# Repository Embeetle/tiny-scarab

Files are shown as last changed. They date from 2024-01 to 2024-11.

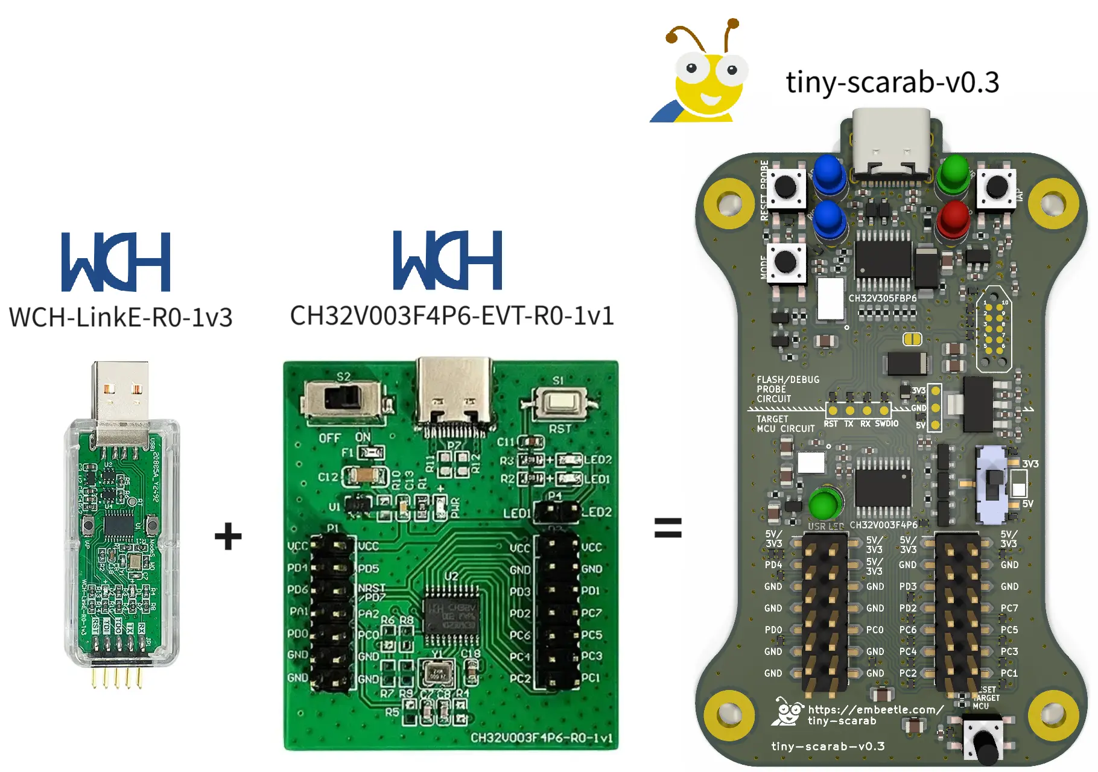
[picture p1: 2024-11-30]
documentation/website_figures/probe_and_board_merge.webp

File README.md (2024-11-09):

# Tiny Scarab

The Tiny Scarab is an open-source development board built around the popular 10 cent `CH32V003F4P6` RISC-V microcontroller from WCH. Using this dev board is uncomplicated: just plug it into your computer with a USB-C cable, and you're ready to code - the flasher/debugger is already embedded in the board for your convenience. Now you might wonder - why yet another dev board? Aren't there thousands already?



Well - this dev board is presented to you with a new coding IDE. Not satisfied with the current offering of IDEs for microcontrollers, we created a brand new one from scratch: <a href="https://embeetle.com/" target="_blank"> Embeetle IDE</a>. With the Tiny Scarab and Embeetle IDE, you'll discover how smooth programming a microcontroller can be.

>  This open-source dev board is developed in collaboration with the <a href="https://devheads.io/" target="_blank"> DevHeads</a> community. Please join the <a href="https://discord.gg/devheads">DevHeads Discord channel</a> if you want to know more about this Tiny Scarab board, Embeetle IDE or any other topic related to hardware and embedded software. We're waiting for you on the server!

&nbsp;<br>
# Overview

The Tiny Scarab is based on the 10-cent RISC-V `CH32V003F4P6` MCU from WCH:



The Tiny Scarab board merges the <a href="https://embeetle.com/#supported-hardware/wch/probes/wch-linke-r0-1v3" target="_blank">`WCH-LinkE-R0-1v3`</a> flash/debug probe and the <a href="https://embeetle.com/#supported-hardware/wch/boards/ch32v003f4p6-evt-r0-1v1" target="_blank">`CH32V003F4P6-EVT-R0-1v1`</a> board into a single development board:

comparison

There's no need to wire up anything. Just plug the Tiny Scarab's USB-C port in your computer, fire up Embeetle IDE and start coding!

&nbsp;<br>
# Index

- **Hardware**
  - [Download Tiny Scarab Schematic](tiny-scarab.pdf)
  - [Open Tiny Scarab in KiCAD](documentation/readme_open_project.md)
  - [A Deeper Dive in the KiCAD Files](documentation/readme_deeper_dive_kicad_files.md)
  - [Tiny Scarab Pinout and Features](documentation/readme_pinout_and_features.md)
  - [Tiny Scarab vs CH32V003F4P6-EVT-R0-1v1 - a Comparison](documentation/readme_compare.md)
  - [Production Files](documentation/production_files.md)

- **Software**
  - [Flash/Debug Probe Firmware](documentation/readme_flash_debug_probe_firmware.md)
  - [Target MCU Firmware](documentation/readme_target_mcu_firmware.md)

NOTES FOR MYSELF
================
Improvement points:
- Bulges in encasing don't fit board. (fixed)
- Tag Connect needs a recess in the enclosure. (fixed)
- Light bleeds between lightpipes. Lightpipes and LEDs too expensive. (fixed)
- Graphical membrane needs 1.2mm edge. (fixed)
- 3/5V indication on board is wrong. On graphical membrane it's correct. (fixed)

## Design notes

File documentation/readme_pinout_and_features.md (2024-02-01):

<a href="../README.md">open_project_01 HOME</a>

# Tiny Scarab Pinout and Features

## 1. Power System
The Tiny Scarab draws 5V power from its USB-C connector:



&nbsp;<br>
The 5V power rail is protected in several ways:



Let's go over all the safety measures.

&nbsp;<br>
### 1.1 ESD Protection
TVS diode `TVS3` (`SMAJ5.0A`) protects the board from incoming voltage transients and ESD discharges on the 5V line:



&nbsp;<br>
### 1.2 Overvoltage Protection
The TVS diode is ideal for short voltage transients - like an ESD discharge. But what about permanent overvoltage incidents? What if a faulty USB-C charger outputs 20V on the `VBUS` line? In that case, fuse `F1` (`MFU0603FF02000P500`) cooperates with zener diode `D1` (`1SMA4734A`) to protect the board:



Sometimes a faulty USB-C charger can output 20V on the `VBUS` line, even though it never negotiated this with the device on the receiving end. It shouldn't happen ... but when it does you don't want the board to go up in flames! Zener diode `D1` has a zener voltage of 5V6, so it will draw a lot of current in this particular case. Fuse `F1` blows, interrupting the current flow to prevent further damage.

&nbsp;<br>
### 1.3 Overcurrent Protection
Chip `U1` (`AP2141WG-7`) limits the current flow to the whole board at 500mA. This limit ensures that any PC can drive the board risk-free:



There's already a 2A fuse on the 5V line. Why don't we remove this `U1` chip and just reduce the 2A fuse to 500mA?

> open_project_01Fuse `F1` and current-limiting chip `U1` serve an entirely different purpose. Fuse `F1` (in collaboration with zener diode `D1`) protects the board from permanent overvoltage incidents. Replacing fuse `F1` with a 500mA version isn't a good idea because the on-resistance would be too high. Leaving out the fuse and only relying on current-limiting chip `U1` isn't smart either - a fuse is just perfect because of its simplicity and robustness. Summarized, the roles of fuse `F1` and chip `U1` are:
> - Fuse `F1`: simple and robust, ideal for the overvoltage incident described earlier.
> - Chip `U1`: more sophisticated, will limit current to 500mA while keeping a low on-resistance.

&nbsp;<br>
### 1.4 Power Indicator LEDs
The board has two LEDs to indicate the status of the 5V power input:



The `PWR` LED simply shows if 5V power is present on the board. The `ERR` LED lights up if the overcurrent protection chip `U1` reports a fault condition.

&nbsp;<br>
### 1.5 Voltage Conversion
Parts of the board - such as the flash/debug probe - operate on 3V3. So we need to create that voltage from the 5V rail:



The target MCU is a special case. It can operate on 5V *or* 3V3. Both voltages are present on the board, so it's easy to feed the chip with one or the other. To give you the choice, we added a slide switch:



Now, it's challenging to find a cheap slide switch that can carry 500mA and is readily available in the JLCPCB stock. For that reason, the slide switch simply toggles a few MOSFETs. In other words: the current doesn't flow through the slide switch, but through these MOSFETs instead. [Download the schematic](../tiny-scarab.pdf) to see more.

&nbsp;<br>
## 2. Pinout

Almost all pins of the target `CH32V003F4P6` MCU are accessible through the pin headers at the bottom of the board:



There are a few exceptions though. Signals `SWDIO_CH32V003` and `RST_CH32V003` (tied to pins `PD1` and `PD7`) are used to flash code to the target chip and run debug sessions. Also signals `RX` and `TX` (tied to pins `PD5` and `PD6`) are occupied. They are routed to the on-board flash/debug probe to provide UART communication:



Also pins `PA1` and `PA2` are not accessible on the pin headers. These are clock pins, routed to the crystal.

&nbsp;<br>
## 3. LEDs

[UNDER CONSTRUCTION]

&nbsp;<br>
## 4. Switches and Buttons

[UNDER CONSTRUCTION]

&nbsp;<br>
<a href="../README.md#index"> GO BACK</a>

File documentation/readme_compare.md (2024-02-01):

<a href="../README.md">open_project_01 HOME</a>

# Tiny Scarab vs CH32V003F4P6-EVT-R0-1v1 - a Comparison

With a few exceptions, the Tiny Scarab pinout is identical to the `CH32V003F4P6-EVT-R0-1v1` development board:



The exceptions are:

- Pins `PA1` and `PA2` are used to drive the crystal. The `CH32V003F4P6-EVT-R0-1v1` board still breaks them out to the pin headers, but you then have to remove the crystal and solder two 0R resistors. We don't expect our users will make any modifications to the board, so we decided to leave out that option. The corresponing pins on the pin headers are just tied to `GND`.

- Pins `PD1`, `PD5`, `PD6` and `PD7` are connected to the `CH32V305FBP6` chip for flash and debug purposes (the `CH32V305FBP6` is the heart of the on-board `WCH-LinkE-R0-1v3` flash/debug probe). It is safer not to connect them to the pin headers.

&nbsp;<br>
<a href="../README.md#index"> GO BACK</a>

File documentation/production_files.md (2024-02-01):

<a href="../README.md"> HOME</a>

# Production Files

This board is designed with JLCPCB in mind for the production. That's why all components are selected to be in stock or at least accessible at <a href="https://jlcpcb.com/" target="_blank">JLCPCB</a>. In the schematic, you'll notice that each component has a `JLCPCB Part #` field:



Based on this part number, JLCPCB knows which exact component to select from its stock. On this page, we cover how to output all the required production files from this KiCAD project for manufacturing the board at JLCPCB - both the board production and assembly.

>  Note: as you can see, not only the `JLCPCB Part #` field is provided for each component. We also added fields for other distributors, like `DigiKey`, `Farnell` and `Mouser`.

&nbsp;<br>
## 1. Install JLCPCB Plugin

First install the JLCPCB plugin in KiCAD:



&nbsp;<br>
Search for the `"JLC PCB Fabrication Toolkit"`:



&nbsp;<br>
Install the plugin.

&nbsp;<br>
## 2. Generate Production Files

Once you've installed the JLCPCB plugin, you should see a new button in the PCB Layout Window:



&nbsp;<br>
This button replaces the usual workflow to generate production files. In other words, do not generate files from `File` > `Fabrication Outputs`:



&nbsp;<br>
Just click the new JLCPCB button instead. You'll be prompted the following question:



Make sure to check the `"Exclude DNP components"` box. "DNP" stands for "Do Not Place". By checking this box, you ensure that the components marked as "DNP" are indeed not placed on the board.

&nbsp;<br>
The KiCAD plugin should now create a new folder named `production` in the Tiny Scarab project. This is all you need for production at the JLCPCB manufacturing plant.

&nbsp;<br>
<a href="../README.md#index"> GO BACK</a>

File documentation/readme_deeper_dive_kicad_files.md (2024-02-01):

<a href="../README.md"> HOME</a>

# A Deeper Dive in the KiCAD Files

All the files in this GitHub repository work together to create the entirety of the KiCAD project. Roughly speaking, these files can be grouped in four categories:

open_project_01

&nbsp;<br>
##  KiCAD Component Library

KiCAD libraries come in two kinds: global and project libraries.
 - Global libraries are available for each and every project you work on. Let's not mess with them.
  - For the customized components, we created a project library: `Tiny_Scarab.kicad_sym`. When you launch the Tiny Scarab project in KiCAD, the software should automatically recognize the presence of this project library and find all the components inside. To keep things simple, all the customized components are located in this one project library.

The project library is stored in the file `Tiny_Scarab.kicad_sym`. Well, that is, all the schematic symbols are stored in there with their footprint *references*. The footprints themselves are located in the `Tiny_Scarab.pretty` folder. The 3D models from these footprints are in the `3d_models` folder. So you could state that these three items together (the `Tiny_Scarab.kicad_sym` file, the `Tiny_Scarab.pretty` folder and the `3d_models` folder) compose our project library.

Then what are the `fp-lib-table` and `sym-lib-table` files for? They simply help KiCAD to know where to find the footprints and symbols from (one or more) project libraries. In our KiCAD project, it's pretty simple because there's only a single project library. But these two files come in handy if things would be more complicated.

&nbsp;<br>
##  KiCAD Schematic Pages

The Tiny Scarab KiCAD project consists of several schematic pages. The root page is `tiny-scarab.kicad_sch` - it has the same name as the project file `tiny-scarab.kicad_pro` (which represents the entire project). Then there is the `USB.kicad_sch`, `WCH-LinkE-R0-1v3.kicad_sch` and two more. You can view these pages from within the Schematic Editor in KiCAD:



&nbsp;<br>
> *Note: in the most recent version of the Tiny Scarab, you'll notice a few extra schematic pages.*

&nbsp;<br>
##  KiCAD PCB Layout

The PCB Layout is stored in a single file: `tiny-scarab.kicad_pcb`.

&nbsp;<br>
##  KiCAD Project

The entire KiCAD project is represented by `tiny-scarab.kicad_pro`. This file tells KiCAD how to open the project and where to find all the files.

&nbsp;<br>
<a href="../README.md"> GO BACK</a>

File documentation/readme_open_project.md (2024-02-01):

<a href="../README.md">open_project_01 HOME</a>

# Open Tiny Scarab Project in KiCAD

The Tiny Scarab development board is designed in KiCAD - a free and open-source tool to draw professional circuit boards. On this page I explain how to open the Tiny Scarab dev board project in KiCAD.

&nbsp;<br>
## STEP 1: Clone or Download Tiny Scarab

First you need to clone or download the Tiny Scarab GitHub repository. Navigate back to <a href="../README.md">the homepage</a>, then click the green `<> Code` button and copy the GitHub URL or just download the zip folder:

open_project_01

If you copied the GitHub URL, you can then clone it to your local computer like this:

```sh
$ git clone https://github.com/Embeetle/tiny-scarab.git
```

If you downloaded the zip-folder - just unzip it.

&nbsp;<br>
## STEP 2: Download KiCAD

Make sure you have `KiCAD v7` or higher. Download and install the software from here:
<a href="https://www.kicad.org/" target="_blank">https://www.kicad.org/</a>

open_project_02

&nbsp;<br>
## STEP 3: Launch KiCAD

Launch KiCAD. First window you see is the **KiCAD Home Window**. Click `File` > `Open Project...` and select the `tiny-scarab.kicad_pro` file from the GitHub repository you just downloaded or cloned in STEP 1:

open_project_03

open_project_04

&nbsp;<br>
That's it. Now you can work in the **Tiny Scarab** project in KiCAD:

open_project_05

&nbsp;<br>
<a href="../README.md"> GO BACK</a>

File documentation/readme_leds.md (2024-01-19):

<a href="../README.md"> HOME</a>

# LEDs

 The CSL Series from Rohm Semicon (see https://www.rohm.com/products/led/chip-leds-mono-color-type) is a series of 0603 SMD LEDs with a lens for extra luminosity.

## 1. CSL Series Product Code

```
┌─────────────┐     ┌────────┐   ┌────────┐   ┌───┐   ┌───┐
│ C    S    L │  -  │ 0    9 │   │ 0    2 │   │ B │   │ T │
└──┬──────────┘     └─┬──────┘   └─┬──────┘   └─┬─┘   └─┬─┘
  series           package       brightness   color    resin color
                   1.6x0.8mm     03>02>01     U:Red    T:Transparent
                   t=1.24mm                   D:Orange
                                              Y:Yellow
                                              M:Yellow-Green
                                              E:Green
                                              B:Blue
                                            
```

## 2. Table

| part | color | mcd  | luminous classification | I<sub>F</sub> @ V<sub>F</sub> | I<sub>F</sub> @ V<sub>F</sub> | Mouser | Farnell |
|---|---|---|---|---|---|---|---|
| `CSL0902UT` | RED | 355  | AZ>AY>AX>AW | `20mA` @ `2V1 [1V8-2V5]` | `10mA` @ `2V0` | `755-CSL0902UT1` | 3954422 |
| `CSL0902DT` | ORANGE | 560  | BB>BA>AZ>AY | `20mA` @ `2V1 [1V8-2V5]` | `10mA` @ `2V0` | `755-CSL0902DT1` | 4129804 |
| `CSL0902MT` | YELLOW-GREEN | 180  | AW>AV>AU>AT | `20mA` @ `2V1 [1V8-2V5]` | `10mA` @ `2V0` | `755-CSL0902MT1` | 4129806 |
| `CSL0902ET` | GREEN | 1100 | Y1>X2>X1>W2 | `20mA` @ `3V4 [2V6-3V8]` | `10mA` @ `3V2` | `755-CSL0902ET1` | 4129807 |
| `CSL0902BT` | BLUE | 360  | V2>V1>U2>U1 | `20mA` @ `3V3 [2V6-3V8]` | `10mA` @ `3V1` | `755-CSL0902BT1` | 3954417 |

&nbsp;<br>
<a href="../README.md"> GO BACK</a>

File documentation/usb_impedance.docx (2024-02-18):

# USB Impedance

In a differential pair, there exists four kinds of characteristic impedance:

- Single-ended impedance ( Z_(se) ): The impedance of the single trace in isolation, when it's excited by a signal between the trace and the ground plane. In single-ended signaling, this is the only kind of impedance.
- Odd-mode impedance ( Z_(odd) ): The impedance of the single trace in a differential pair, when the differential pair as a whole is excited by a differential-mode (out of phase) signal.
- Even-mode impedance ( Z_(even) ): The impedance of the single trace in a differential pair, when the differential pair as a whole is excited by a common-mode (in phase) signal.
- Differential impedance ( Z_(diff) ): The impedance of the entire differential pair as a whole (two traces), when the differential pair as a whole is excited by a differential-mode (out of phase) signal. By definition, it's always 2⋅Zodd.

https://electronics.stackexchange.com/questions/311310/understanding-usb-differential-and-single-ended-impedance-requirements

In the context of USB signal routing on a printed circuit board (PCB), differential pairs are used to transmit data signals. These pairs consist of two conductive traces that carry the same signal but with opposite polarities, which helps to reduce noise and electromagnetic interference (EMI), improving signal integrity. The way these differential pairs are routed—whether as tightly-coupled or loosely-coupled—can significantly affect their performance. Here's a detailed explanation of both concepts:

### Tightly-Coupled Differential Pairs

- **Definition:** In tightly-coupled differential pairs, the two traces are placed very close to each other relative to their distance from the reference plane (usually a ground or power plane within the PCB). This close proximity enhances the coupling between the traces.

- **Benefits:** The strong electromagnetic coupling between the traces in a tightly-coupled pair reduces the impact of external noise and EMI, making them more immune to interference. It also decreases the differential impedance and increases the phase velocity of the signal, which can be beneficial for maintaining signal integrity over longer distances.

- **Design Considerations:** To achieve tight coupling, designers must consider the trace width, the spacing between the traces, and the thickness of the PCB substrate. The goal is to maintain a consistent impedance while minimizing the space the pair occupies on the PCB. This often requires precise control over the manufacturing process to ensure that the spacing and widths remain within tight tolerances.

- **Applications:** Tightly-coupled differential pairs are typically used in high-speed data communication applications where signal integrity is critical, such as USB 3.0/3.1, HDMI, and Ethernet.

### Loosely-Coupled Differential Pairs

- **Definition:** Loosely-coupled differential pairs have a greater distance between the two traces compared to their distance from the reference plane. This results in weaker electromagnetic coupling between the traces.

- **Benefits:** Loosely-coupled pairs are easier to route on PCBs, especially in complex designs where space is a constraint or when traces need to navigate around obstacles. They are less susceptible to manufacturing variations since the wider spacing is more tolerant to deviations in trace width or spacing.

- **Design Considerations:** While easier to implement, loosely-coupled pairs may require additional design considerations to maintain signal integrity, such as impedance matching and controlling the length of the traces to prevent timing mismatches. The reduced coupling can make them more susceptible to external noise and EMI.

- **Applications:** Loosely-coupled differential pairs are often used in applications where the speed of the data transmission is lower, or the design complexity and PCB real estate do not allow for tightly-coupled routing. They can still be effective in USB 2.0 and other lower-speed interfaces.

### Conclusion

The choice between tightly-coupled and loosely-coupled differential pairs depends on the specific requirements of the USB interface (such as the data rate), the available PCB space, and the desired resilience against noise and EMI. Tightly-coupled pairs are generally preferred for high-speed data transmission due to their superior signal integrity, but they require more precise manufacturing and design. Loosely-coupled pairs offer more flexibility in routing and are more tolerant to manufacturing variations, making them suitable for lower-speed or more complex PCB designs.

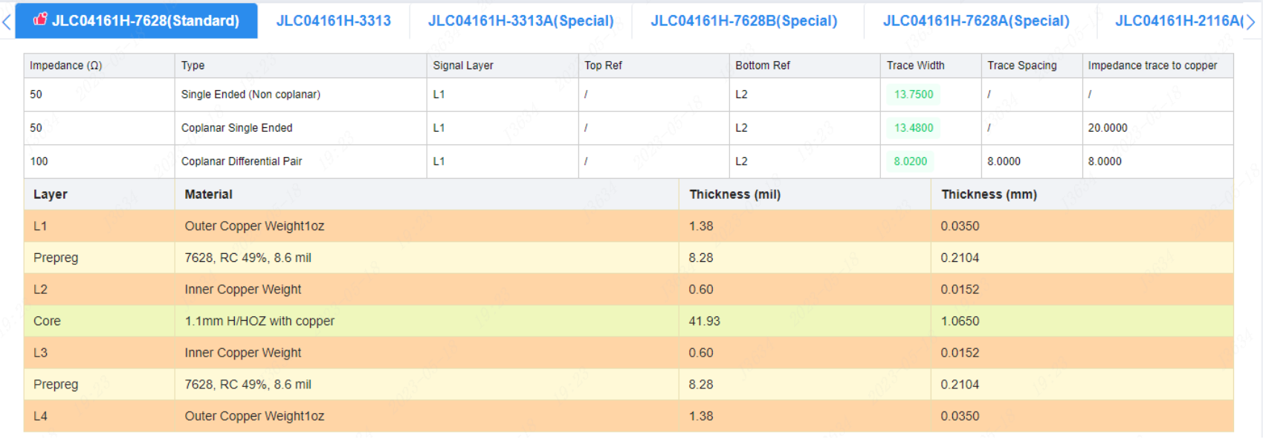
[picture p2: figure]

(Prepreg 7628 has a relative permittivity ϵr around 4.6, assuming standard FR-4 material unless specified otherwise)

When designing a PCB with JLCPCB and using their standard FR4 material (Tg 140C), it's important to note that this material is widely used in the industry and typically has a dielectric constant (ϵr) around 4.3 to 4.8 for frequencies relevant to USB signal transmission. For our calculations and considerations, we'll use an average value of 4.6, which is a common approximation for FR4 material unless JLCPCB provides a specific dielectric constant value for their FR4-Standard Tg 140C material.

I have a 4-layer PCB with the following stackup:

```

L1 Copper: 0.035mm thick

Prepreg: 0.2104mm thick

L2 Copper: 0.0152mm thick

Core Material: 1.065mm thick

L3 Copper: 0.0152mm thick

Prepreg: 0.2104mm thick

L4 Copper: 0.035mm thick

```

Assume the permittivity of the Prepreg and Core Material to be 4.6.

The manufacturing constraints are:

- Minimal trace width: 0.2mm

- Minimal spacing between traces: 0.2mm

I want to route a differential pair of USB signals. I will put them on layer L2 and sandwich them between a GND plane on layer L1 and a GND plane on layer L3.

If the USB signals have a width of 0.2mm and are spaced 0.2mm apart, what would be their differential impedance?

To calculate the differential impedance of a differential pair of USB signals with the given stackup and constraints, we can use an appropriate model or formula for differential pairs. One commonly used approximation for differential impedance (\(Z_{diff}\)) of a pair of traces in a PCB is given by:

\[ Z_{diff} = 2 \times Z_0 \times \sqrt{1 + \frac{d}{s + 2h}} \]

where:

- \(Z_0\) is the single-ended impedance of one trace,

- \(d\) is the distance between the centers of the two traces (i.e., the sum of the trace width and the spacing between the traces),

- \(s\) is the spacing between the traces, and

- \(h\) is the height of the dielectric material above the reference plane.

First, we need to calculate the single-ended impedance (\(Z_0\)) of one trace using the microstrip model, as the differential pair is routed on layer L2 with ground planes on both L1 and L3. The formula for the impedance of a microstrip is more complex and depends on the width of the trace (\(W\)), the thickness of the dielectric (\(H\)), the permittivity of the dielectric (\(\epsilon_r\)), and other factors. A simplified version of the formula can be:

\[ Z_0 = \frac{87}{\sqrt{\epsilon_r+1.41}} \cdot \ln\left( \frac{5.98H}{0.8W + T} \right) \]

where:

- \(W\) is the trace width,

- \(H\) is the height above the reference plane (thickness of the dielectric),

- \(T\) is the thickness of the trace, and

- \(\epsilon_r\) is the relative permittivity of the dielectric material.

Given:

- \(W = 0.2\,mm\) (trace width),

- \(H = 0.2104\,mm\) (thickness of the Prepreg above L2),

- \(T = 0.0152\,mm\) (thickness of L2 Copper),

- \(\epsilon_r = 4.6\) (permittivity of the Prepreg and Core Material),

- \(s = 0.2\,mm\) (spacing between the traces).

Let's calculate the single-ended impedance (\(Z_0\)) and then the differential impedance (\(Z_{diff}\)).

The calculated single-ended impedance (\(Z_0\)) of one trace is approximately \(30.39 \, \Omega\), and the differential impedance (\(Z_{diff}\)) of the USB signal pair, with each having a width of \(0.2 \, mm\) and spaced \(0.2 \, mm\) apart, is approximately \(77.93 \, \Omega\).

This differential impedance is within the typical range for USB differential pair signaling, which often aims for around \(90 \, \Omega\) in differential impedance, but variations can be acceptable depending on the specific USB standard and the tolerances allowed by the system design.

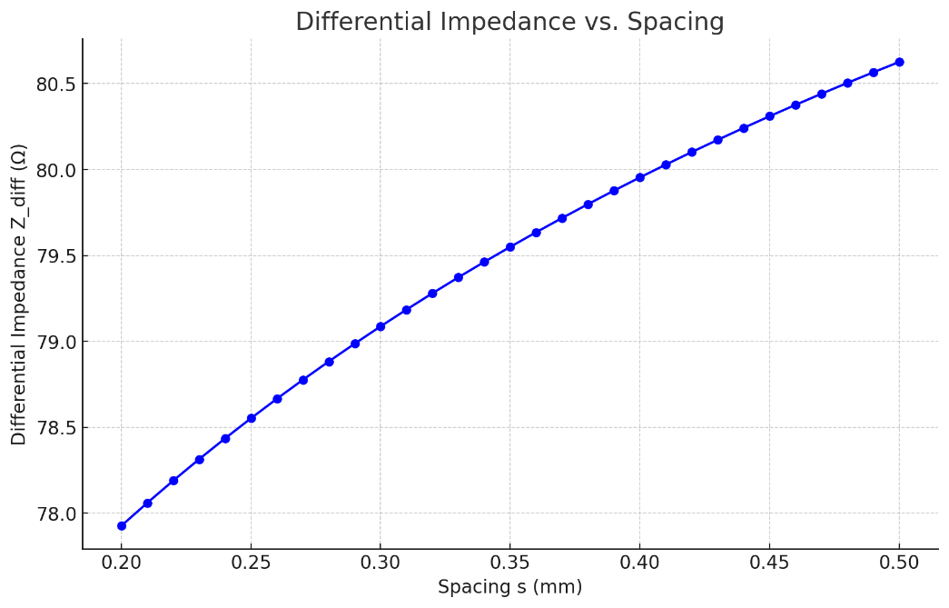
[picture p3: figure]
Output image
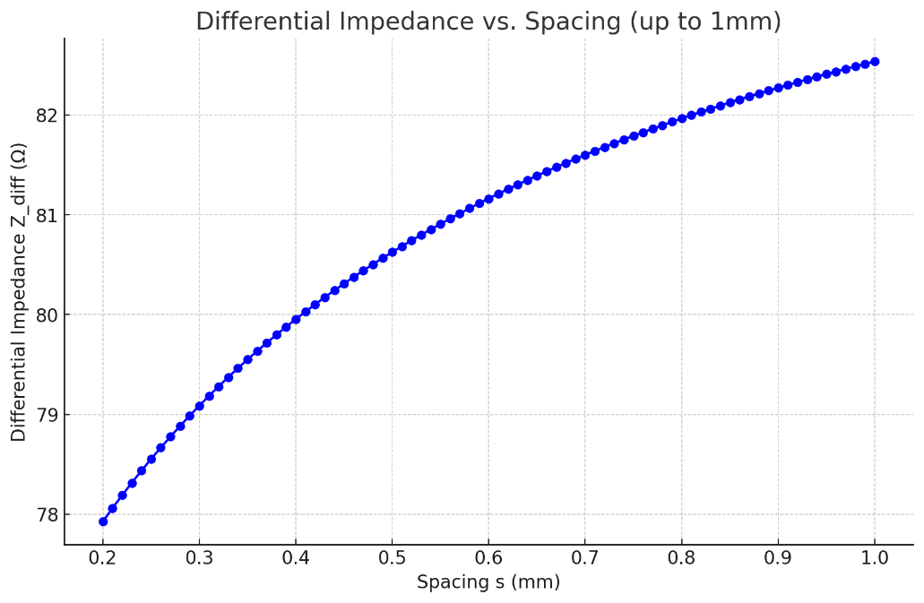
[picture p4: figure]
Output image

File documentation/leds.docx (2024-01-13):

# Tiny Scarab LEDs

The LEDs on the Tiny Scarab board have these characteristics:

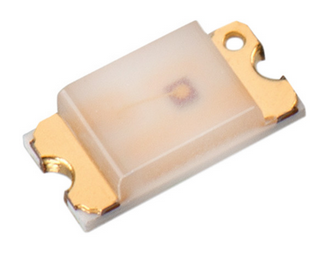
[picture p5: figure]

- Manufacturer: Würth Elektronik
- Package: 0603 SMD
- Lens: Diffused
- Viewing Angle: 140 deg

# Green

MPN: 150060GS55040
SPN: 732-12014-2-ND

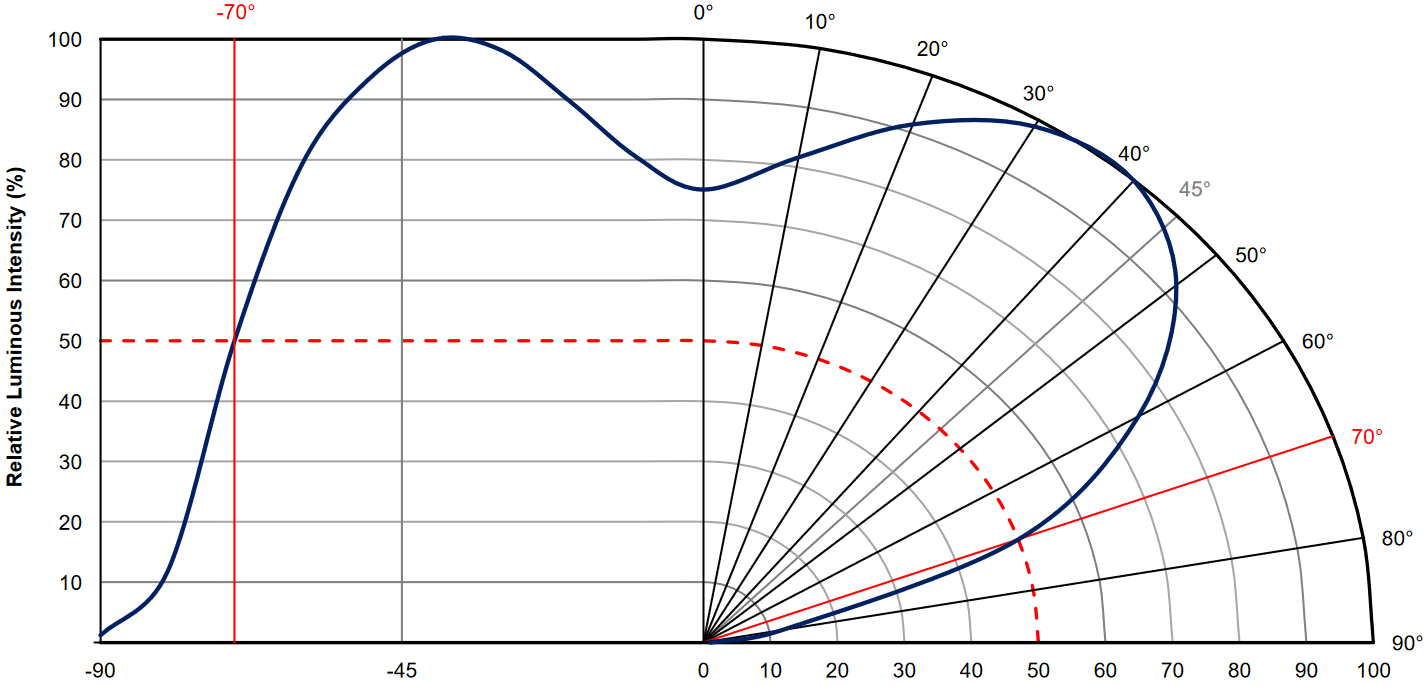
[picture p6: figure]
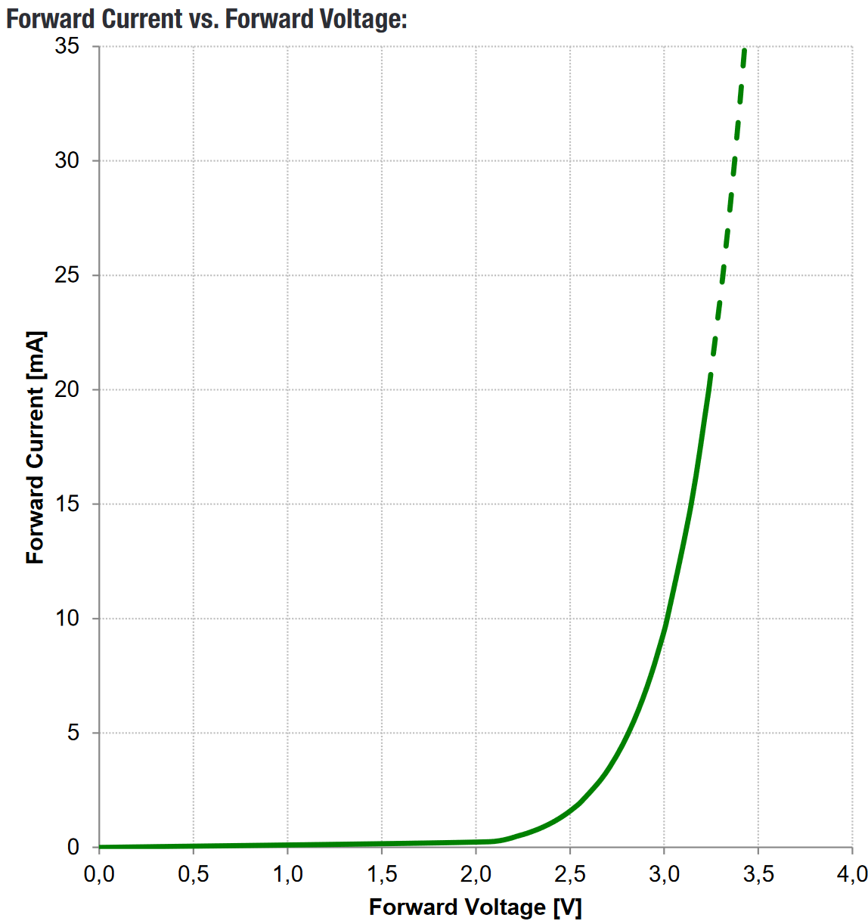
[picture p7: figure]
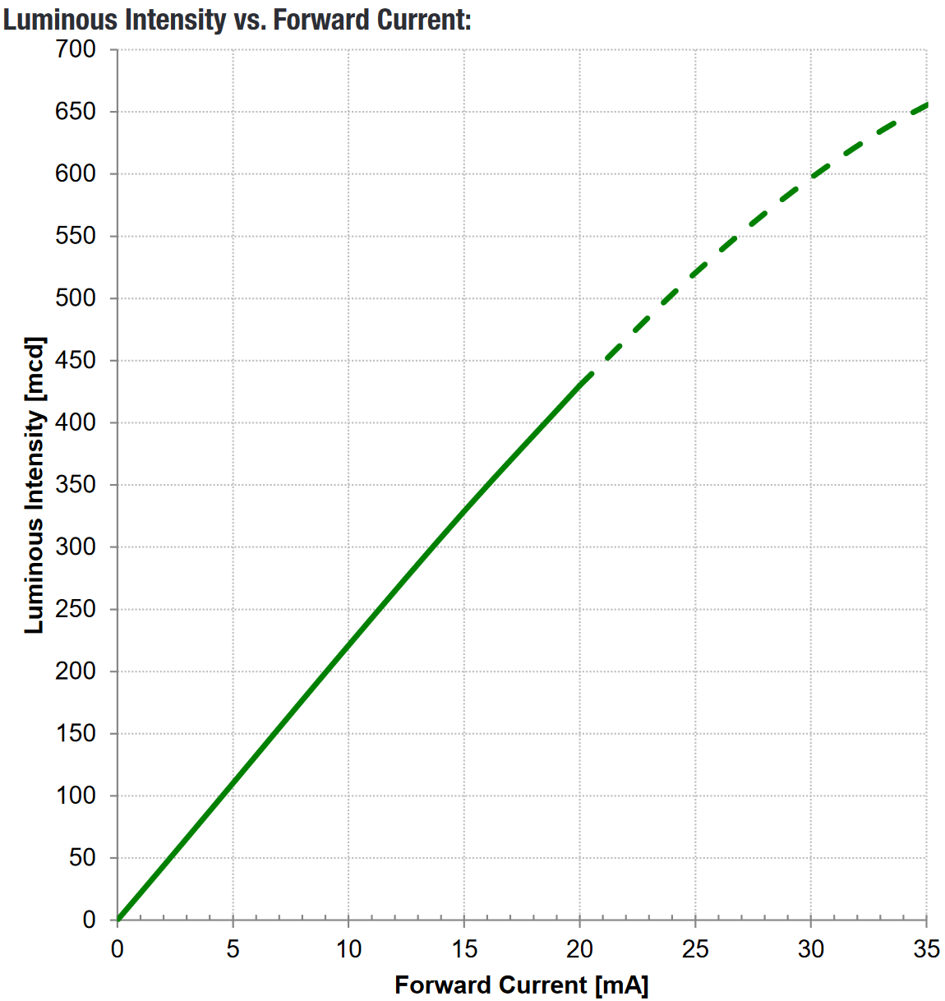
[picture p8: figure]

10mA

3V00

# Red

MPN: 150060RS55040
SPN: 732-12015-2-ND

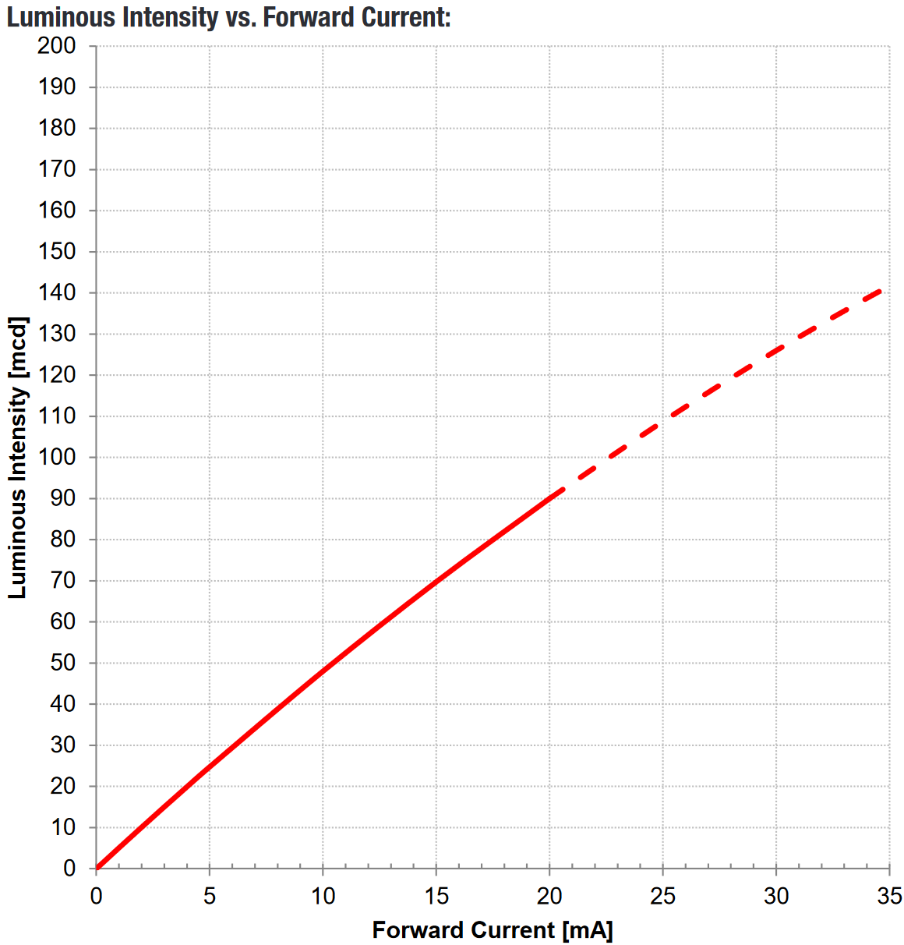
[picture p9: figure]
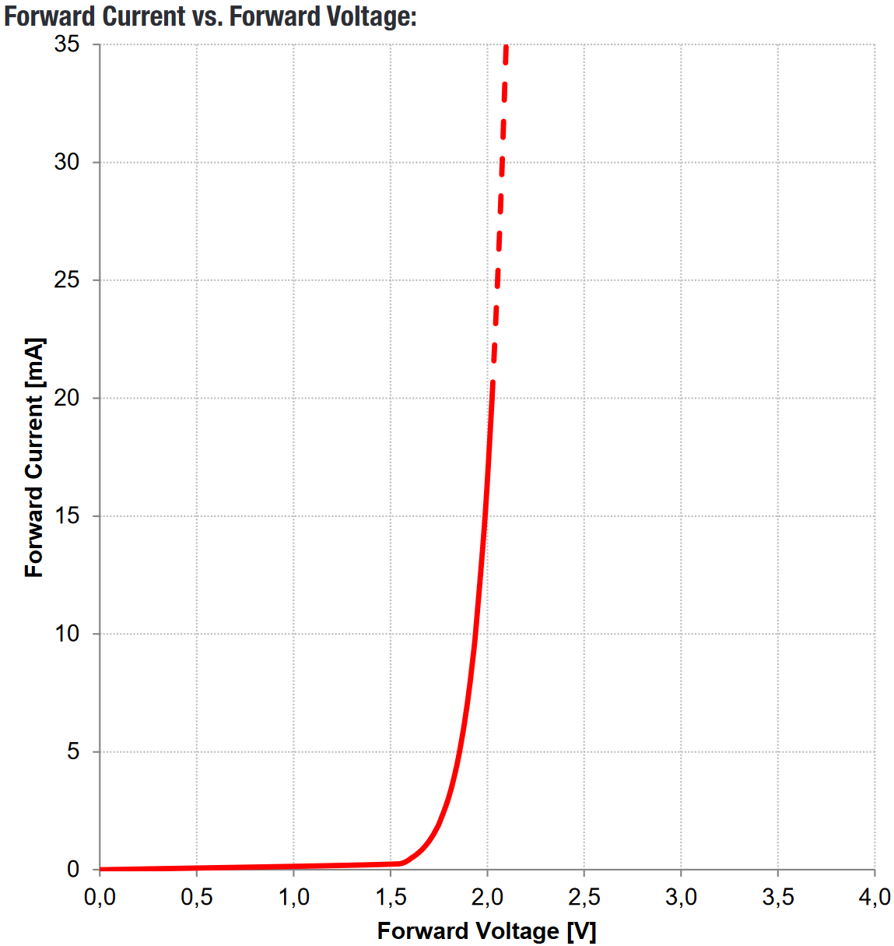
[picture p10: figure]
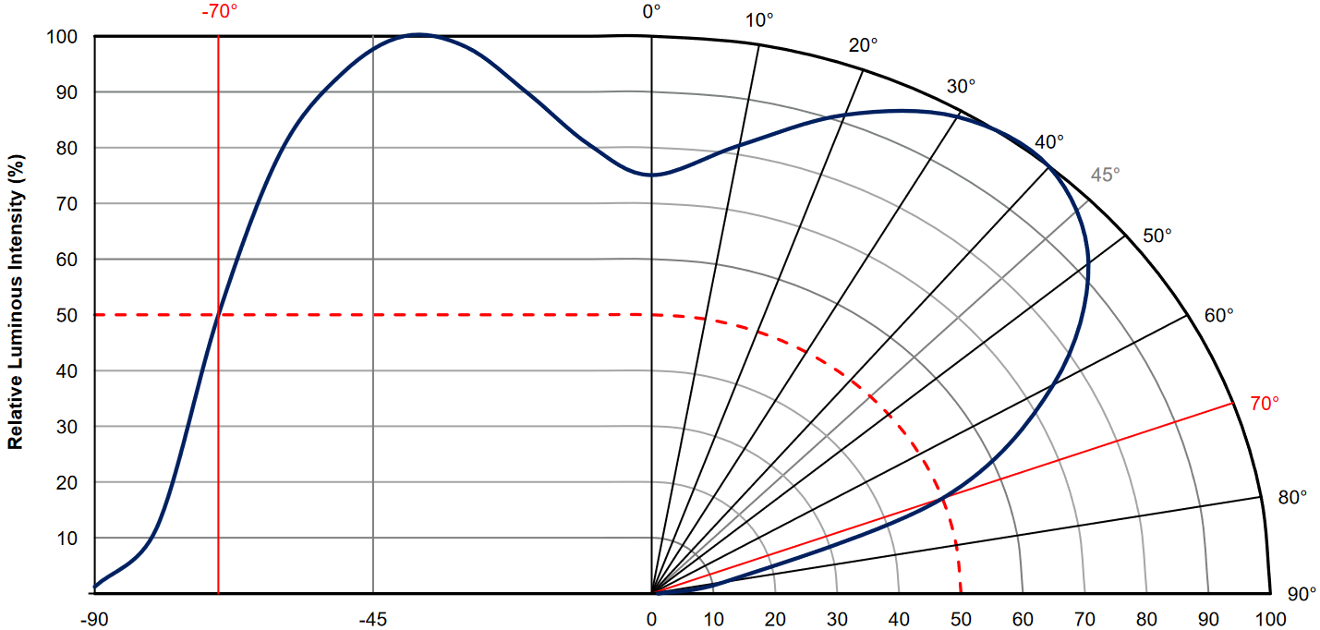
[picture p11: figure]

10mA

1V90

# Yellow

MPN: 150060YS55040
SPN: 732-12018-2-ND

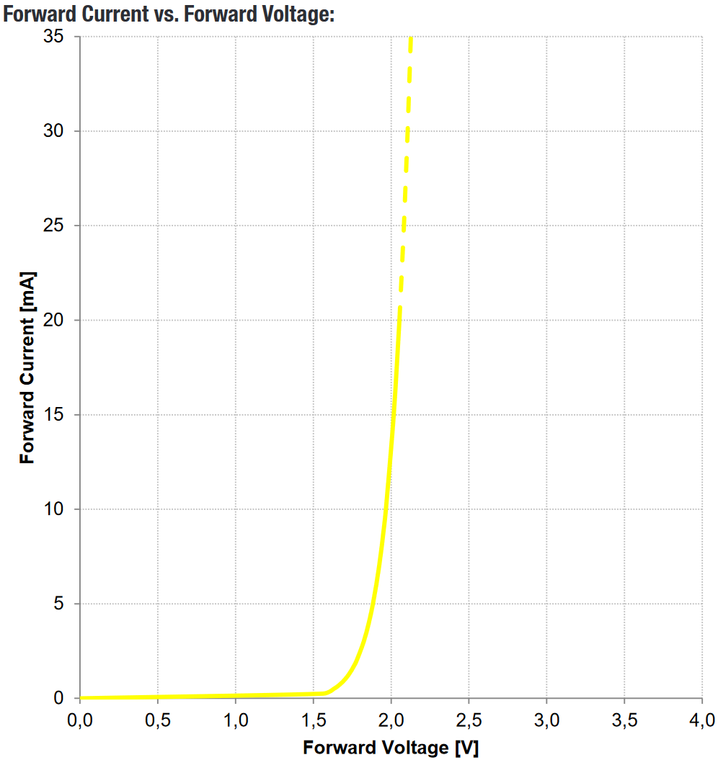
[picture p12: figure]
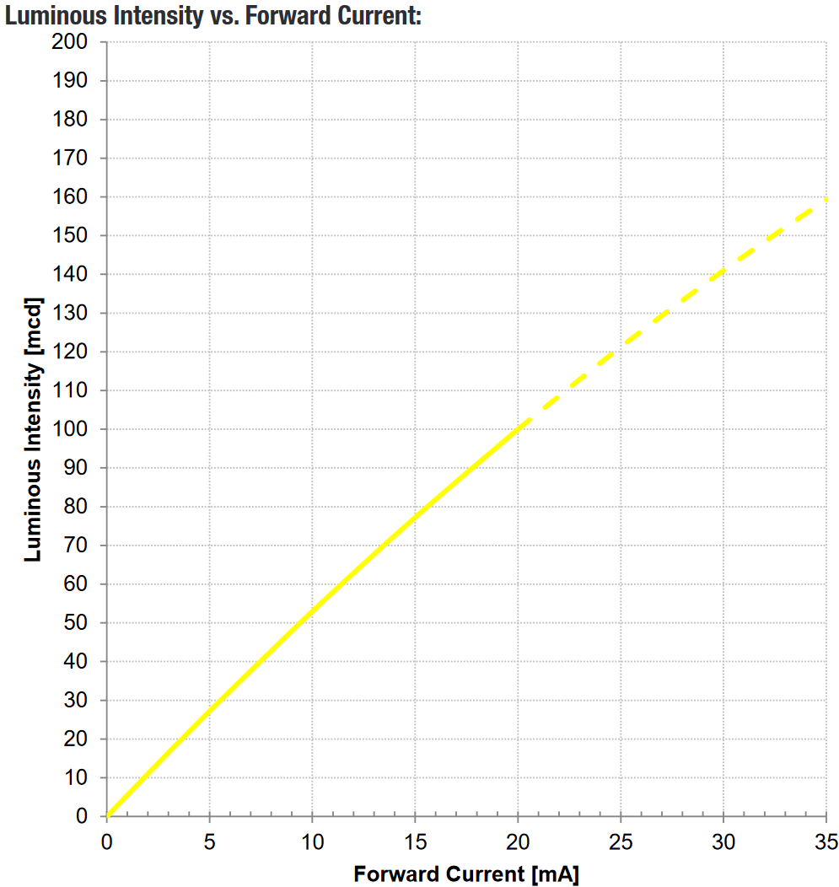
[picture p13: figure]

10mA

1V95

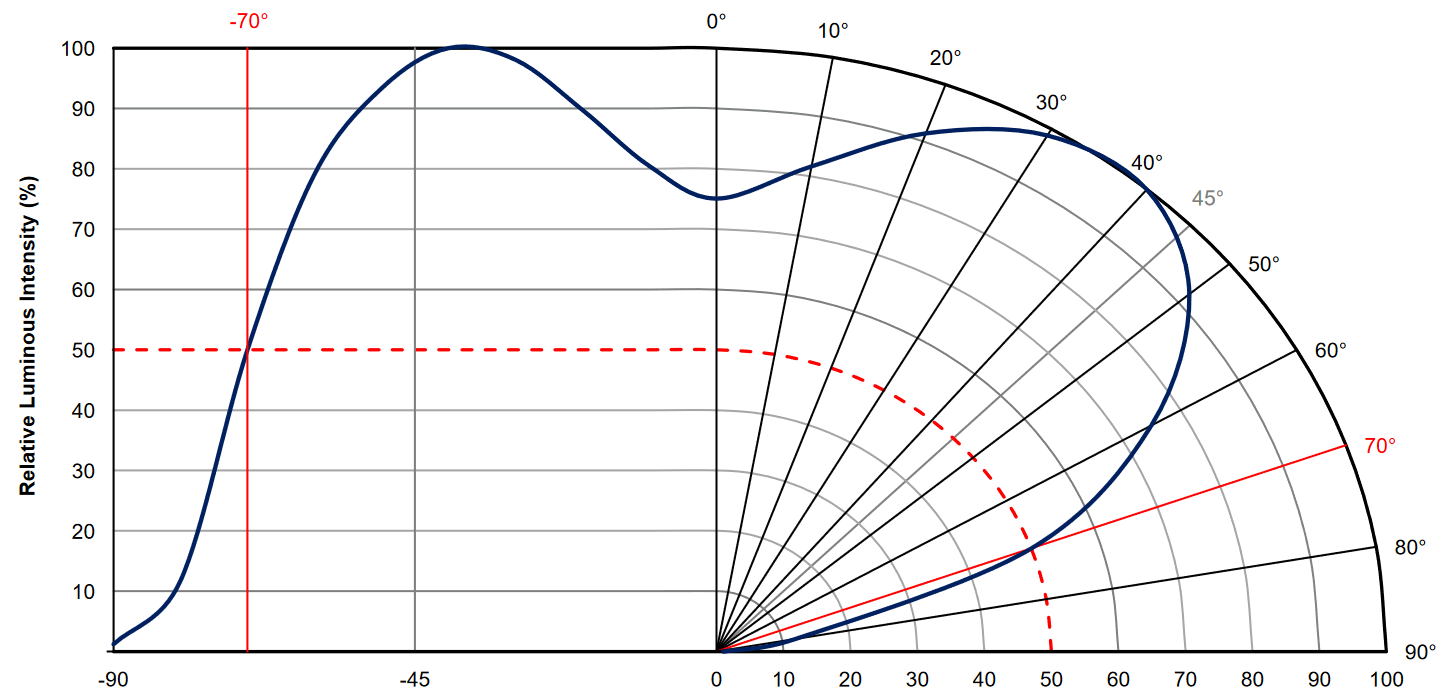
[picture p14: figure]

# Blue

MPN: 150060BS55040
SPN: 732-12013-2-ND

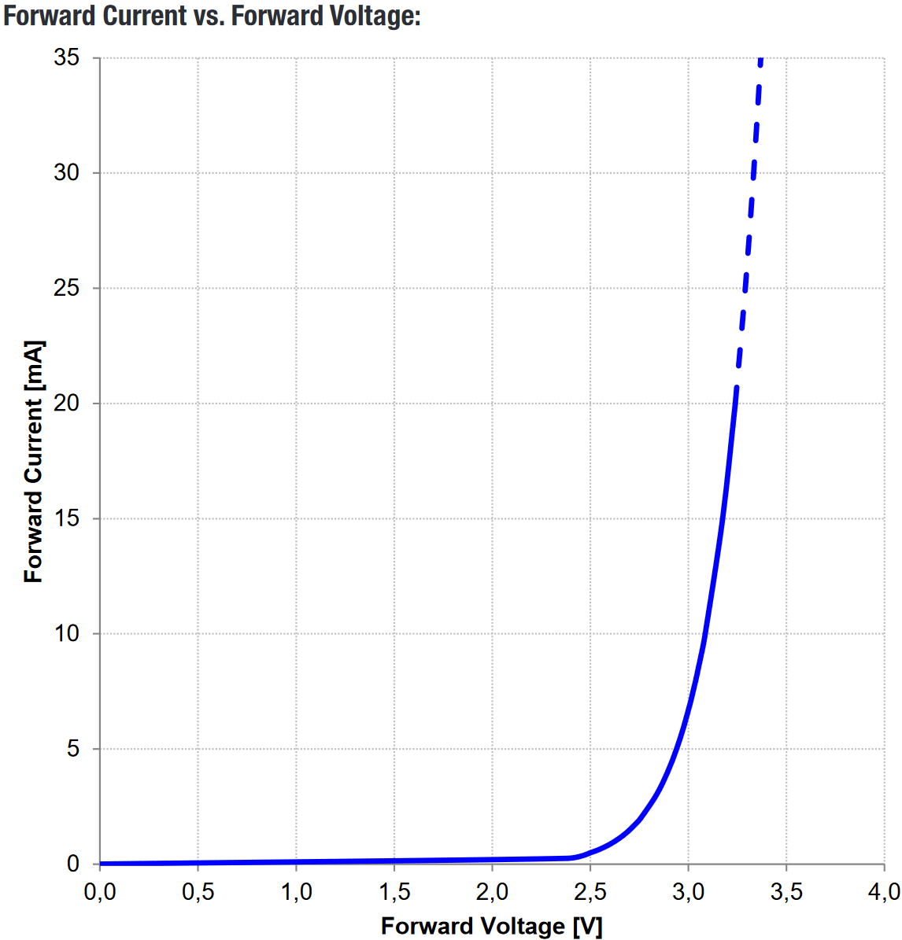
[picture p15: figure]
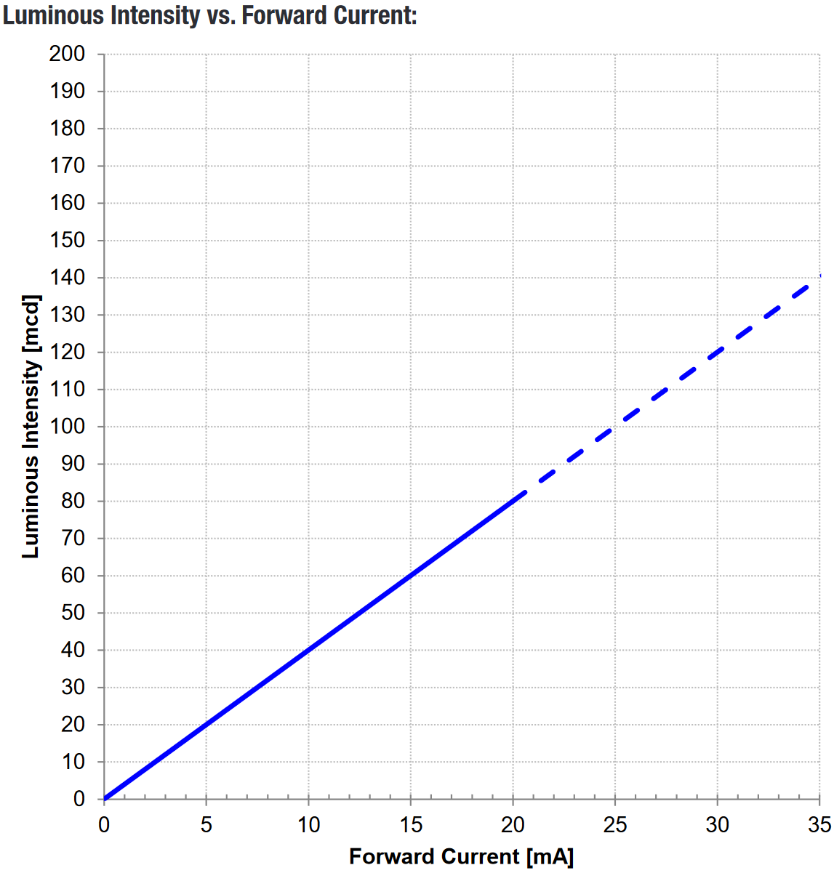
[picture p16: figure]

10mA

3V10

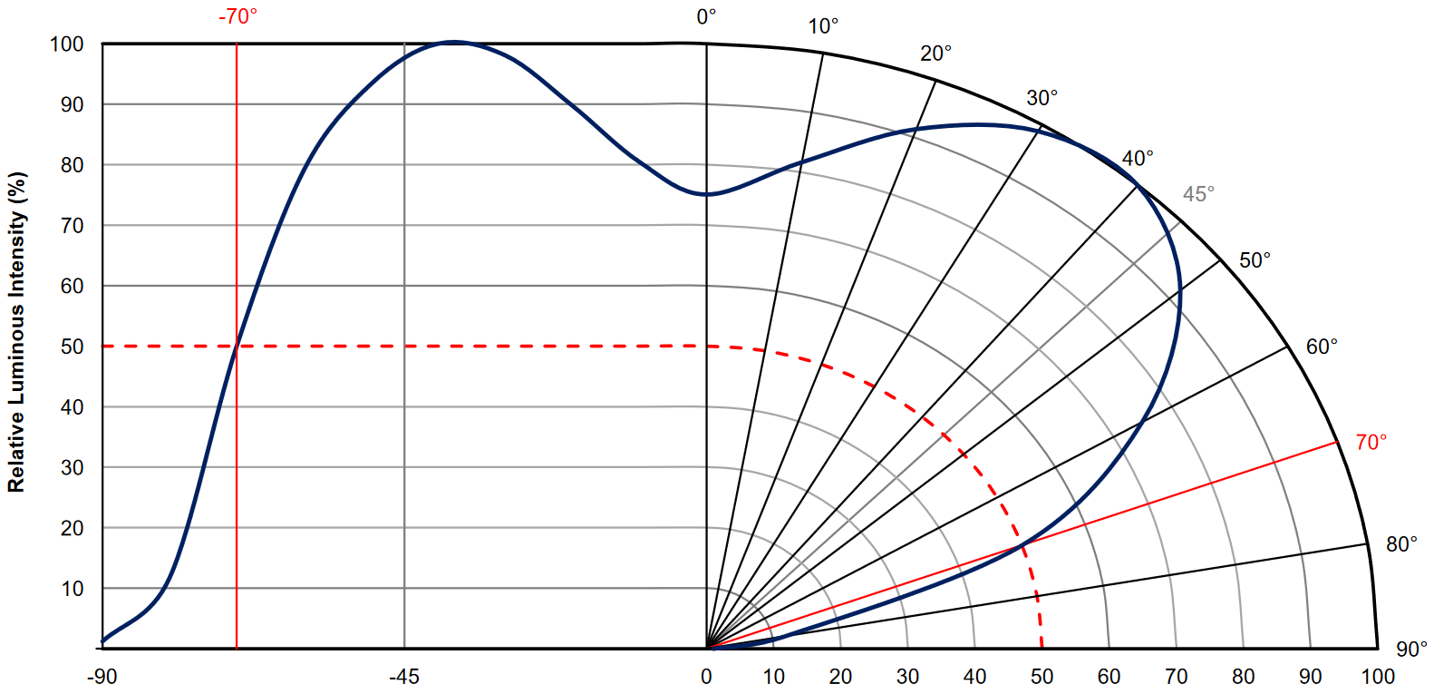
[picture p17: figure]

LED Color | Voltage @10 mA | Resistor @5V | GPN | Resistor @3V3 | GPN
Green | 3V00 | 200Ω | GPR0402200R | 30Ω | GPR040230R
Red | 1V90 | 310Ω (~300Ω) | GPR0402300R | 140Ω (~150Ω) | GPR0402150R
Yellow | 1V95 | 305Ω (~300Ω) | GPR0402300R | 135Ω (~130Ω) | GPR0402130R
Blue | 3V10 | 190Ω (~180Ω) | GPR0402180R | 20Ω | GPR040220R

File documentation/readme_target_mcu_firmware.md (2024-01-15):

<a href="../README.md"> HOME</a>

# Target MCU Firmware

This page explains how to flash firmware to the target MCU on your Tiny Scarab board.

[PAGE UNDER CONSTRUCTION]

&nbsp;<br>
<a href="../README.md#index"> GO BACK</a>

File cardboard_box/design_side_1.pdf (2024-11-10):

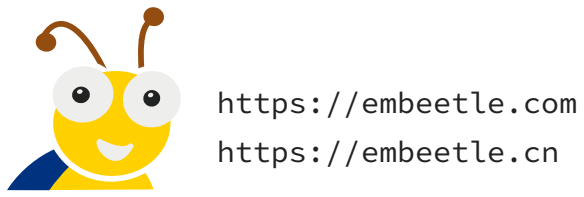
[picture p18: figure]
https://embeetle.com; https://embeetle.cn

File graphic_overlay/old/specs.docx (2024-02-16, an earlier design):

# Graphic Overlay Specifications

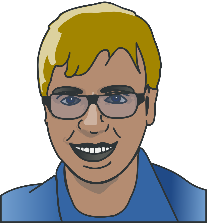
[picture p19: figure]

I’m Kristof Mulier, a Belgian electronics engineer and cofounder of Embeetle IDE. We’re developing a product, but still need a graphic overlay membrane in PET (Polyester), PC (Polycarbonate) or another elastomer material. For this graphic overlay membrane, we would like to cooperate with your company. This document clarifies what we need.

## Our Product

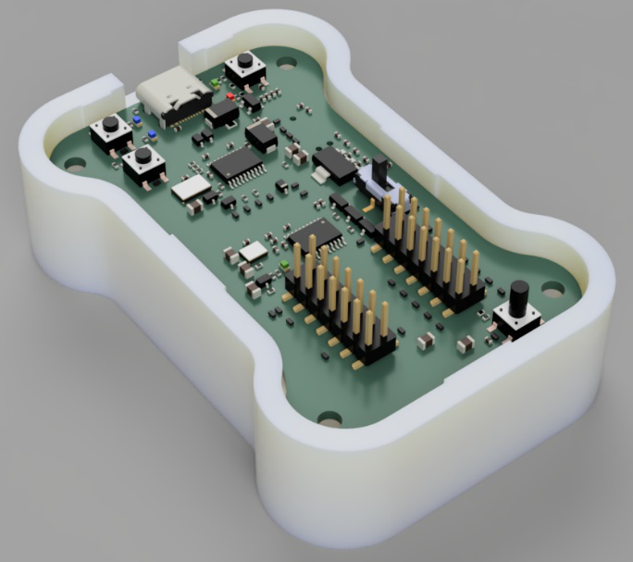
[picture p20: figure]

The product consists of a circuit board mounted with bolts in a plastic box:

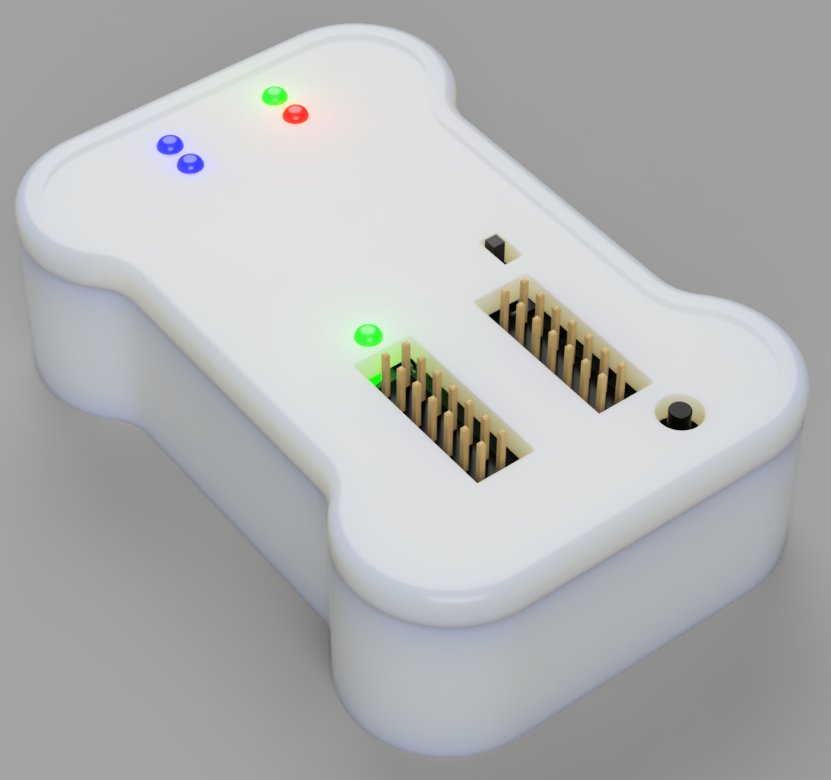
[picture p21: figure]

The cover has a few holes for the buttons, slide switches and LEDs. The circuit board is mounted just 4mm below the surface, so some of these components stick out through the holes in the cover:

## Overview

We need a graphic overlay membrane to glue on top of our product’s cover:

LED hole

⌀ 3mm*

pushbutton

⌀ 5.00mm

slider switch slot

2.50 x 4.50mm

pin header slot

7.20 x 20.0mm

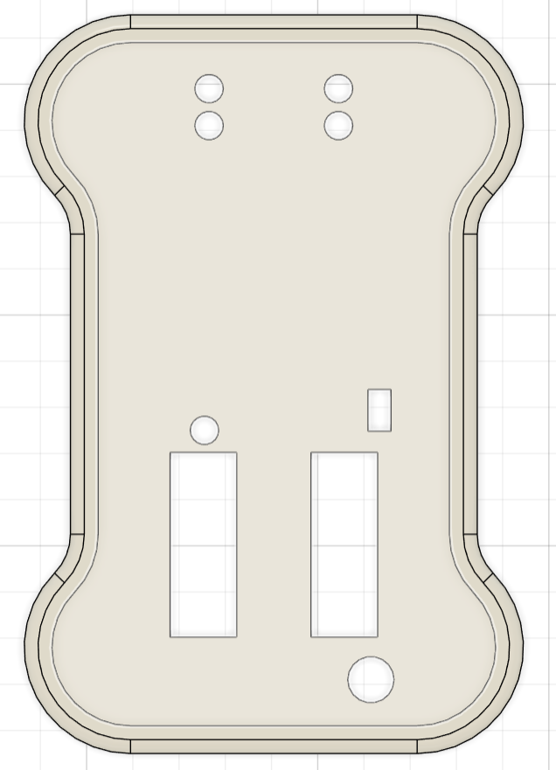
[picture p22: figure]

This is what we envision the graphic overlay membrane to look like. The hatched areas are holes and cutouts in the membrane to give space for the LEDs, slider switch and pin header connectors that poke through the cover. For the pushbutton, no hole should be drilled in the membrane! Instead, the membrane should cover the pushbutton (see page 8).

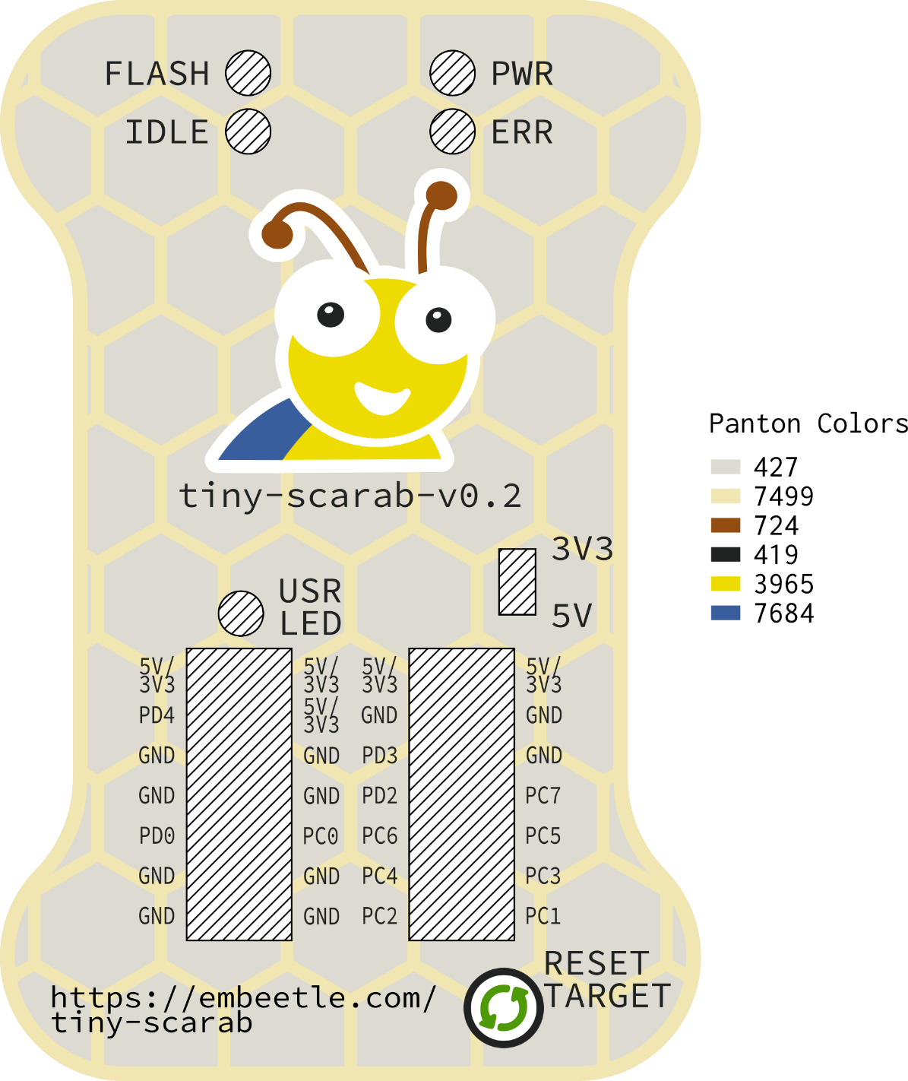
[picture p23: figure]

This drawing is also available as a .svg file and a .pdf file for your convenience. For more info on the files I provided, please check the last page of this document. If you need it in another format, please contact me.

The next pages show all the dimensions for the membrane – the outer dimensions as well as all the dimensions for the cutouts and where the embossment for the pushbutton should be located.

## Outer Dimensions

The overall dimensions of the graphic overlay membrane is 48 x 74 mm. Below you can see the dimensions in more detail (all in mm):

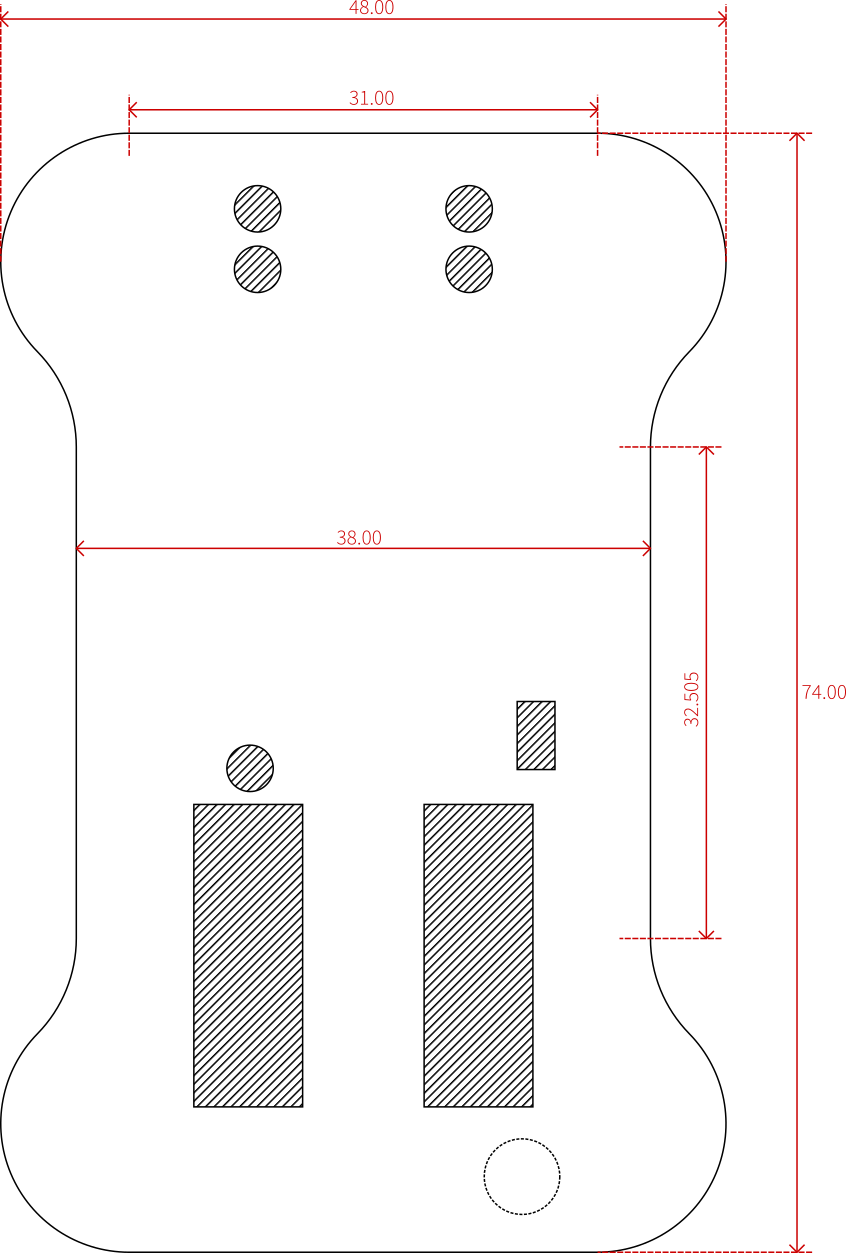
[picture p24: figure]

As for the corners, they consist of two intersecting arcs. The first arc has a diameter of 17.00 mm, the second one 18.00 mm:

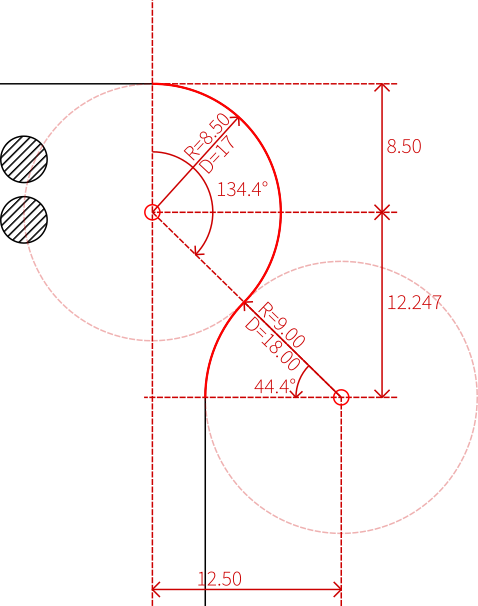
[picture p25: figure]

## LED holes

The graphic overlay membrane should have 5 holes to give space to the LEDs poking out. Each hole should be 3.0mm in diameter. The following figure shows their locations (all dimensions in mm):


LED hole

⌀ 3.0mm

## Slider Switch and Pin Header Slots

Three slots should be milled at the bottom of the graphic overlay membrane: one for a slider switch handle, and two for the pin headers. The following figure shows their locations and dimensions:


## Pushbutton Embossments

There is one pushbutton in the design. It pokes through a hole of 5.0mm diameter in the top of the box. However, there should be no hole for the pushbutton in the graphic membrane! Instead, the graphic membrane should cover the button with an embossment:


As shown in the figure below, the graphic membrane should cover the button handle. The button handle is only 0.3mm above the surface. The push stroke travels 0.3mm down, so the handle will be co-planar with the rest of the box surface when the button is pushed down.


The following figure shows where the pushbutton is located:


## Result

When the membrane is glued on the product, it will look like this:


## Files


Along with this document, I provide the following files:


The files design_01.pdf and design_01.svg show the cutouts with a “hatched” pattern:


The files design_02.pdf and design_02.svg just leave the cutouts as a “void” (no material):

Both files are identical in all other aspects. Please choose the file that is most convenient for your engineers.

## Contact

Considering our needs – is your company able to meet these requirements? Please contact me on my WeChat:

+86 136 9181 5371

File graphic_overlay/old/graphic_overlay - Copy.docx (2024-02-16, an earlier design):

# Graphic Overlay Specifications


I’m Kristof Mulier, a Belgian electronics engineer and cofounder of Embeetle IDE. We’re developing a product, but still need a graphic overlay membrane in PET (Polyester), PC (Polycarbonate) or another elastomer material. For this graphic overlay membrane, we would like to cooperate with your company. This document clarifies what we need.

## Our Product


The product consists of a circuit board mounted with bolts in a plastic box:

The cover has a few holes for the buttons, slide switches and LEDs. The circuit board is mounted just 4mm below the surface, so some of these components stick out through the holes in the cover:


## Overview

We need a graphic overlay membrane to glue on top of our product’s cover:

LED hole

⌀ 3mm*

countersink (for screw head)

⌀ 6.00mm

pushbutton

⌀ 3.00mm

slider switch slot

2.50 x 4.50mm

pin header slot

7.20 x 20.0mm


This is what we envision the graphic overlay membrane to look like. The hatched areas are holes and cutouts in the membrane to give space for the LEDs, screws, slider switch and pin header connectors that poke through the cover. For the two pushbuttons, no holes should be drilled in the membrane! Instead, the membrane should cover them (see page 9).


This drawing is also available as a .svg file for your convenience. If you need it in another format, please contact me.

The next pages show all the dimensions for the membrane – the outer dimensions as well as all the dimensions for the cutouts and where the embossments for the two pushbuttons should be located.

## Outer Dimensions

The overall dimensions of the graphic overlay membrane is 54 x 80 mm. Below you can see the dimensions in more detail (all in mm):


As for the corners, they consist of two intersecting arcs. The first arc has a diameter of 23.00 mm, the second one 12.00 mm:

Be careful! The centerpoint of the first arc (the one of 23mm diameter) is NOT the same as the centerpoint of the nearby screw hole:


!

## Screw Holes

The horizontal space between the screw holes is 38.00mm, the vertical space is 60mm – measured between the hole centerpoints. For the screw holes themselves, we need a 6mm diameter cutout in the membrane:


hole for screw and screw head: ⌀ 6.00mm

## LED holes

The graphic overlay membrane should have 5 holes to give space to the LEDs poking out. Each hole should be 3.07mm in diameter. The following figure shows their locations (all dimensions in mm):


LED hole

⌀ 3.07mm

## Slider Switch and Pin Header Slots

Three slots should be milled at the bottom of the graphic overlay membrane: one for a slider switch handle, and two for the pin headers. The following figure shows their locations and dimensions:


## Pushbutton Embossments

There is one pushbutton in the design. It pokes through a hole of 3.00mm diameter in the top of the box. However, there should be no hole for the pushbutton in the graphic membrane! Instead, the graphic membrane should cover the button with an embossment:


BOX

COVER

PCB


As shown in the figure below, the graphic membrane should cover the button handle. The button handle is only 0.4mm above the surface. The push stroke travels 0.3mm down.

The following figure shows where the pushbutton is located:


## Text Sizes

Some of the text on the graphic membrane is really small – only 1mm tall. Please let me know if your machines are able to print such small text on the graphic membrane.


Text is about

1mm tall

## Logo Colors

I’d like to put our logo in the middle of the product. If possible in color. How much extra cost would a colored logo incur? Please let me know the cost difference, so I can decide to provide you with a colorless logo design instead if the difference is too high.


## Contact

Considering our needs – is your company able to meet these requirements? Please contact me on my WeChat:

+86 136 9181 5371

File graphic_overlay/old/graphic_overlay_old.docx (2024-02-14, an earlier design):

# Graphic Overlay for Tiny Scarab


I’m Kristof Mulier, a Belgian electronics engineer and cofounder of Embeetle IDE. We’re developing a product, but still need a graphic overlay membrane in PET (Polyester), PC (Polycarbonate) or another elastomer material. For this graphic overlay membrane, we would like to cooperate with your company. This document clarifies what we need.

## Our Product


The product consists of a circuit board mounted with bolts in a plastic box:


The cover has a few holes for the buttons, slide switches and LEDs. The circuit board is mounted just 4mm below the surface, so all these components stick out through these holes.

## Graphic Overlay Membrane


We need a graphic overlay membrane to glue on top of our product’s cover:


Our product contains the following user-interface elements:

- Pushbuttons
- Slide switches
- LEDs

The graphic overlay membrane should take these elements into account.


## Pushbuttons

I envision the graphic overlay membrane to cover the pushbuttons:


## Slide Switches


The Slide Switches have following dimensions:


Unless there’s a more elegant solution, the graphic overlay should probably just stop at the edges of the cutout from the slider button:

## LEDs


The LEDs shine into ⌀ 3.0 mm lightpipes. These stick out 1.0 mm above the surface:

Can the graphic overlay cover these LEDs? Perhaps with a transparent part in the graphic overlay to let the light pass through?


## Contact

Considering our needs – is your company able to meet these requirements? Please contact me on my WeChat:

+86 136 9181 5371

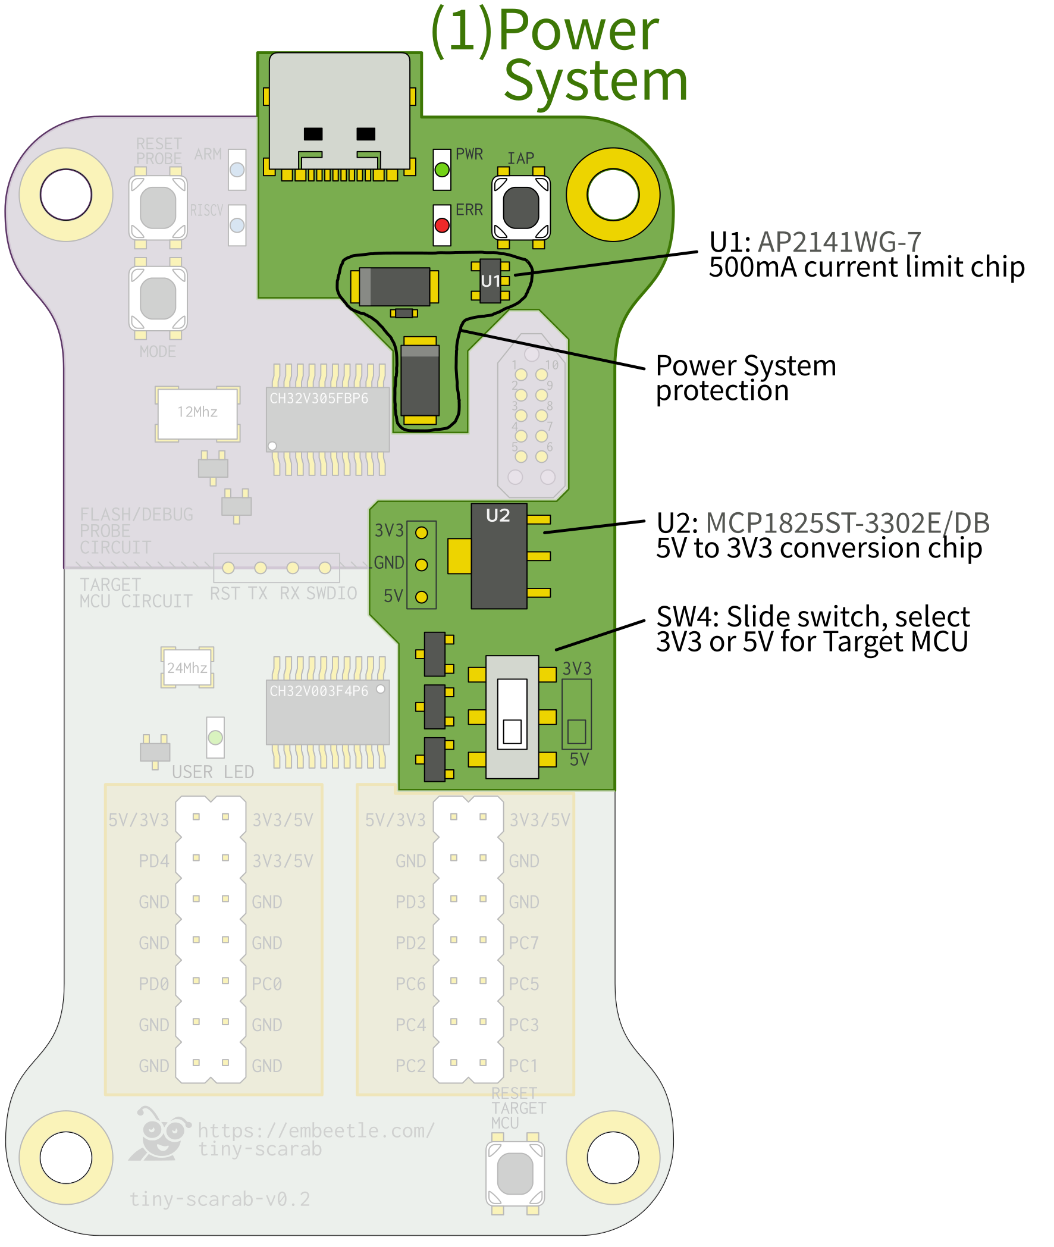
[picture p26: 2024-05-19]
documentation/website_figures/board_overview_02.webp

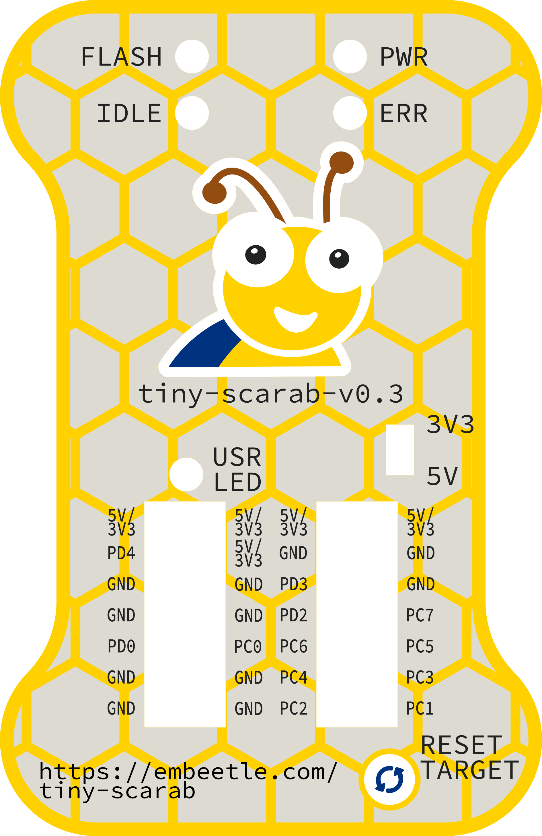
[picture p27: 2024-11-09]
graphic_overlay/design.png

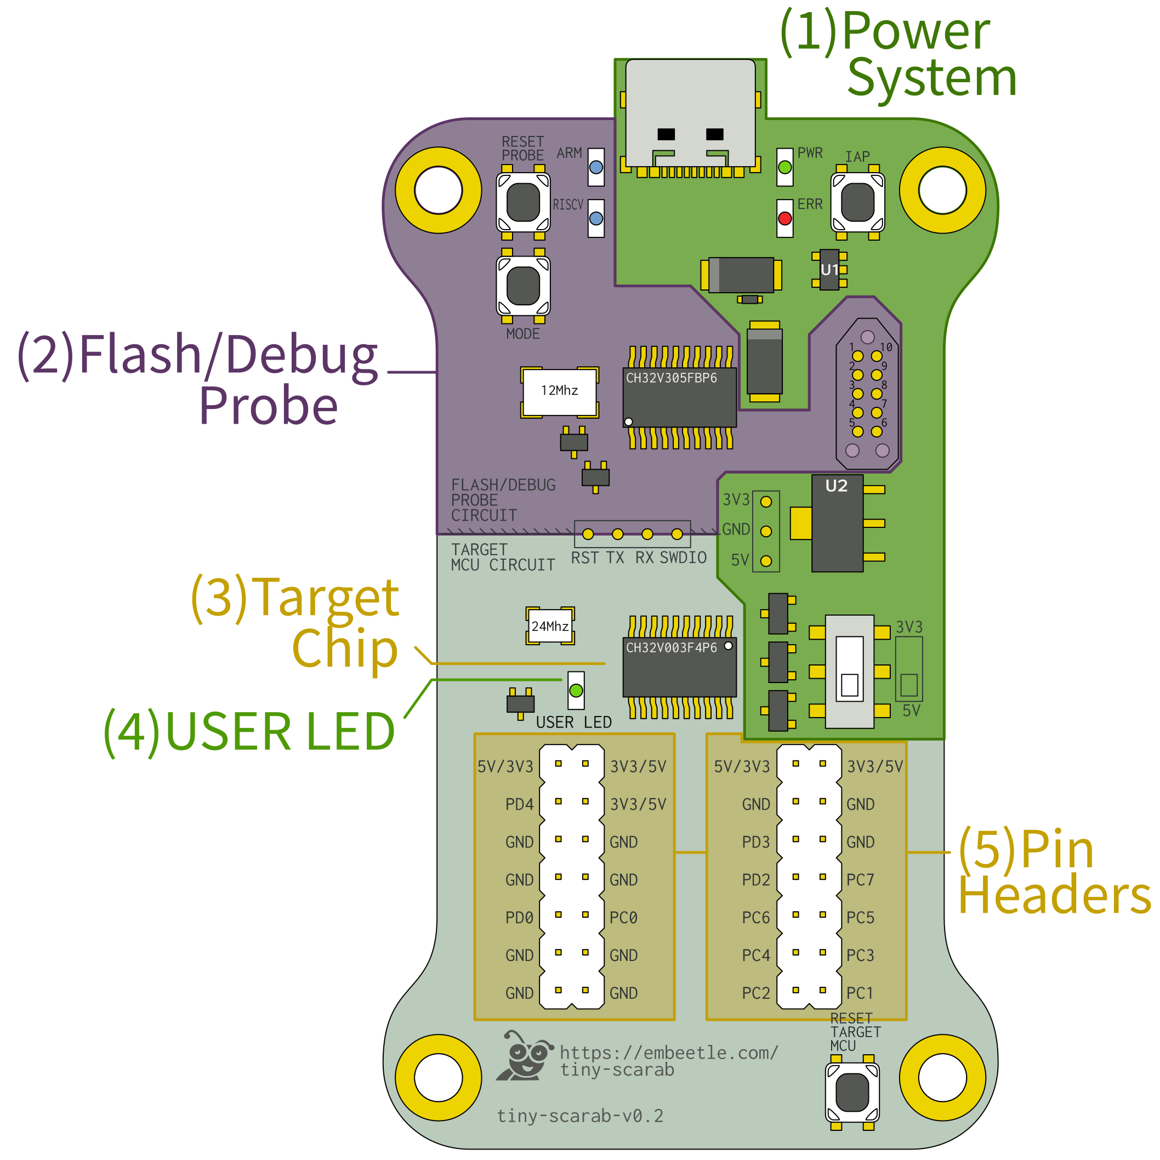
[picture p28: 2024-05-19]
documentation/website_figures/board_overview_01.webp

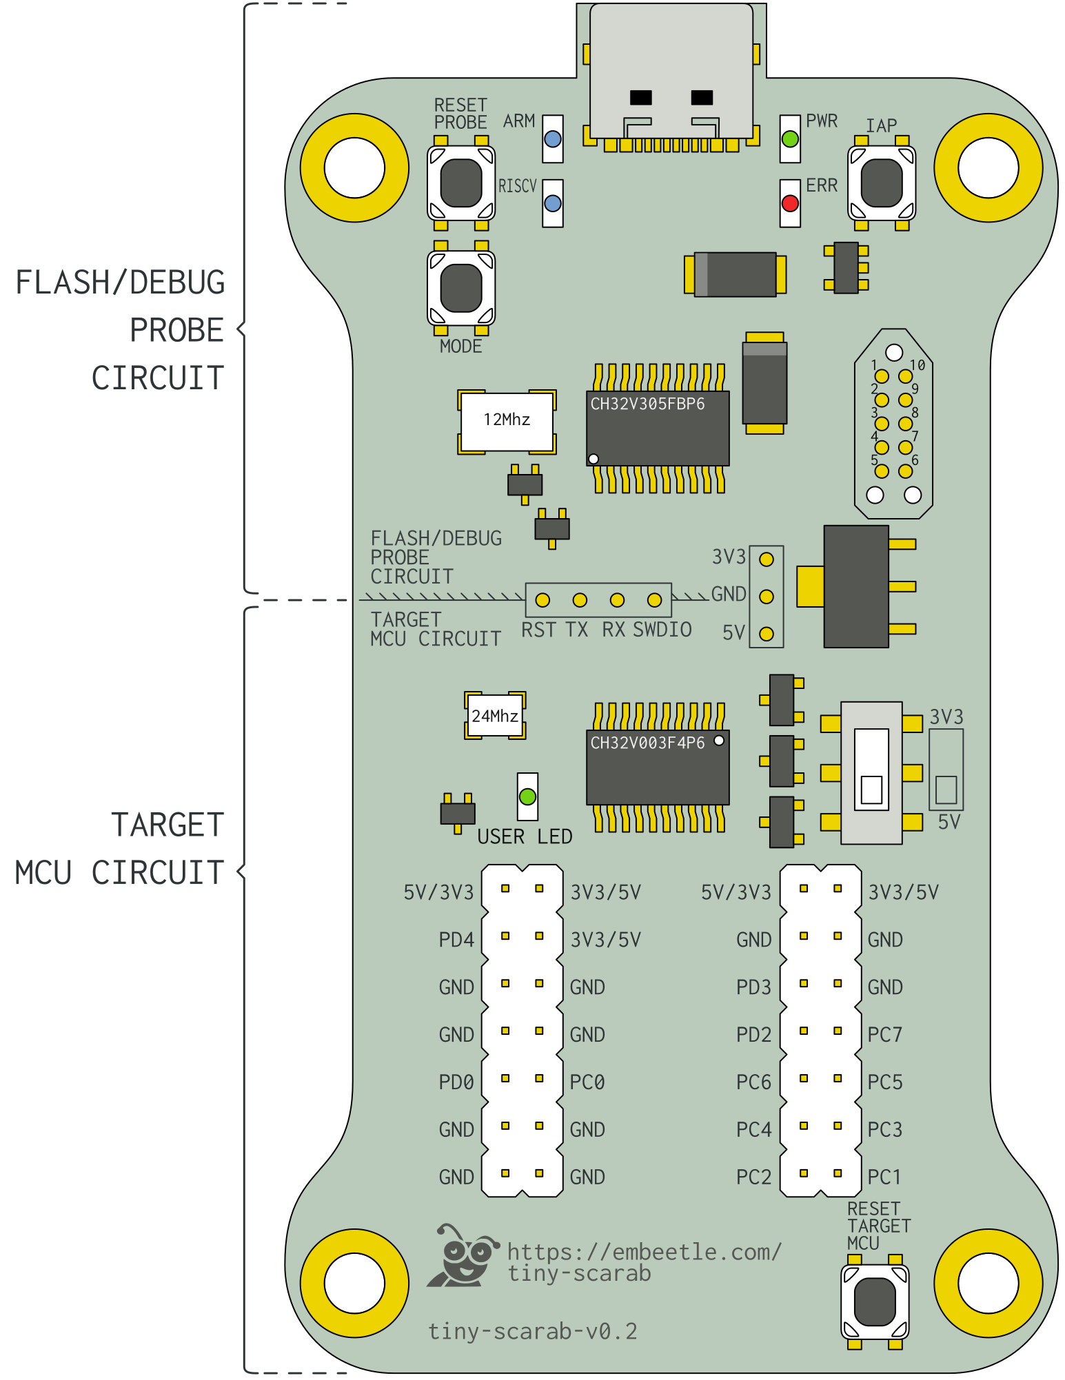
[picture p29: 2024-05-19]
documentation/website_figures/pinout_01.webp

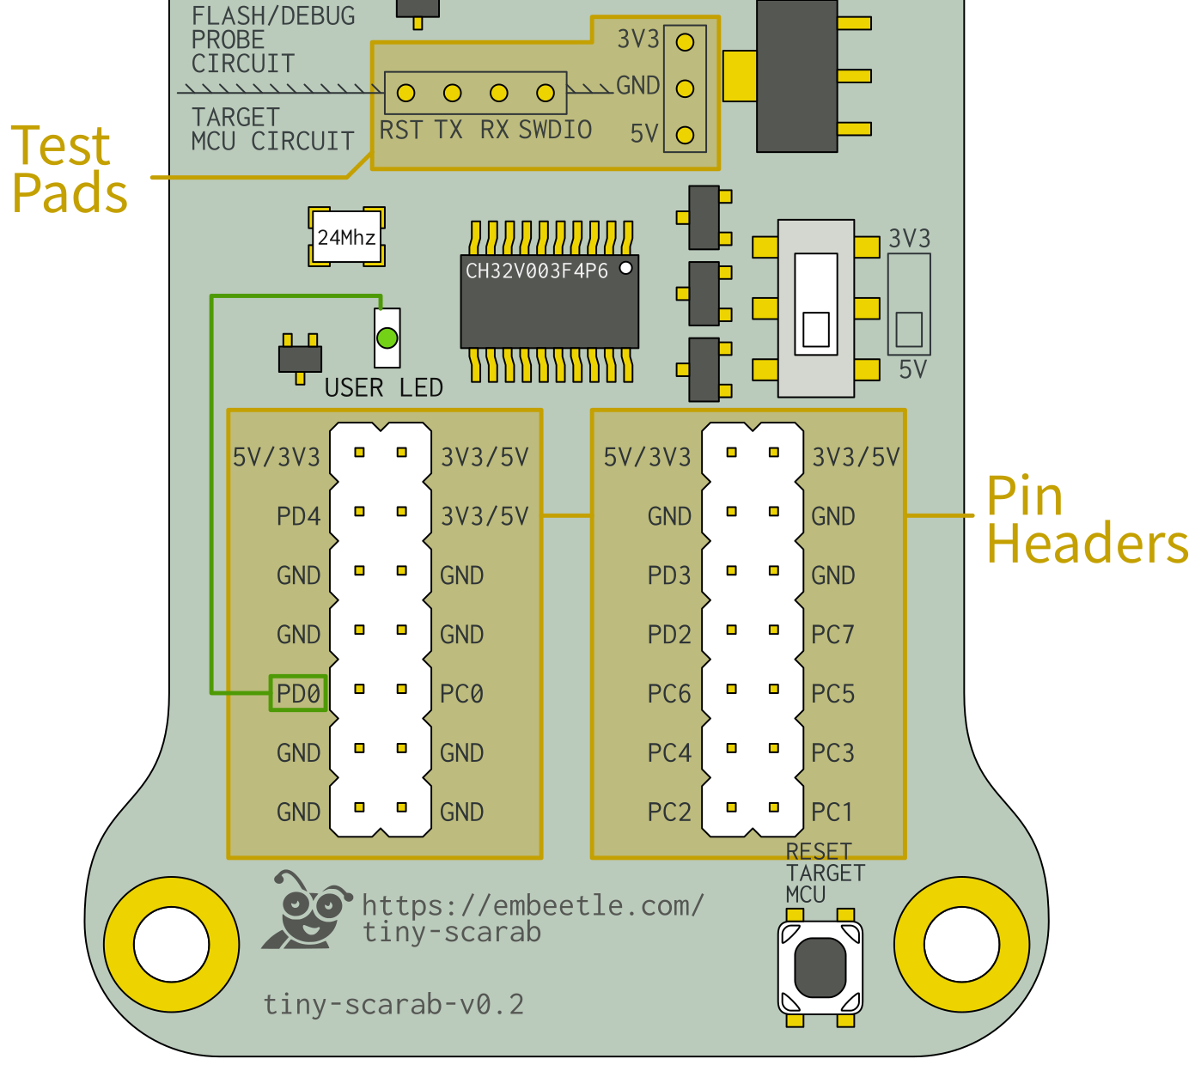
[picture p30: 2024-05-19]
documentation/website_figures/pinout_02.webp

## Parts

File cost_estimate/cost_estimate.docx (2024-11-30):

# Cost Estimate

[update: 12/11/2024]

This document aims to estimate all the costs involved in producing the Tiny Scarab board, its enclosure and graphical overlay membrane.

# 1. PCB Circuit

## 1.1 Component Cost

I purchase all components directly at the circuit manufacturer JLCPCB. I typically buy the components before ordering the PCB itself. They are stored in my personal inventory in the JLCPCB factory (each client has an account and a personal inventory tied to that account, where you can pre-order components).

These are the components I order for one board:

Designator | Value | LCSC Part # | Quantity @1 board | Quantity @100 boards | Price @100 boards
C1, C2, C4 | 100n | C307331 | 3 | 300 | $1.4100
C10, C15, C16, C17, C23, C24, C25, C26, C27, C30, C31, C37, C38, C39, C40, C41, C5, C6, C7, C8, C9 | 100n | C1525 | 21 | 2100 | $1.8900
C11, C13, C14, C18 | 1u | C52923 | 4 | 400 | $1.1600
C12, C19 | 10u | C15525 | 2 | 200 | $0.6800
C20, C21, C22, C3, C32, C33, C34, C35, C36 | 10u | C15850 | 9 | 900 | $6.8400
C28, C29, C42, C43 | 22p | C1555 | 4 | 400 | $0.3600
D1 | 5V6 | C2943833 | 1 | 100 | $2.6200
D2 | 40V 350mA | C397613 | 1 | 100 | $1.6700
F1 | 2A | C1972777 | 1 | 100 | $8.6400
J1 | USB_C | C2927038 | 1 | 100 | $3.8500
J3, J4 | PIN_HEADER | C84004 | 2 | 200 | $8.7000
LED1, LED5 | GREEN | C9900122772 | 2 | 200 | $1.0800
LED2 | RED | C9900122773 | 1 | 100 | $0.5400
LED3, LED4 | BLUE | C9900122774 | 2 | 200 | $1.0800
Q1, Q2, Q6 | DMG1012UW-7 | C156390 | 3 | 300 | $7.6800
Q3, Q4, Q5 | DMP1045U-7 | C177033 | 3 | 300 | $17.2500
R1 | 330 | C25104 | 1 | 100 | $0.0600
R12, R18, R28 | 1k | C11702 | 3 | 300 | $0.1500
R13, R24, R25, R30 | 100k | C25741 | 4 | 400 | $0.2000
R14, R16 | 33 | C25105 | 2 | 200 | $0.1000
R19, R20, R27 | 10k | C25744 | 3 | 300 | $0.1500
R21, R22, R23 | 0 | C17168 | 3 | 300 | $0.1500
R26 | 470 | C25117 | 1 | 100 | $0.0500
R29, R3 | 210 | C25090 | 2 | 200 | $0.0600
R4, R5 | 5k1 | C25905 | 2 | 200 | $0.0800
R6 | 100 | C25076 | 1 | 100 | $0.0500
R7, R9 | 220 | C25091 | 2 | 200 | $0.1000
SW4 | 12V 50mA | C2884764 | 1 | 100 | $8.8100
SW5 | 12V 50mA | C146695 | 1 | 100 | $4.6600
TVS1, TVS2 | 5V | C20884 | 2 | 200 | $12.7800
TVS10, TVS11, TVS12, TVS13, TVS14, TVS15, TVS16, TVS17, TVS18, TVS19, TVS20, TVS21, TVS22, TVS23, TVS24, TVS25, TVS26, TVS27, TVS28, TVS29, TVS30, TVS31, TVS32, TVS33, TVS34, TVS35, TVS7, TVS8, TVS9 | 5V | C3001954 | 29 | 2900 | $20.0200
TVS3 | 5V | C83329 | 1 | 100 | $7.5000
U1 | AP2141WG-7 | C500761 | 1 | 100 | $14.9900
U2 | 3V3 | C145411 | 1 | 100 | $71.2200
U3 | CH32V305FBP6 | C5123443 | 1 | 100 | $139.2400
U4 | CH32V003F4P6 | C5187096 | 1 | 100 | $20.0400
XTAL1 | 12MHz | C2901629 | 1 | 100 | $17.9900
XTAL2 | 24MHz | C5261157 | 1 | 100 | $8.7200
LED Spacer | 3mm | C92325 | 5 | 500 | $2.1500

NOTE: I purchased the LEDs at Shenzhen Xinsheng Microelectronics Technology, on Alibaba, at a price of 54$ per 10 000 parts. Then I had them sent directly to the JLCPCB factory to be added to my personal component inventory. The price per LED is therefore $0.0054.

The total component cost for 100 boards is $394.72. So the component cost per board is:

$3.9472 component cost per board.

($4.2630 incl Chinese VAT 8%)

## 1.2 PCB Production and Assembly Cost

I’ve listed the PCB production and assembly (parts placement and soldering) costs in the table below. Please note that these costs are under the assumption that >100 PCBs are ordered:

| $/100 boards | Notes
PCB Production | 68.31
PCB Assembly | 162.89
Photo Confirmation | 7.97 | Only needed for first batch after a change.
Board Cleaning | 15.94
Secondary processing | 19.43 | The LEDs must be spaced 3mm from the board.
Shipping | 3.23 | Shipping to Embeetle office in Shenzhen

The total cost PCB production and assembly cost, including the shipping inside China, is $277.77 for 100 boards. It’s fair to deduct the $7.97 photo confirmation cost, as that is only required for a first batch. So we end up at $269.80:

$2.6980 board production cost

($2.9138 incl Chinese VAT 8%)

# 2. Enclosure

The following table lists the costs for the 3D printed enclosures:

| $ / 100 units | Notes
Box + Lid | 321.57
Shipping | 3.96

$3.2553 enclosure production cost

($3.5157 incl Chinese VAT 8%)

# 3. Graphical Membrane

The cost per membrane is very dependent on the order quantity – much more so than the PCB production. For that reason, I decided to put here the cost per membrane provided that 500 would be purchased instead of only 100:

$0.7060 graphical membrane cost

($0.7625 incl Chinese VAT 8%)

# 4. Miscellaneous Costs

Four screws need to be inserted to fasten the enclosure. Last but not least – I place a small iron block in each enclosure to give the product extra weight.

| $/unit | Notes
Screws | $0.002211 x 4 | $22.11 for 10.000 screws, including VAT
Iron block | $0.11055 | $22.11 for 200 blocks, including VAT

So the total cost per board for these items would be:

$0.11055 miscellaneous costs

($0.119394 incl Chinese VAT 8%)

SCREWS

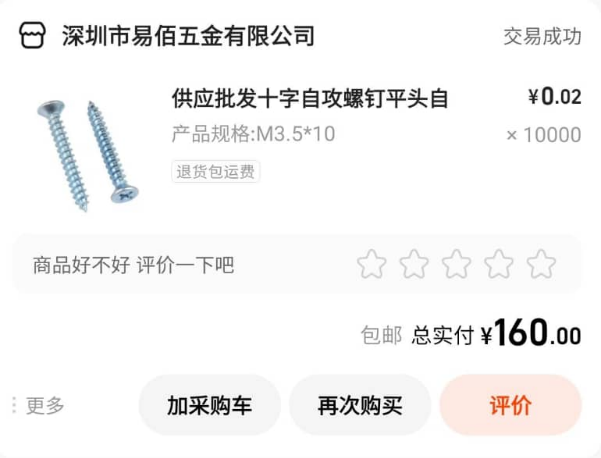
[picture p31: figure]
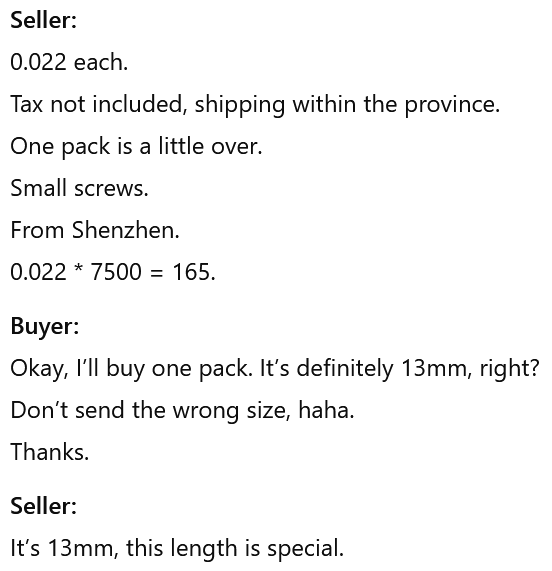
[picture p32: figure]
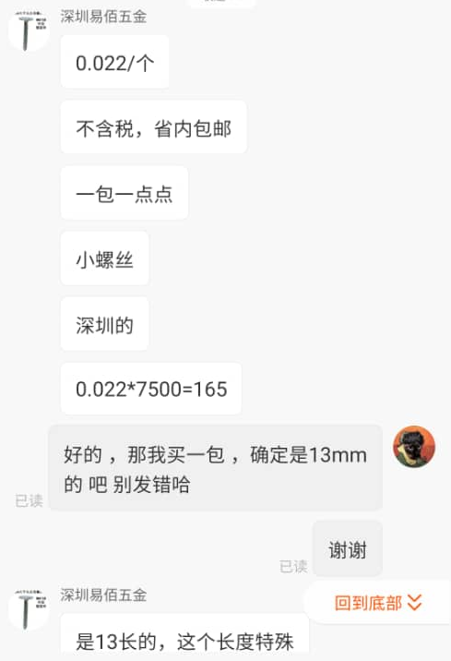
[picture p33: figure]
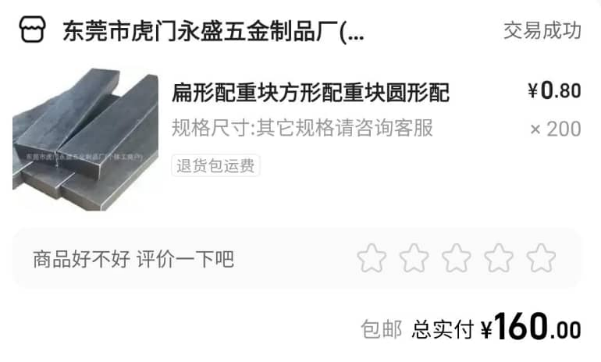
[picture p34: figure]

IRON BLOCKS

Seller:

-0.15mm negative tolerance and +0.1mm positive tolerance.

About 54g.

We can provide you with samples.

How many do you need?

Buyer:

Can you quote for 100 and 200 pieces? We need this many for samples and will place an order directly.

Are you also based in Dongguan?

Seller:

The surface is electroplated white zinc.

Buyer:

No surface treatment is required.

0.8 each.

Seller:

The surface is untreated and has oil on it.

Buyer:

If it has oil, it might not work well. Then could you process it? How much would it cost?

Seller:

(Attaches a picture of the product)

Buyer:

We need to put this inside electronic components, so it must be completely clean, neat, and tidy.

Actually, the plating is not that important to us. We just need the product to be clean and dry. Can you do that?

Seller:

(Attaches another picture of the product)

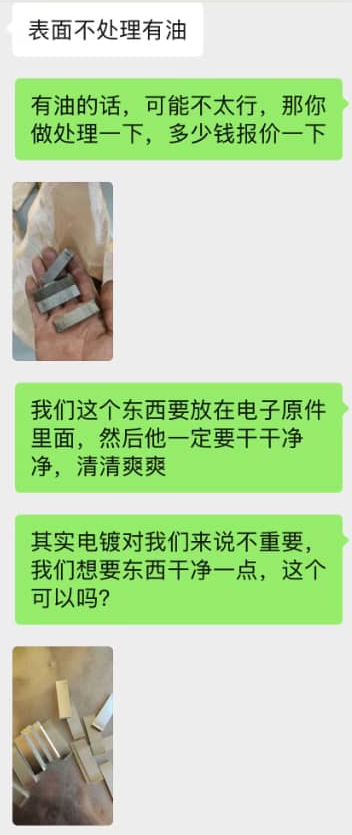
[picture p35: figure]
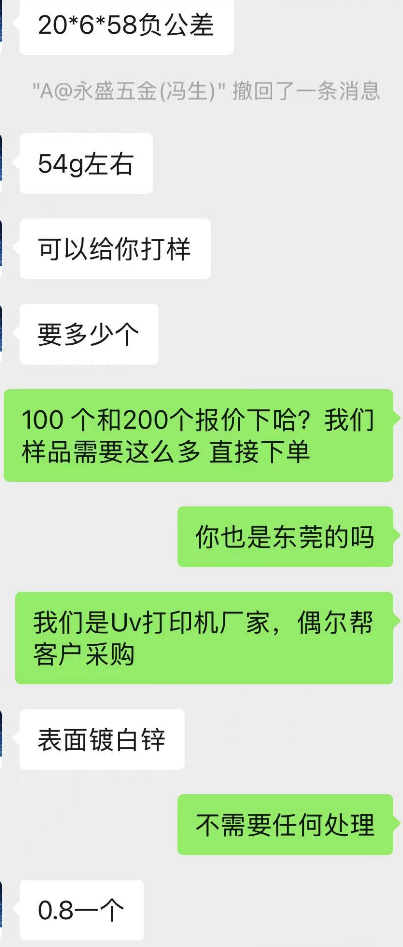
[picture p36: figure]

# 5. Box

I purchased 100 customized boxes for 240 yuan ($ 33.16). This includes shipping and Chinese VAT.

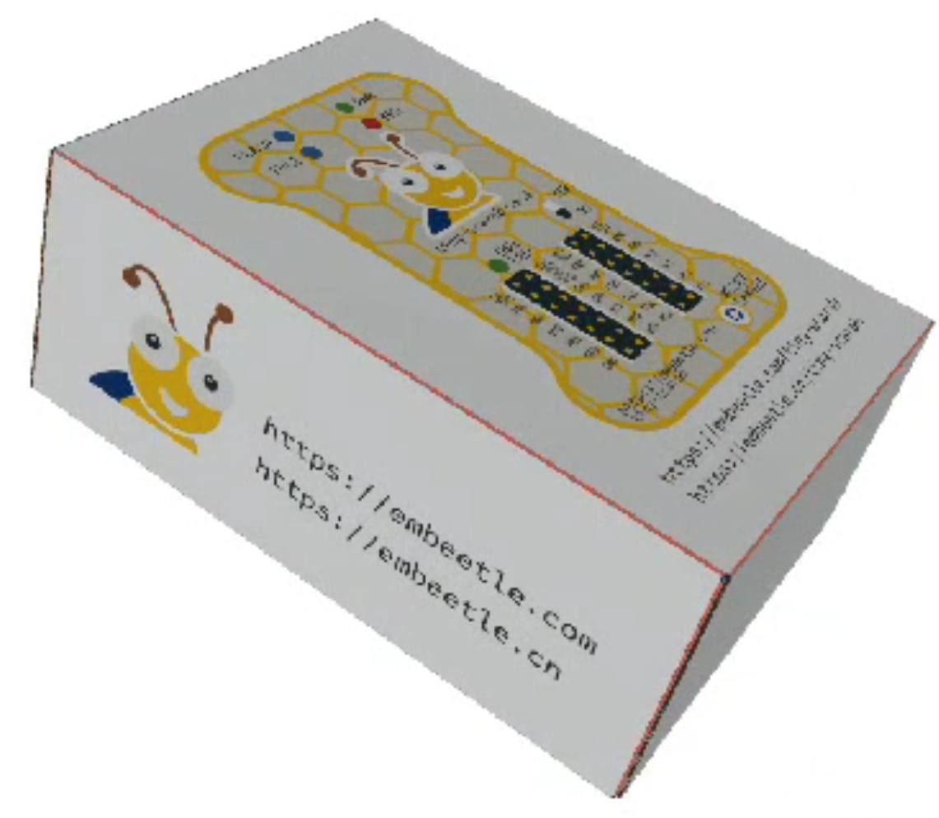
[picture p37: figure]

$0.3070 box cost

($0.3316 incl Chinese VAT 8%)

# TOTAL

Let’s compute the total cost per unit (incl shipping and taxes):

| $ / unit | $ / unit (incl Chinese VAT)
PCB components | $ 3.9472 | $ 4.2630
Board Production | $ 2.6980 | $ 2.9138
Enclosure | $ 3.2553 | $ 3.5157
Graphical Membrane | $ 0.7060 | $ 0.7625
Miscellaneous | $ 0.1106 | $ 0.1194
Boxes | $ 0.3070 | $ 0.3316
TOTAL | $11.0241 | $11.9060

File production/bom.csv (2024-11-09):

Designator | Footprint | Quantity | Value | LCSC Part #
C1, C2, C4 | 0402 | 3 | 100n | C307331
C10, C15, C16, C17, C23, C24, C25, C26, C27, C30, C31, C37, C38, C39, C40, C41, C5, C6, C7, C8, C9 | 0402 | 21 | 100n | C1525
C11, C13, C14, C18 | 0402 | 4 | 1u | C52923
C12, C19 | 0402 | 2 | 10u | C15525
C20, C21, C22, C3, C32, C33, C34, C35, C36 | 0805 | 9 | 10u | C15850
C28, C29, C42, C43 | 0402 | 4 | 22p | C1555
D1 | D_SMA_1SMA4734A | 1 | 5V6 | C2943833
D2 | D_SOD-323 | 1 | 40V 350mA | C397613
F1 | Fuse_MFU0603FF02000P500 | 1 | 2A | C1972777
J1 | USB_C_Receptable_USB-TYPE-C-018 | 1 | USB_C_Receptable_USB2.0 | C2927038
J3, J4 | CONN_PIN_HEADER_2x07_P2.54mm_Vertical_SMD | 2 | CONN_PIN_HEADER_02x07 | C84004
LED1, LED5 | LED_D3.0mm_green | 2 | GREEN | C9900122772
LED2 | LED_D3.0mm_red | 1 | RED | C9900122773
LED3, LED4 | LED_D3.0mm_blue | 2 | BLUE | C9900122774
Q1, Q2, Q6 | SOT-323_SC-70 | 3 | DMG1012UW-7 | C156390
Q3, Q4, Q5 | SOT-23_DMP1045U-7 | 3 | DMP1045U-7 | C177033
R1 | 0402 | 1 | 330 | C25104
R12, R18, R28 | 0402 | 3 | 1k | C11702
R13, R24, R25, R30 | 0402 | 4 | 100k | C25741
R14, R16 | 0402 | 2 | 33 | C25105
R19, R20, R27 | 0402 | 3 | 10k | C25744
R21, R22, R23 | 0402 | 3 | 0 | C17168
R26 | 0402 | 1 | 470 | C25117
R29, R3 | 0402 | 2 | 210 | C25090
R4, R5 | 0402 | 2 | 5k1 | C25905
R6 | 0402 | 1 | 100 | C25076
R7, R9 | 0402 | 2 | 220 | C25091
SW4 | SW_Slide_SPDT_XKB-Connectivity_SS-3235D-03-L3 | 1 | 12V 50mA | C2884764
SW5 | SW_Tactile_SPST_NO_Straight_Korean-Hroparts_K2-1109SP-I4SA-04 | 1 | 12V 50mA | C146695
TVS1, TVS2 | D_SOD-323_CDSOD323-T05LC | 2 | 5V | C20884
TVS10, TVS11, TVS12, TVS13, TVS14, TVS15, TVS16, TVS17, TVS18, TVS19, TVS20, TVS21, TVS22, TVS23, TVS24, TVS25, TVS26, TVS27, TVS28, TVS29, TVS30, TVS31, TVS32, TVS33, TVS34, TVS35, TVS7, TVS8, TVS9 | D_SOD-882_SP1007-01ETG | 29 | 5V | C3001954
TVS3 | D_SMA_SMAJ5.0A | 1 | 5V | C83329
U1 | SOT-23-5 | 1 | AP2141WG-7 | C500761
U2 | SOT-223-3_TabPin2 | 1 | 3V3 | C145411
U3 | TSSOP-20_4.4x6.5mm_P0.65mm | 1 | CH32V305FBP6 | C5123443
U4 | TSSOP-20_4.4x6.5mm_P0.65mm | 1 | CH32V003F4P6 | C5187096
XTAL1 | CRYSTAL-SMD5032-4P | 1 | 12MHz | C2901629
XTAL2 | CRYSTAL-SMD3225-4P | 1 | 24MHz | C5261157

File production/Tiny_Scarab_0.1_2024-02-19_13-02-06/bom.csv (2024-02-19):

Designator | Footprint | Quantity | Value | LCSC Part #
C1, C2, C4 | 0402 | 3 | 100n | C307331
C10, C15, C16, C17, C23, C24, C25, C26, C27, C30, C31, C37, C38, C39, C40, C41, C5, C6, C7, C8, C9 | 0402 | 21 | 100n | C1525
C11, C13, C14, C18 | 0402 | 4 | 1u | C52923
C12, C19 | 0402 | 2 | 10u | C15525
C20, C21, C22, C3, C32, C33, C34, C35, C36 | 0805 | 9 | 10u | C15850
C28, C29, C42, C43 | 0402 | 4 | 22p | C1555
D1 | D_SMA_1SMA4734A | 1 | 5V6 | C2943833
D2 | D_SOD-323 | 1 | 40V 350mA | C397613
F1 | Fuse_MFU0603FF02000P500 | 1 | 2A | C1972777
J1 | USB_C_Receptable_USB-TYPE-C-018 | 1 | USB_C_Receptable_USB2.0 | C2927038
J3, J4 | CONN_PIN_HEADER_2x07_P2.54mm_Vertical_SMD | 2 | CONN_PIN_HEADER_02x07 | C84004
LED1, LED5 | LED_0603_CSL0902ET | 2 | GREEN | C7115899
LED2 | LED_0603_CSL0902UT | 1 | RED | C5579175
LED3, LED4 | LED_0603_CSL0902BT | 2 | BLUE | C6538602
Q1, Q2, Q6 | SOT-323_SC-70 | 3 | DMG1012UW-7 | C156390
Q3, Q4, Q5 | SOT-23_DMP1045U-7 | 3 | DMP1045U-7 | C177033
R1, R7 | 0402 | 2 | 100 | C25076
R10, R28, R3, R8 | 0402 | 4 | 220 | C25091
R13, R17, R29, R4 | 0402 | 4 | 1k | C11702
R14, R23, R24, R30 | 0402 | 4 | 100k | C25741
R15, R16 | 0402 | 2 | 22 | C25092
R18, R19, R26 | 0402 | 3 | 10k | C25744
R2 | 0402 | 1 | 200 | C25087
R20, R21, R22 | 0402 | 3 | 0 | C17168
R25 | 0402 | 1 | 470 | C25117
R27 | 0402 | 1 | 1k | GPR04021K
R5, R6 | 0402 | 2 | 5k1 | C25905
SW1, SW2, SW3 | SW_Tactile_SPST_NO_Straight_Korean-Hroparts_K2-1109SP-A4SA-04 | 3 | 12V 50mA | C92581
SW4 | SW_Slide_SPDT_XKB-Connectivity_SS-3235D-03-L3 | 1 | 12V 50mA | C2884764
SW5 | SW_Tactile_SPST_NO_Straight_Korean-Hroparts_K2-1109SP-I4SA-04 | 1 | 12V 50mA | C146695
TVS1, TVS2 | D_SOD-323_CDSOD323-T05LC | 2 | 5V | C840637
TVS10, TVS11, TVS12, TVS13, TVS14, TVS15, TVS16, TVS17, TVS18, TVS19, TVS20, TVS21, TVS22, TVS23, TVS24, TVS25, TVS26, TVS27, TVS28, TVS29, TVS30, TVS31, TVS32, TVS33, TVS34, TVS35, TVS4, TVS5, TVS6, TVS7, TVS8, TVS9 | D_SOD-882_SP1007-01ETG | 32 | 5V | C126836
TVS3 | D_SMA_SMAJ5.0A | 1 | 5V | C83329
U1 | SOT-23-5 | 1 | AP2141WG-7 | C500761
U2 | SOT-223-3_TabPin2 | 1 | 3V3 | C145411
U3 | TSSOP-20_4.4x6.5mm_P0.65mm | 1 | CH32V305FBP6 | C5123443
U4 | TSSOP-20_4.4x6.5mm_P0.65mm | 1 | CH32V003F4P6 | C5187096
XTAL1 | CRYSTAL-SMD5032-4P | 1 | 12MHz | C2901629
XTAL2 | CRYSTAL-SMD3225-4P | 1 | 24MHz | C279615

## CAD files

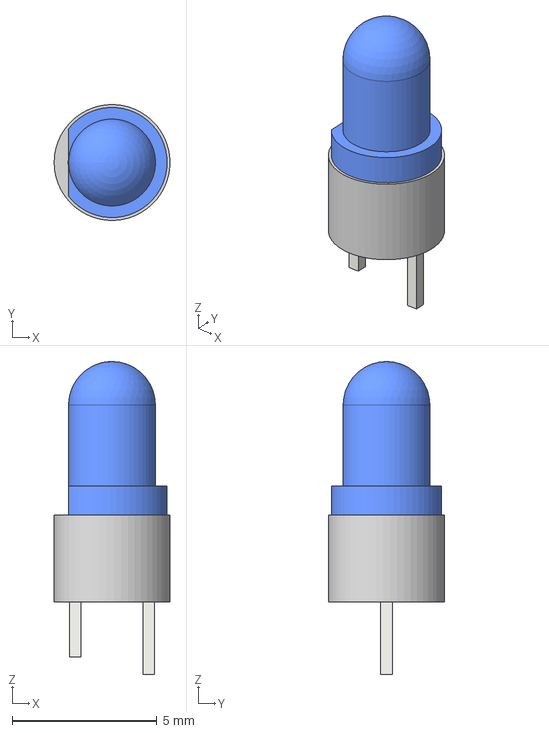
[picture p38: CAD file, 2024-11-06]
3d_models/LED_D3.0mm_spacer_blue.step
4.00 x 4.00 x 10.8 mm

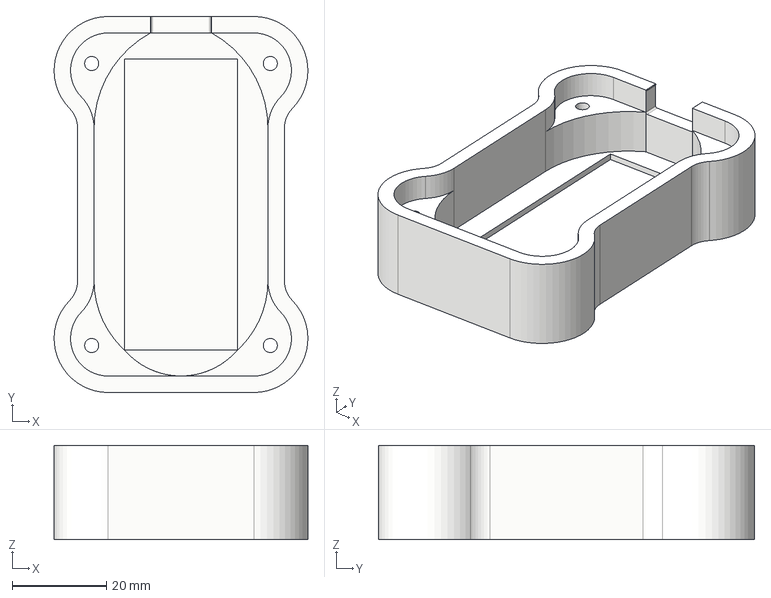
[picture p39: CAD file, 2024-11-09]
enclosure/tiny-scarab-v0.3-enclosure.step
54.0 x 80.0 x 20.0 mm

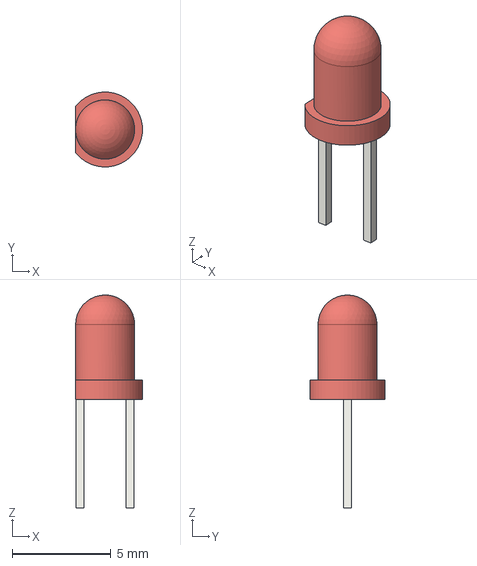
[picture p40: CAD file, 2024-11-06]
3d_models/LED_D3.0mm.step
3.40 x 3.80 x 10.8 mm

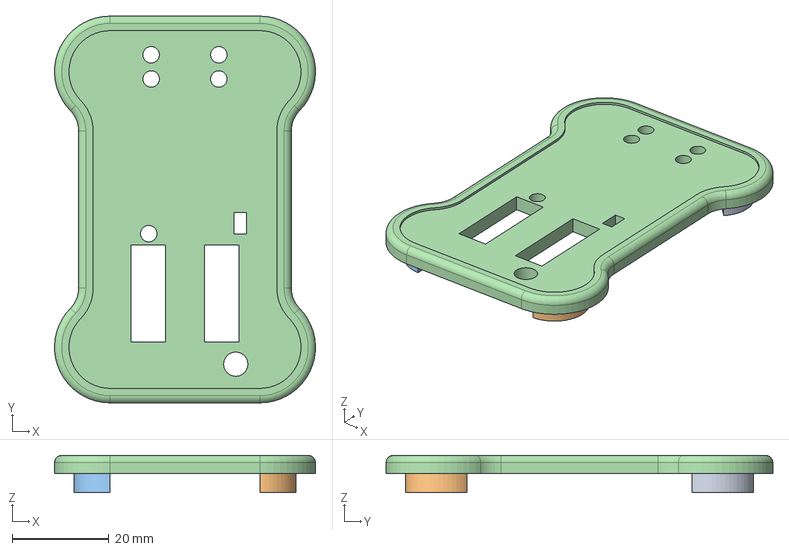
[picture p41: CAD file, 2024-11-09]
enclosure/tiny-scarab-v0.3-cover.step
54.0 x 80.0 x 7.70 mm

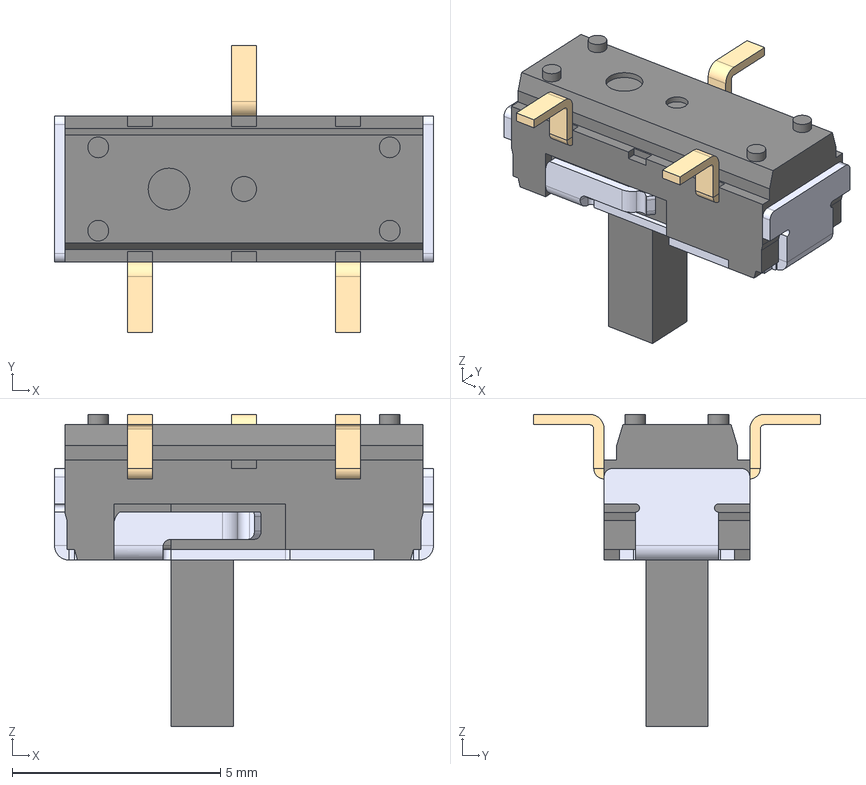
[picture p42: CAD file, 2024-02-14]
3d_models/XKB-Connectivity_SS-3235D-03-L3.step
9.10 x 6.90 x 7.50 mm

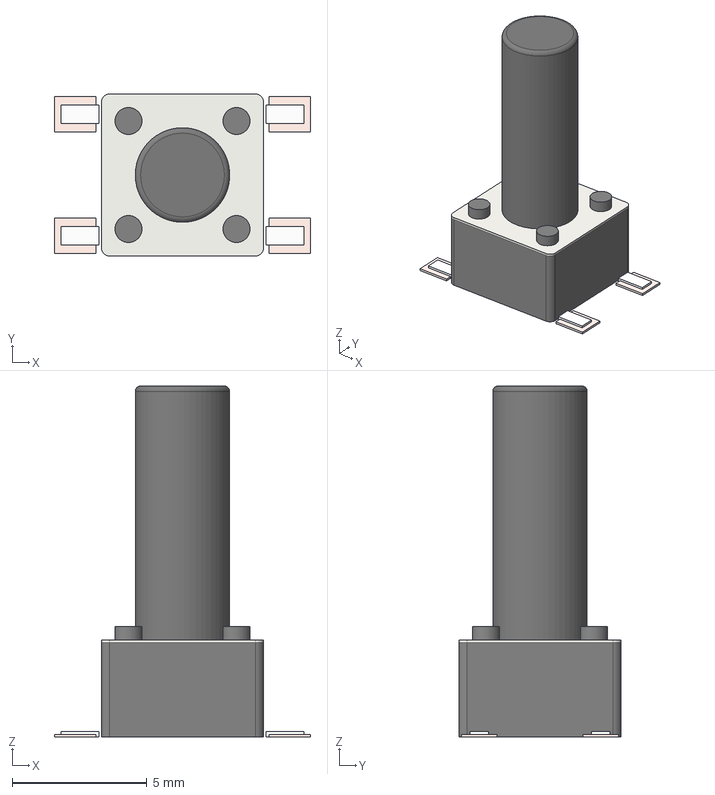
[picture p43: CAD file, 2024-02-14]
3d_models/SW_PUSH_6mm_H9.step
9.50 x 6.00 x 13.0 mm

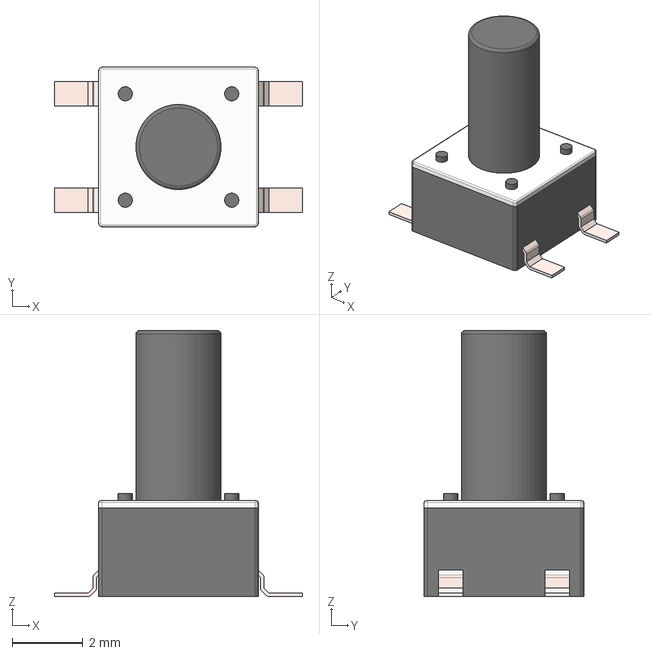
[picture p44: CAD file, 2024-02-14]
3d_models/K2-1109SP-I4SA-04.step
7.00 x 4.50 x 7.50 mm

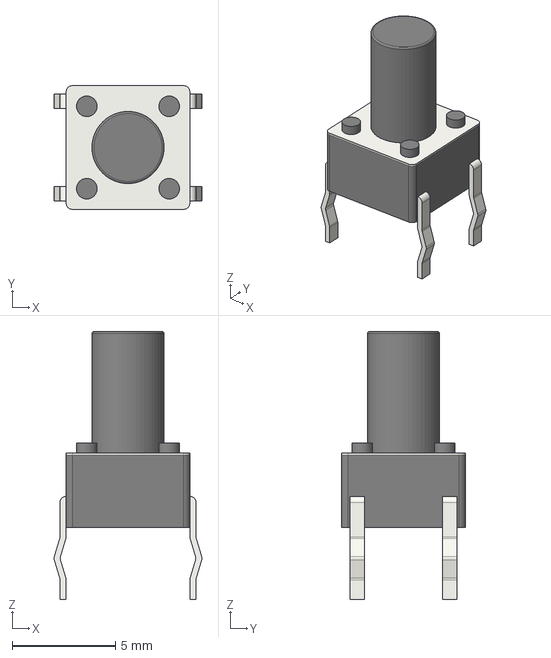
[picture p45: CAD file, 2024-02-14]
3d_models/SW_PUSH_6mm_H9.5mm.step
7.17 x 6.00 x 13.0 mm

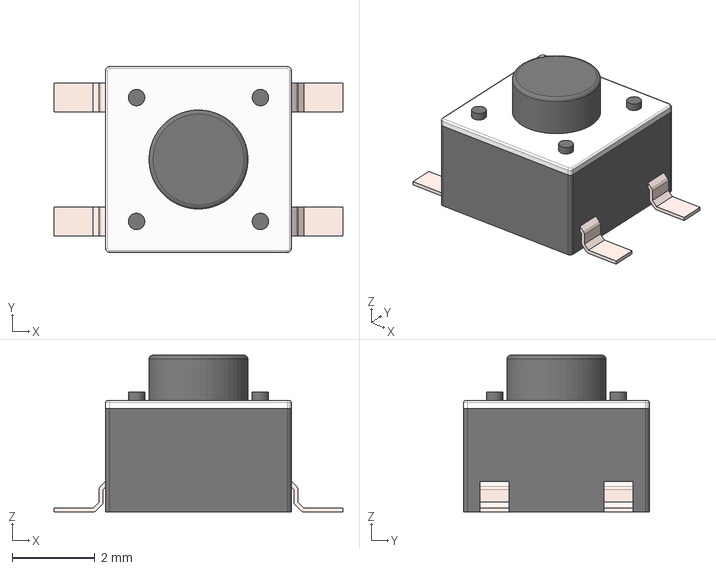
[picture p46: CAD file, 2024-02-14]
3d_models/K2-1109SP-A4SA-04.step
7.00 x 4.50 x 3.80 mm

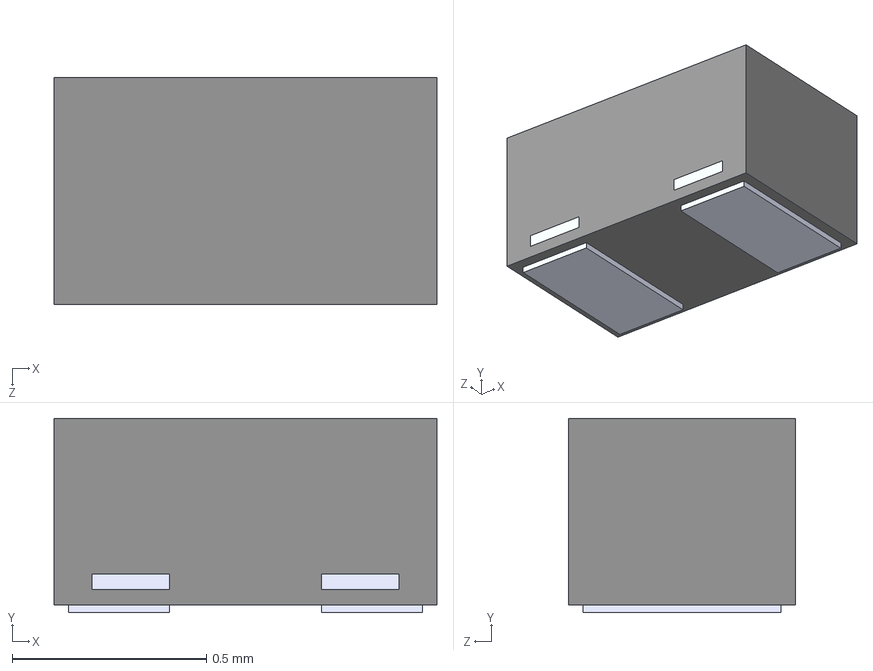
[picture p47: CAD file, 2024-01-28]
3d_models/SOD-882.step
0.985 x 0.5 x 0.585 mm

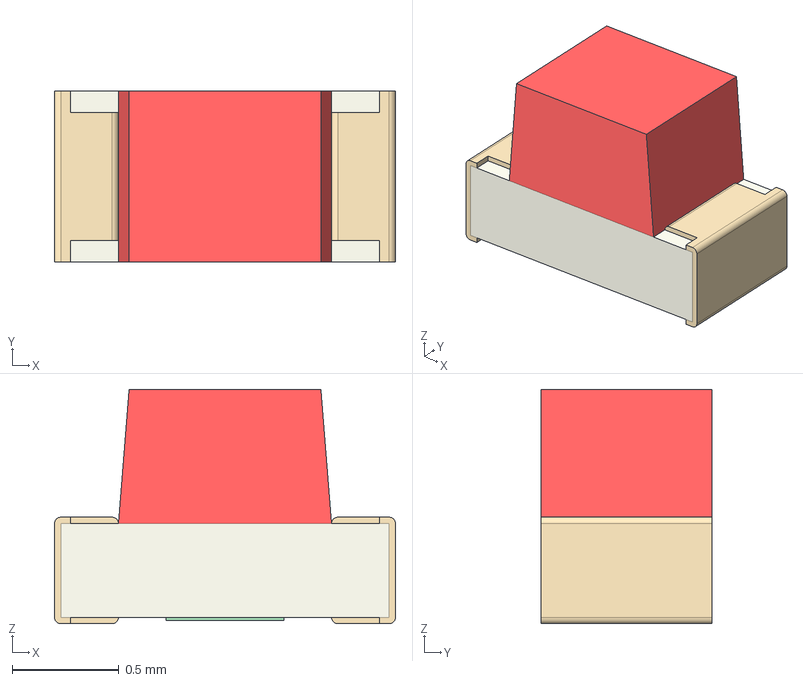
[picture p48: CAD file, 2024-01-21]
3d_models/LED_0603_RED.step
1.60 x 0.8 x 1.10 mm

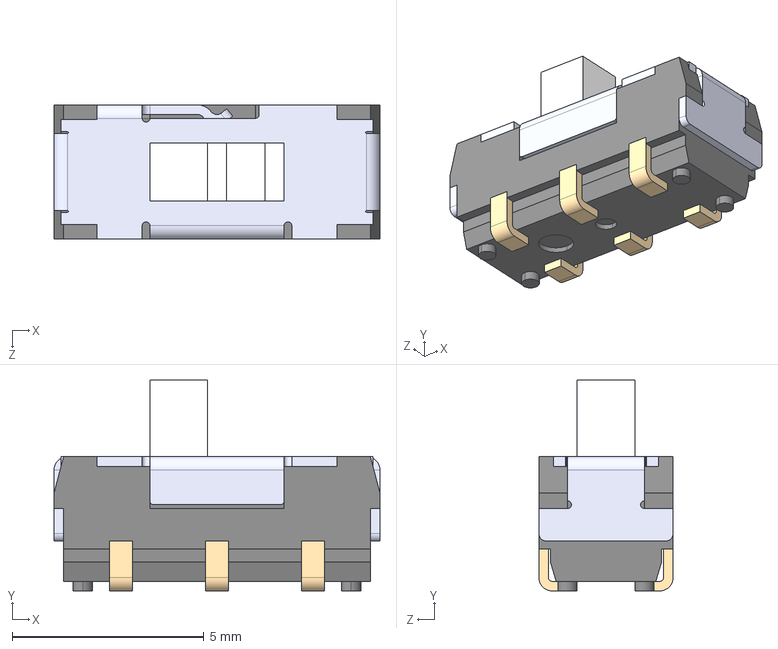
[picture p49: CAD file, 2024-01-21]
3d_models/alpsalpine_SSSS213202.step
8.50 x 5.50 x 3.50 mm

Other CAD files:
3d_models/LED_D3.0mm_spacer_green.step
3d_models/LED_D3.0mm_spacer_red.step
3d_models/LED_0603_BLUE.step
3d_models/LED_0603_YELLOW-GREEN.step
3d_models/LED_0603_ORANGE.step
3d_models/LED_0603_GREEN.step
3d_models/D_SOD-323-bidirectional.step
3d_models/D_SOD-323.step
3d_models/ECS-240-20-30B-TR.step
3d_models/JS102011SCQN.step
3d_models/K2-1109SP-A4SA-04.f3d
3d_models/K2-1109SP-I4SA-04.f3d
3d_models/LED_0603_YELLOW.step
3d_models/SW_PUSH_6mm_H9.f3d
3d_models/USB4110GFA.step
3d_models/XKB-Connectivity_SS-3235D-03-L3.f3d
3d_models/alpsalpine_skrp.stp
3d_models/ss-12sdp2.stp
enclosure/old/4mm_offset.dxf
enclosure/old/light-pipe.f3d
enclosure/old/light-pipe.step
enclosure/old/render/board_cutout_4mm_offset.dxf
enclosure/old/render/drawing.dxf.dxf
enclosure/old/tiny-scarab-v0.2-block.f3d
enclosure/old/tiny-scarab-v0.2-block.step
enclosure/old/tiny-scarab-v0.2-board.f3d
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

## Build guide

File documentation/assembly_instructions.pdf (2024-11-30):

# Assembly instructions

## 1. Metal Block

Cut a strip of double-sided tape and glue it at the bottom of the 3D-printed case.

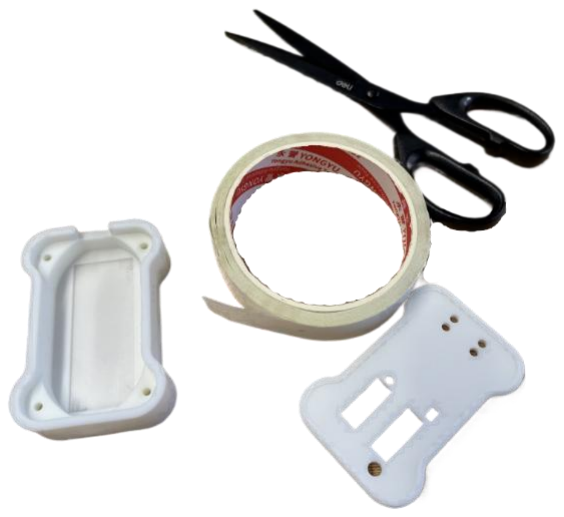
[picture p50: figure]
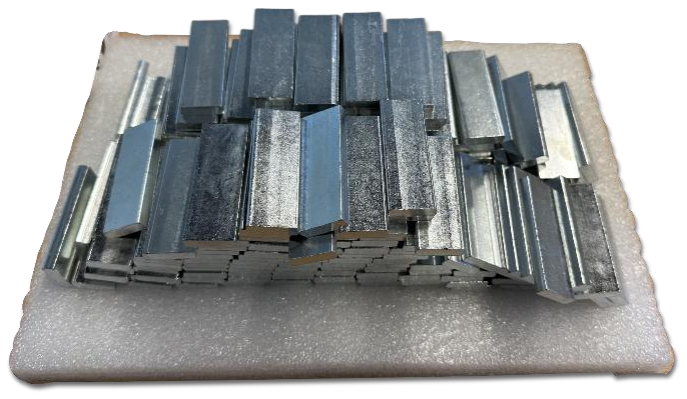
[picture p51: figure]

Then take a metal block and press it onto the double-sided tape:

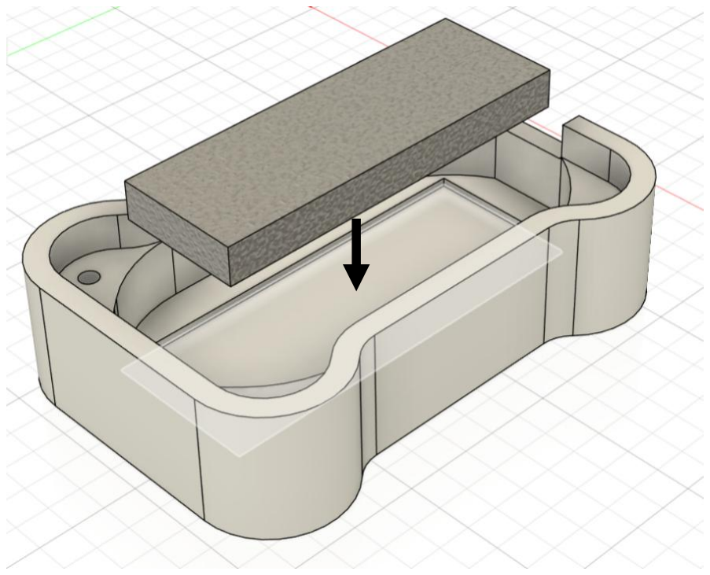
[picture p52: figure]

## 2. Place Board

Insert the circuit board in the 3D-printed case:

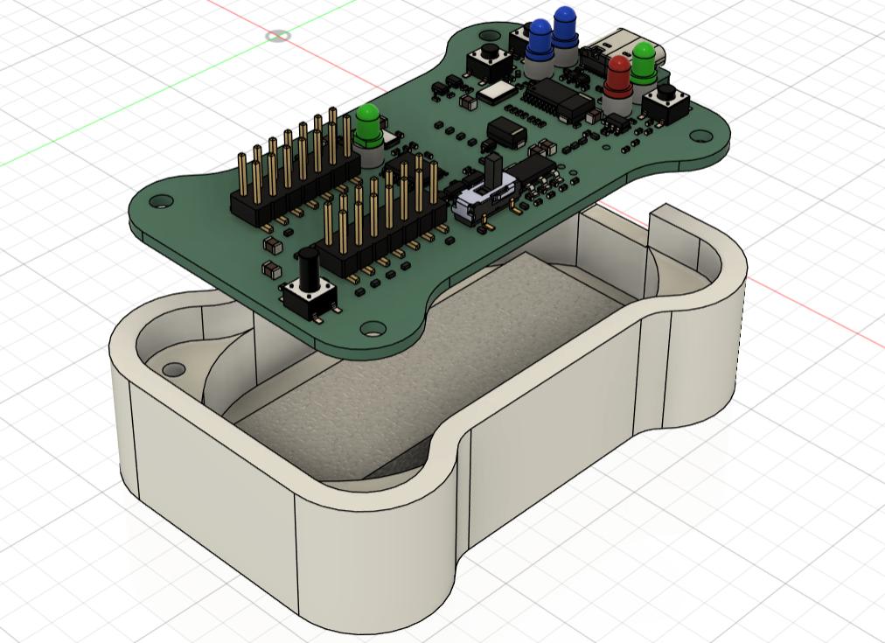
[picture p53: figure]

Do not use any screws at this point. The screws come in the end.

## 3. Flash Firmware

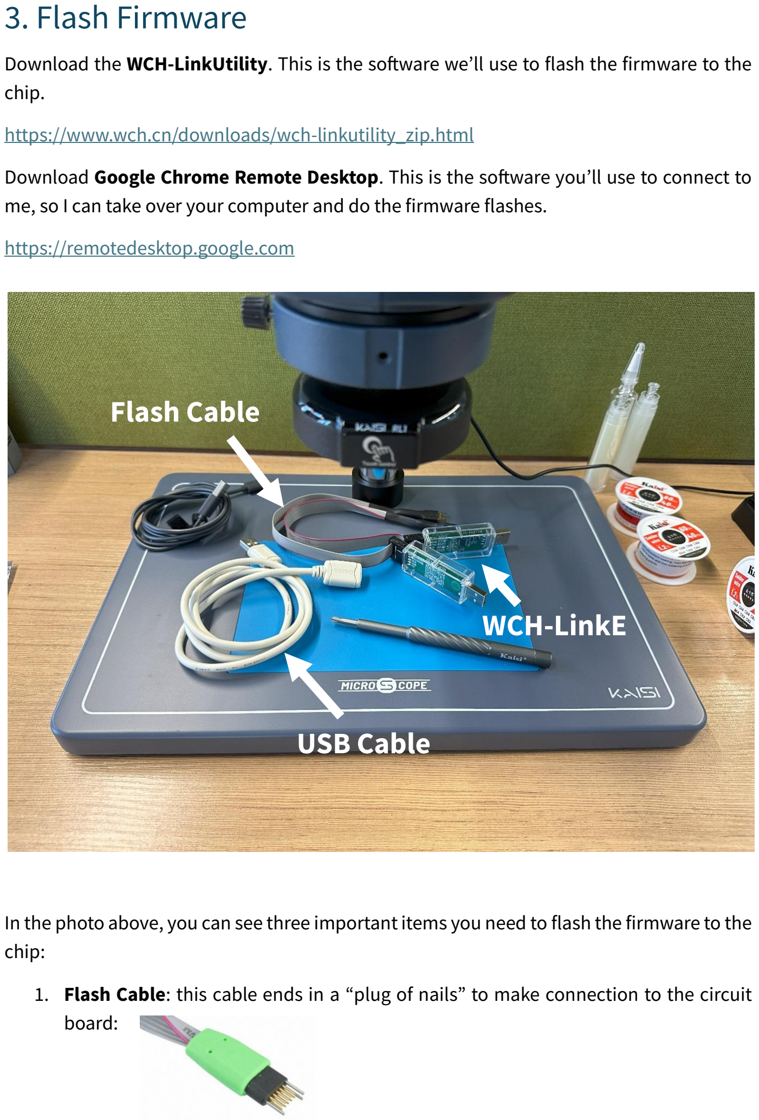
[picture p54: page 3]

Download the WCH-LinkUtility. This is the software we’ll use to flash the firmware to the chip.

https://www.wch.cn/downloads/wch-linkutility_zip.html

Download Google Chrome Remote Desktop. This is the software you’ll use to connect to me, so I can take over your computer and do the firmware flashes.

https://remotedesktop.google.com

In the photo above, you can see three important items you need to flash the firmware to the chip:

1. Flash Cable: this cable ends in a “plug of nails” to make connection to the circuit board:

## USB Cable

## WCH-LinkE

## Flash Cable

2. WCH-LinkE: this device should be plugged into your laptop:
3. USB Cable: Plugging the WCH-LinkE device into your laptop directly can be challenging, because of the flash cable on the other side. Use this USB Cable for your convenience.

Push the nails of the Flash Cable onto the Circuit Board:

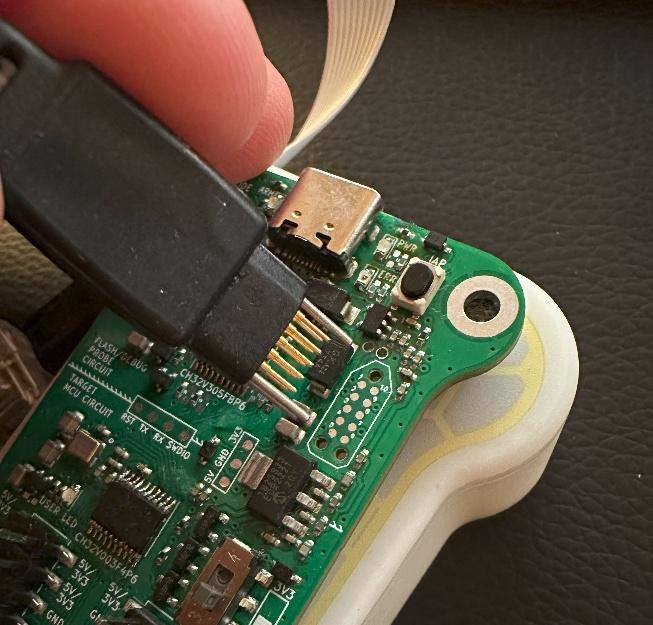
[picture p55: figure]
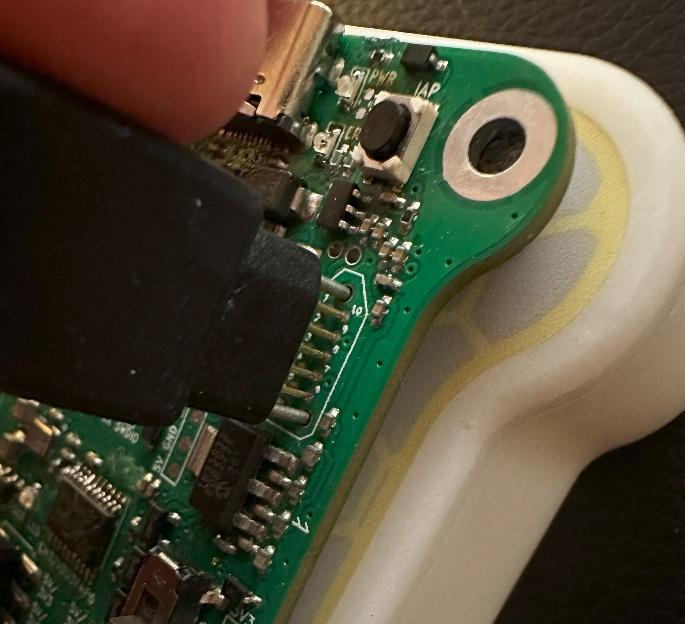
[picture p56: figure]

In the figure above, the circuit board is taken out of the 3D-printed case. There is no need to do that (I simply didn’t have any other photo). Just leave the board inside the 3D-printed case while you push the Flash Cable on it.

Launch the WCH-LinkUtility software on your laptop. Then launch Google Chrome Remote Desktop. I will take over your computer for a moment and do the flashing for you. You need to keep the Flash Cable pressed onto the Circuit Board during the flash procedure.

## 4. Close the Solder Bridge

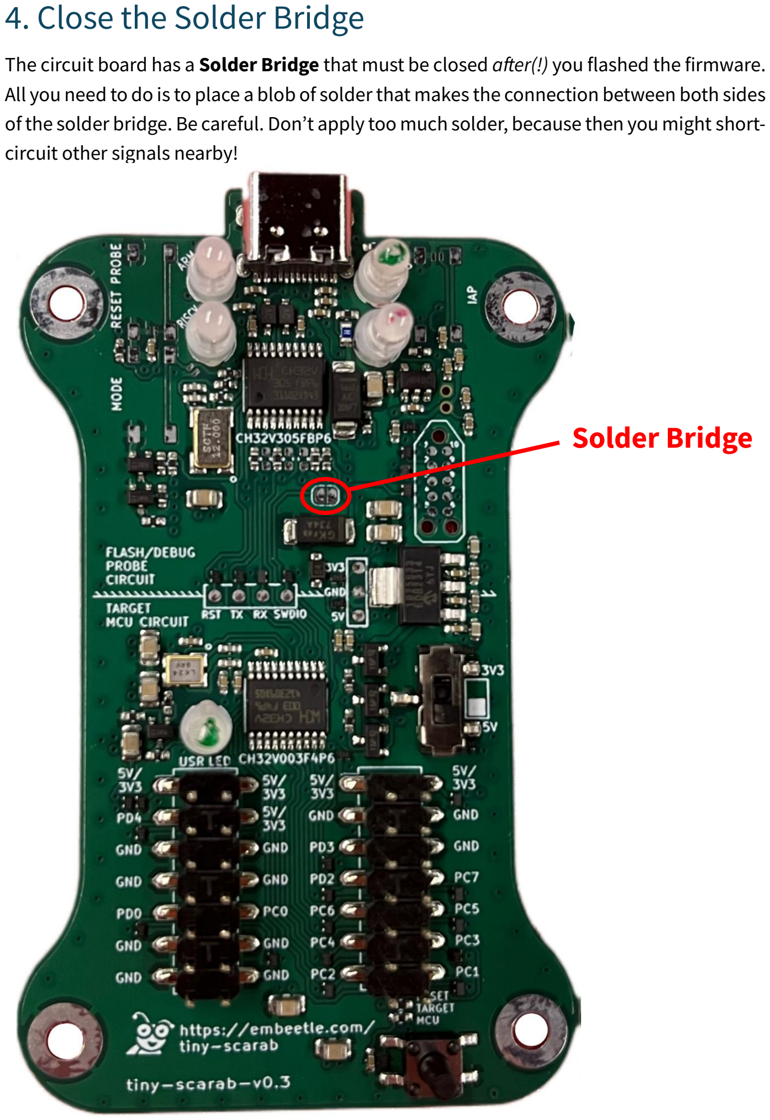
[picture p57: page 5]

The circuit board has a Solder Bridge that must be closed after(!) you flashed the firmware. All you need to do is to place a blob of solder that makes the connection between both sides of the solder bridge. Be careful. Don’t apply too much solder, because then you might shortcircuit other signals nearby!

## Solder Bridge

## 5. Close Lid and Glue Graphical Membrane

## Graphical

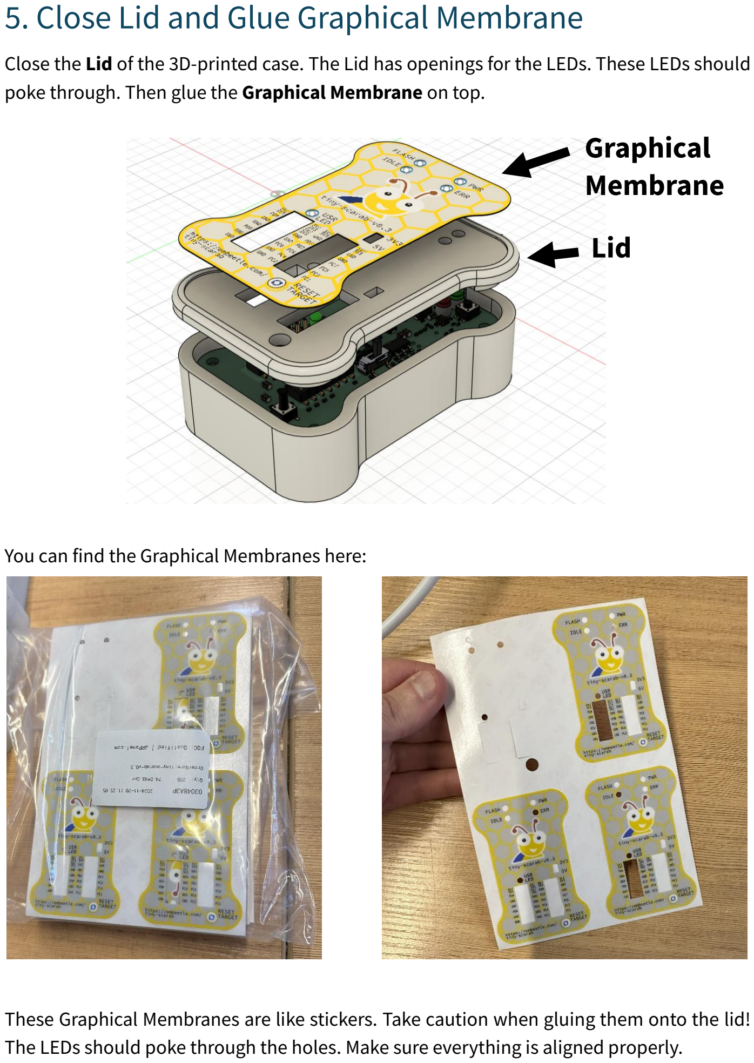
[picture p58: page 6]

Close the Lid of the 3D-printed case. The Lid has openings for the LEDs. These LEDs should poke through. Then glue the Graphical Membrane on top.

You can find the Graphical Membranes here:

These Graphical Membranes are like stickers. Take caution when gluing them onto the lid! The LEDs should poke through the holes. Make sure everything is aligned properly.

## Membrane

## Lid

## 6. Screws

Take four screws from the box and take the Screwdriver:

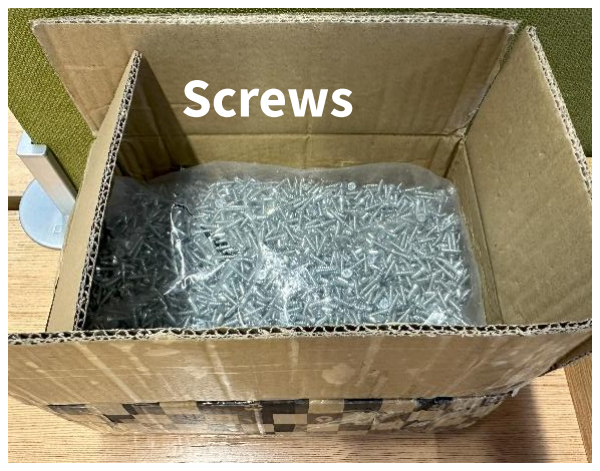
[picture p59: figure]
Screws
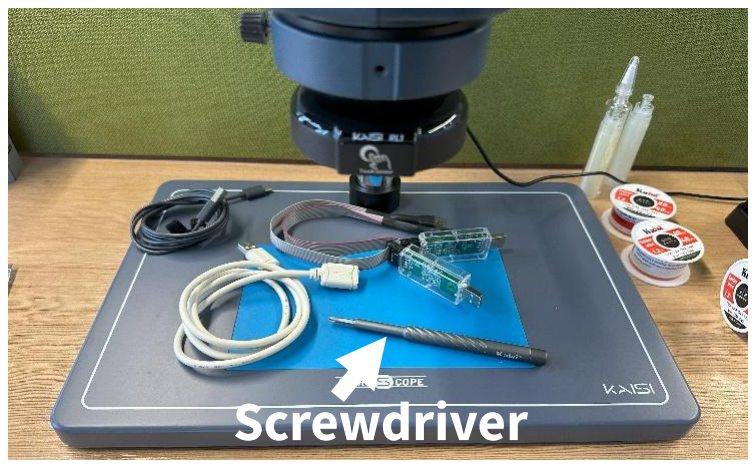
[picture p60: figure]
Screwdriver

Insert the four screws in the bottom of the 3D-printed case:

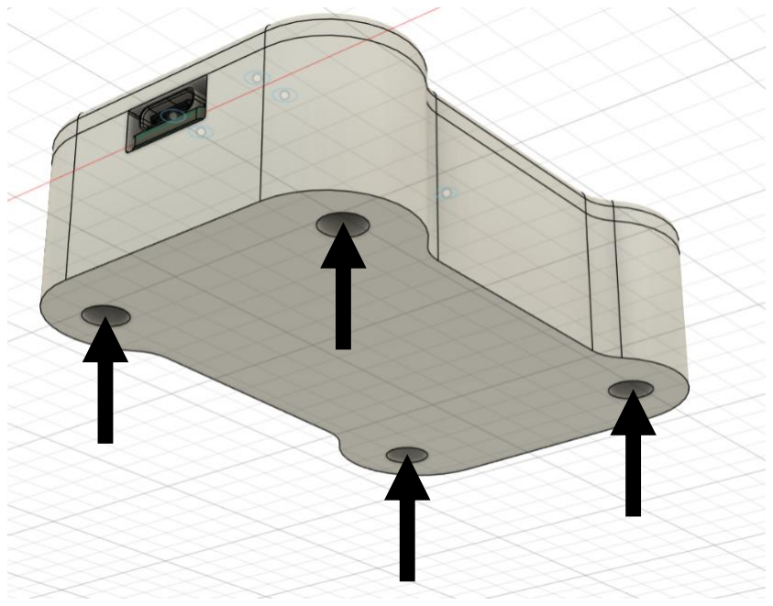
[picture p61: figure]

Screw until the lid is relatively fixed. DO NOT APPLY TOO MUCH FORCE! With too much force, the plastic will no longer hold the screw.

## 7. Packing

Use the protective plastic (bubble wrap and the white foamy plastic) from this box, and wrap it around the 3D-printed case:

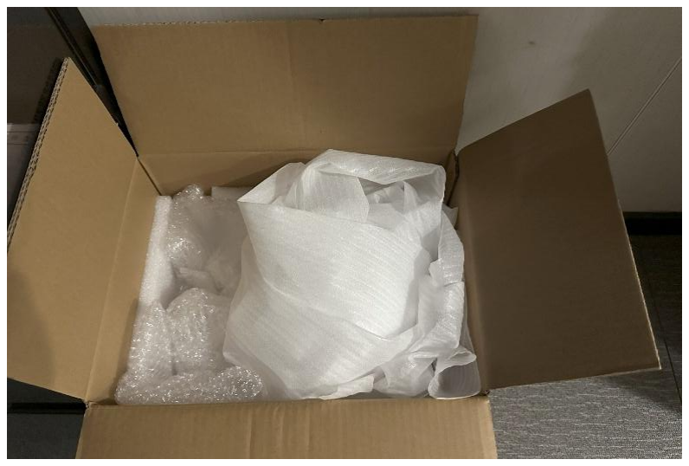
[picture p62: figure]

Then shove the 3D-printed case into the cardboard box:

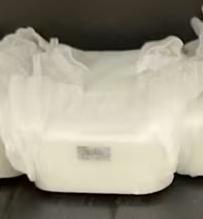
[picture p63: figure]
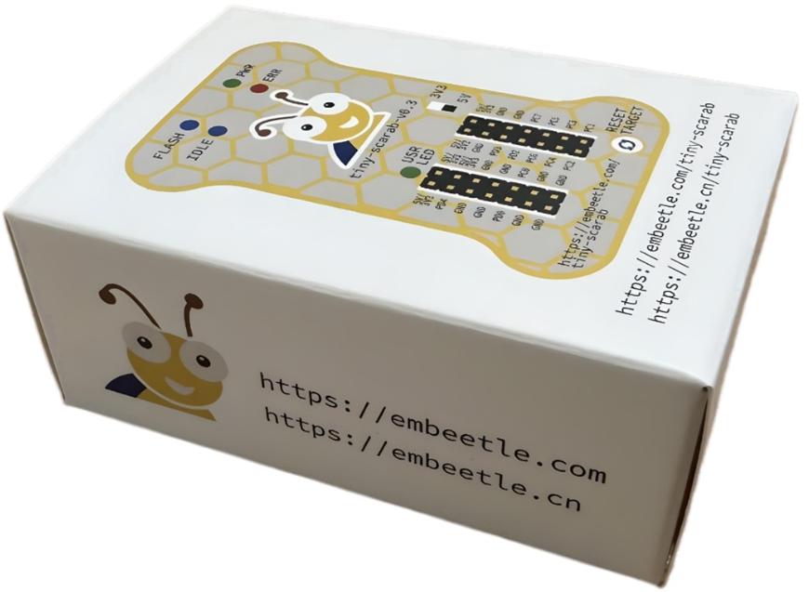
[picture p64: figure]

Last but not least: put some bubble wrap (or the whitefoamy plastic) around the cardboard box to protect it from damage during shipping.

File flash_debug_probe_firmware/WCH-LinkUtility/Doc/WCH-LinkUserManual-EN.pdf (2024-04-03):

WCH-LinkUserManual | https://wch-ic.com

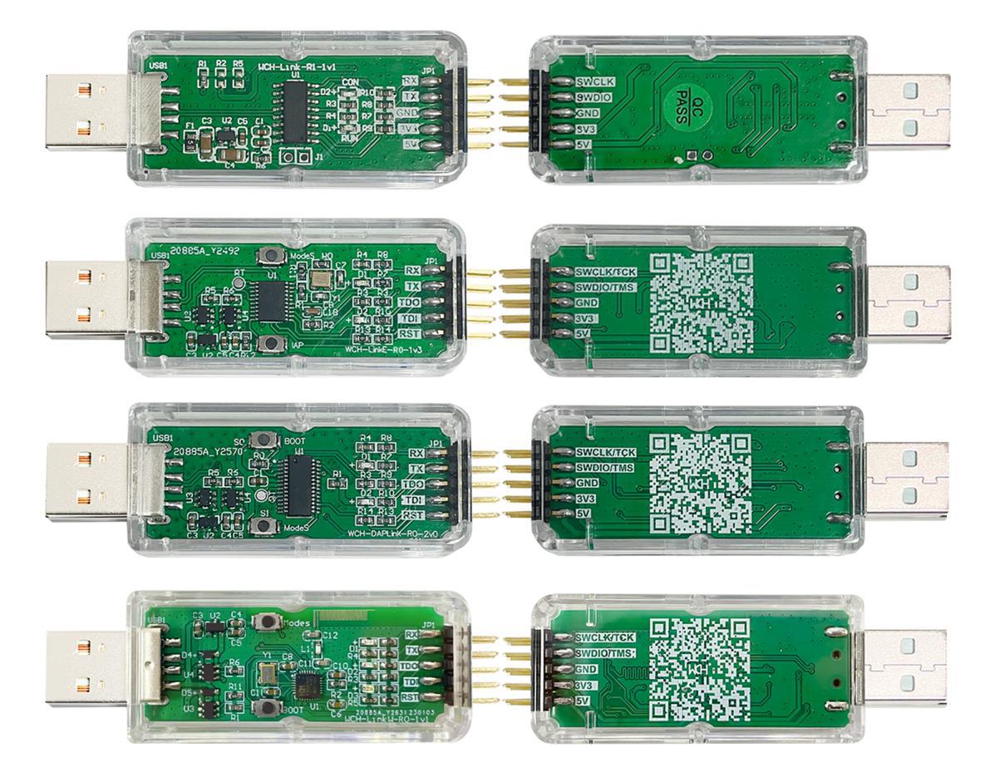
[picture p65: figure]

V1.9 | 1

## WCH-LinkUserManual

Version: V1.9
http://wch-ic.com

## 1 WCH-Link

### 1.1 Module Introduction

WCH-Link module can be used for online debugging and downloading of WCH RISC-V MCU, and also for online debugging and downloading of ARM MCU with SWD/JTAG interface. It also comes with a serial port for easy debugging output. There are 4 kinds of WCH-Link including WCH-Link, WCH-LinkE, WCH-DAPLink and WCH-LinkW, as shown in Figure 1.
Figure 1 WCH-Link physical diagram

Figure 2 WCH-Link mode

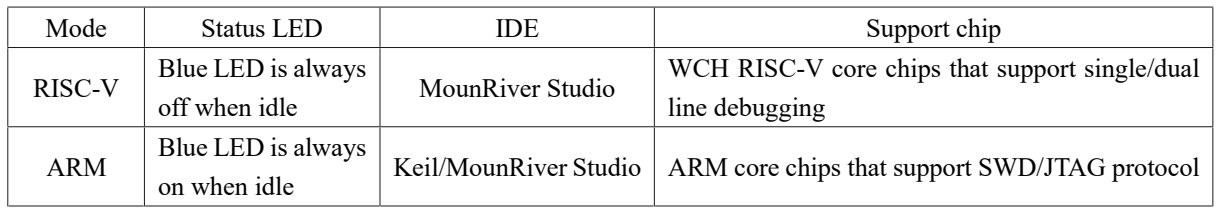
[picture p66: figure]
Mode; Status LED; IDE; Support chip; RISC-V; Blue LED is always off when idle; MounRiver Studio; line debugging; ARM; Blue LED is always on when idle
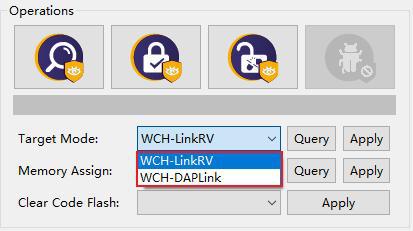
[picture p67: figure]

V1.9 | 2

Table 1 WCH-Link mode

WCH RISC-V core chips that support single/dual

Keil/MounRiver Studio ARM core chips that support SWD/JTAG protocol

### 1.2 Mode Switching

Way 1: Use MounRiver Studio software to switch Link mode. (This method is applicable to WCH-Link, WCH-LinkE and WCH-LinkW)

① Click arrow | in the shortcut toolbar to bring up the project download configuration window

② Click Query on the right side of Target Mode to view the current Link mode
③ Click Target Mode option box, select the target Link mode, click Apply

Way 2: Use WCH-LinkUtility tool to switch Link mode.
① Click Get on the right side of Active WCH-Link mode to view the current Link mode ② Click Active WCH-Link mode option box, select the target Link mode, click Set

Way 3: Use ModeS key to switch Link mode. (This method is applicable to WCH-LinkE-R0-1v2, WCH-DAPLink-R0-2v0 and WCH-LinkW-R0-1v1 and above)
① Press and hold the ModeS key to power up the Link

Notes:
(1) The blue LED flashes when downloading and debugging.
(2) The Link maintains the switched mode for subsequent use.
(3) WCH-Link simulation debugger module URL: https://www.wch-ic.com/products/WCH-Link.html
(4) MounRiver Studio Access URL: http://mounriver.com/
(5) WCH-LinkUtility Access URL: https://www.wch.cn/downloads/WCH-LinkUtility_ZIP.html
(6) WCHISPTool Access URL: https://www.wch.cn/downloads/WCHISPTool_Setup_exe.html
(7) WCH-Link, WCH-LinkE and WCH-LinkW support LinkRV and LinkDAP-WINUSB mode switching; WCH-DAPLink supports LinkDAP-WINUSB and LinKDAP-HID mode switching.

V1.9 | 3

### 1.3 Serial Port Baud Rate

Table 2 WCH-Link serial port supports baud rate
1200 | 2400 | 4800 | 9600 | 14400
19200 | 38400 | 57600 | 115200 | 230400

Table 3 WCH-LinkE/DAPLink/LinkW serial port supports baud rate
1200 | 2400 | 4800 | 9600 | 14400 | 19200
38400 | 57600 | 115200 | 230400 | 460800 | 921600

Notes:
(1) Figure 1 in the row of pins RX and TX for the serial port transceiver pins, serial port support baud rate is shown in the table above.
(2) CDC driver needs to be installed under Win7.
(3) If you re-unplug Link, please re-open the serial debugging assistant.

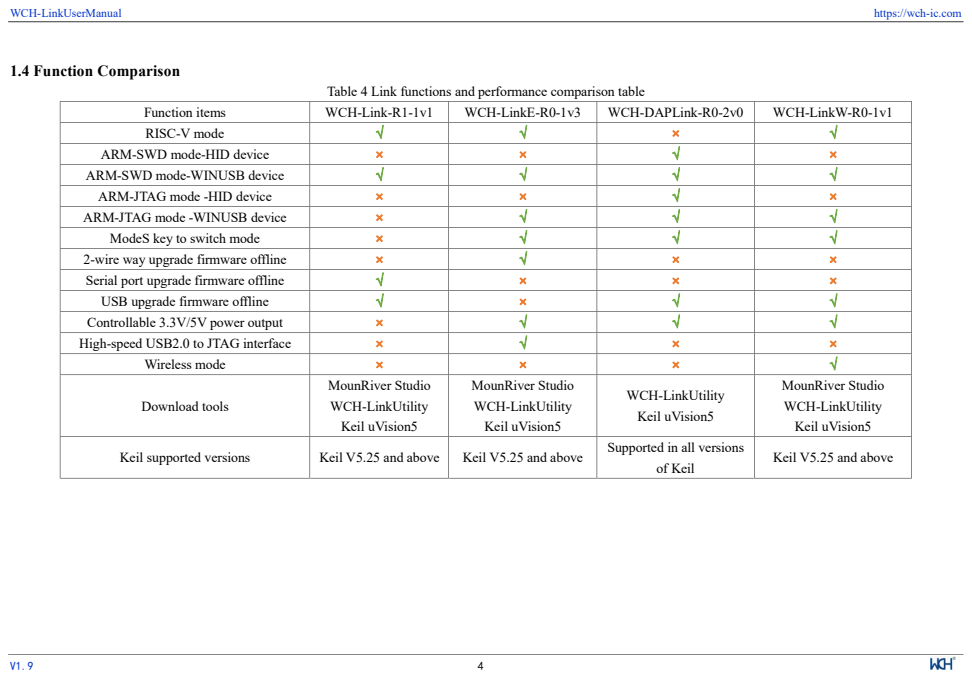
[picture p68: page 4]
1.4 Function Comparison; Function items; WCH-Link-R1-1v1; WCH-LinkE-R0-1v3; WCH-DAPLink-R0-2v0; WCH-LinkW-R0-1v1; Wireless mode; Download tools; MounRiver Studio WCH-LinkUtility Keil uVision5; WCH-LinkUtility Keil uVision5; Keil supported versions; Keil V5.25 and above; of Keil

Table 4 Link functions and performance comparison table

RISC-V mode
ARM-SWD mode-HID device
ARM-SWD mode-WINUSB device
ARM-JTAG mode -HID device
ARM-JTAG mode -WINUSB device
ModeS key to switch mode
2-wire way upgrade firmware offline
Serial port upgrade firmware offline
USB upgrade firmware offline
Controllable 3.3V/5V power output
High-speed USB2.0 to JTAG interface

Supported in all versions

Keil V5.25 and above

## 2 Pin Connections

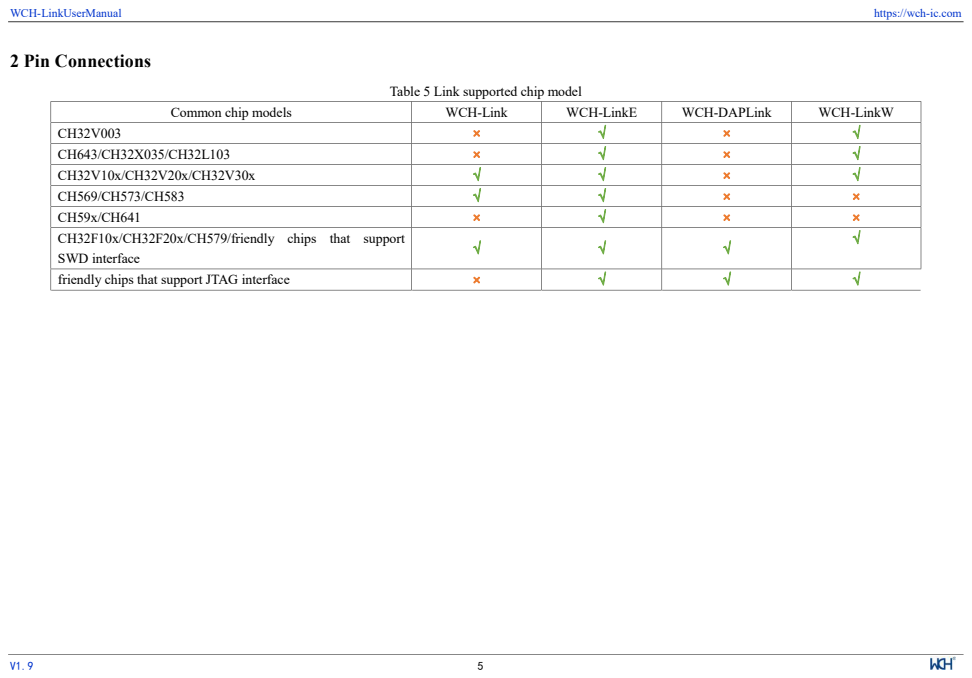
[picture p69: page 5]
Common chip models; WCH-Link; WCH-LinkE; WCH-DAPLink; WCH-LinkW

Table 5 Link supported chip model

CH32F10x/CH32F20x/CH579/friendly chips that support
SWD interface
friendly chips that support JTAG interface

V1.9 | 6

Table 6 Common chip pin connections
Common chip models | SWDIO | SWCLK
CH569 | PA11 | PA10
CH579 | PB16 | PB17
CH573/CH583/CH59x | PB14 | PB15
CH643/CH32X035 | PC18 | PC19
CH32V003 | PD1 | -
CH641 | PB0 | -
CH32V10x/CH32V20x/CH32V30x/CH32F10x/CH32F20x/CH32L103 | PA13 | PA14

Table 7 STM32F10xxx JTAG interface pinout
JTAG interface pin name | JTAG debug interface | Pinout
TMS | JTAG mode selection | PA13
TCK | JTAG clock | PA14
TDI | JTAG data input | PA15
TDO | JTAG data output | PB3

Notes:
(1) Link maximum supported line length: 30cm, if the download process is unstable, try to turn down the download speed.
(2) JTAG mode, WCH-LinkE-R0-1v3, WCH-DAPLink-R0-2v0 hardware version began to support, the previous hardware version does not support.
(3) WCH-LinkE high-speed version is only for CH32F20x/CH32V20x/CH32V30x to speed up.
(4) CH569、CH579、CH573、CH583、CH59x, if you want to use Link for downloading or debugging, you need to use the official ISP tool to open the 2-wire debug interface, and you need to pay attention to Link mode when using it. The steps are as follows:
- Open WCHISPStudio tool, the chip to be tested enters BOOT mode
-CH569 needs to short HD0 and GND to power on through U-port;
-CH573/CH583/CH59x need to press and hold the Download button to power on through the U-port;
- WCHISPStudio tool will automatically pop up the adaptation window, click to open the two-wire debug interface

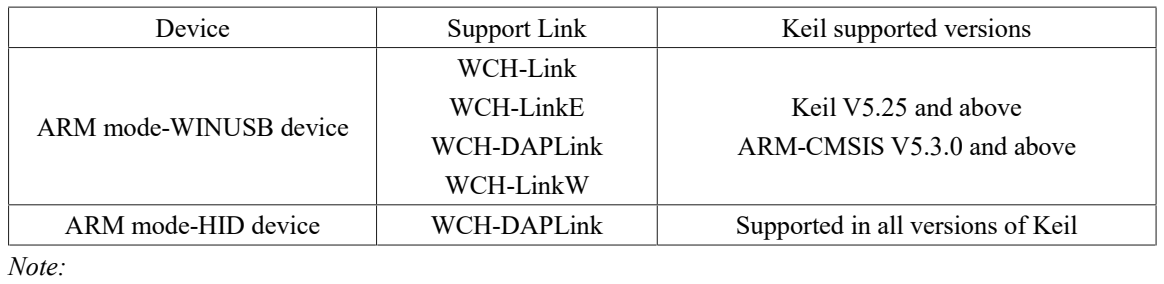
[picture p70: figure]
Device; Support Link; Keil supported versions; ARM mode-WINUSB device; WCH-Link WCH-LinkE WCH-DAPLink WCH-LinkW; Keil V5.25 and above ARM-CMSIS V5.3.0 and above; Note:

V1.9 | 7

## 3 Keil Download and Debug

### 3.1 Device Switching

WCH-DAPLink supports two modes, ARM mode-WINUSB device and ARM mode-HID device, and you can switch between the two device modes with the WCH-LinkUtility tool (or by powering up the Link after long pressing the ModeS key.) WCH-Link, WCH-LinkE and WCH-LinkW only support ARM mode-WINUSB device mode.

Table 8 WCH-DAPLink device

ARM mode-HID device | WCH-DAPLink | Supported in all versions of Keil
(1) WCH-Link, WCH-LinkE, WCH-DAPLink and WCH-LinkW are factory defaulted to WINUSB device mode.
(2) WCH-DAPLink-R0-1v0 switches between two device modes by long pressing the IAP key to power up.
(3) WCH-LinkUtility tool on will occupy the Link device and cause Keil software can not recognize the Link.

### 3.2 Download Configuration

① Click the magic wand in the toolbar to bring up the Options for Target dialog box, click Debug and

select the emulator model

② Click the Use option box and select CMSIS-DAP Debugger
③ Click the Settings button to bring up the Cortex-M Target Driver Setup dialog box

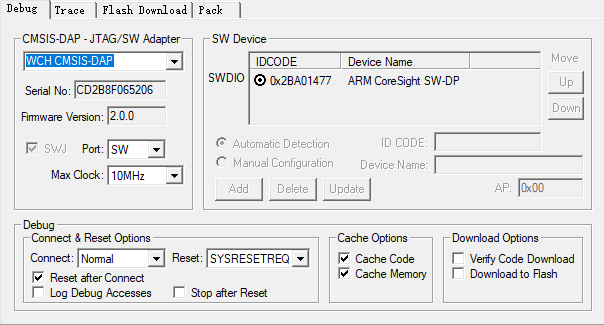
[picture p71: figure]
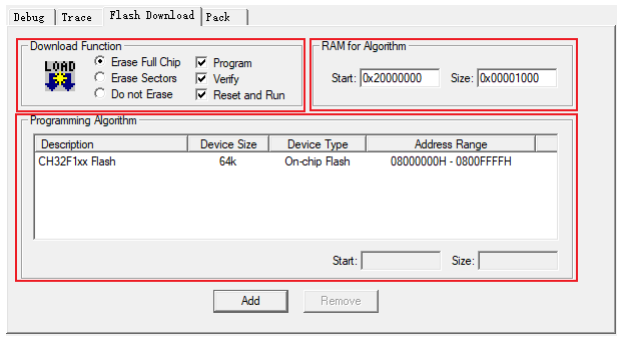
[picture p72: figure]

V1.9 | 8

Serial No: Display the identifier of the debug adapter being used. When multiple adapters are connected, you can specify the adapter by using the drop-down list.
SW Device: Show the device ID and name of the connected device.
Port: Set the internal debug interface SW or JTAG. (Both interfaces are supported by WCH-LinkE-R0-1v3, WCH-DAPLink-R0-2v0 and WCH-LinkW-R0-1v1)
Max Clock: Set the clock rate to communicate with the target device.

④ Click Flash Download for download configuration

Download Function: Configuration options
RAM for Algorithm: Configure the starting address and size of RAM space
Our CH32F103 series chip RAM space size is 0x1000, CH32F20x series chip RAM space size is 0x2800. Programming Algorithm: Add algorithm file
The algorithm file has been added automatically after installing the chip device package, click OK.

⑤ After completing the above configuration, click OK to close the dialog box. Click the icon in the toolbar to burn in the code.

### 3.3 Debug

① Click the Debug button in the toolbar to enter the debug page

② Set breakpoints

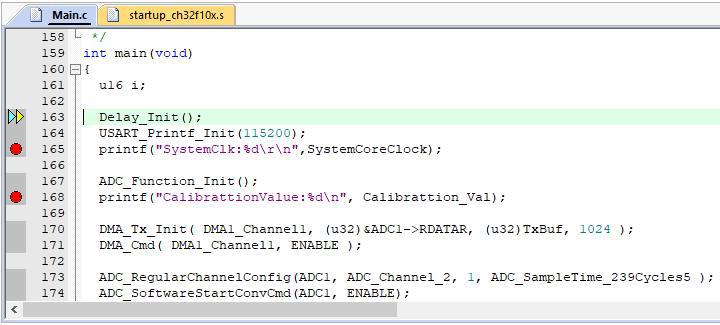
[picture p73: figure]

V1.9 | 9

③ Basic debug commands

Reset: Perform a reset operation on the program.

Run: Cause the current program to start running at full speed until the program stops when it encounters

a breakpoint.

Step: Execute a single statement and if a function is encountered, it will go inside the function.

Step Over: Execute a single statement that does not go inside the function if it encounters a function, but

runs the function at full speed and jumps to the next statement.

Step Out: Run all the contents after the current function at full-speed until the function returns to the

previous level.

④ Click the Debug button in the toolbar again to exit debug.

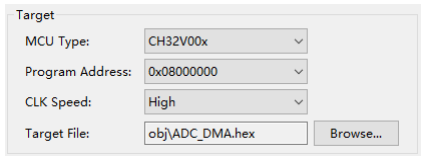
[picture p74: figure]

V1.9 | 10

## 4 MounRiver Studio Download and Debug

### 4.1 Download Configuration

① Click the arrow | in the toolbar to bring up the project download configuration window

② Click the Disable Read-Protect button to disable the chip read protection

③ Target configuration, the main elements are as follows.

④ Configuration Options

⑤ Click Apply and Close to save the download configuration. Click on the icon in the toolbar to burn the code, and the result will be displayed in the Console.

### 4.2 Debug

① Enter the debugging page

Way 1: Click the Debug button | in the toolbar to enter the debug page directly.
Way 2: Click the arrow | in the toolbar and select Debug Configurations to pop up the debug

configuration page. Double-click GDB OpenOCD MRS Debugging to generate the obj file, select the obj file and click the Debug button at the bottom right corner to enter the debugging page.

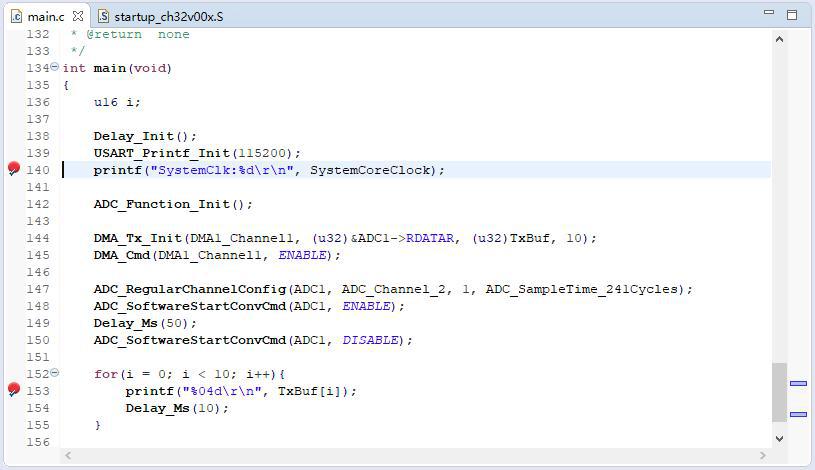
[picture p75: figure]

V1.9 | 11

② Set breakpoints

③ Basic debug commands

Reset: Perform a reset operation on the program.

Run: Make the current program start running at full speed until the program stops when it meets a

breakpoint.

Terminate: Exit debugging.

Step Into: Execute a single statement, and if a function is encountered, it will go inside the function.

Step Over: Execute a single statement, and if it encounters a function, it will not go inside the function,

but run the function at full speed and skip to the next statement.

Step Return: Run all contents after the current function at full speed until the function returns to the

previous level.

④ Click button, exit the debug.

### 4.3 Other Functions

### 4.3.1 Set Chip Read-Protect

Query chip read-protect status

Enable chip read-protect status

Disable chip read-protect status

### 4.3.2 Code Flash Full Erase

MounRiver Studio can erase all the user areas of the chip by controlling the hardware reset pin or by re-powering the chip. To control erase by re-powering, Link is required to power the chip; to control erase by

V1.9 | 12

hardware reset pin, the reset pins of the chip and Link need to be connected. (Supported by WCH-LinkE, WCH-DAPLink and WCH-LinkW only)

### 4.3.3 Disable 2-wire SDI

For chips other than CH32 series, code and data protection can be enabled by disabling the 2-wire SDI.

Disable the 2-wire SDI

### 4.3.4 Chip Memory Allocation

For high-capacity general-purpose (connected/interconnected/wireless) chips, memory allocation is available through MounRiver Studio; please refer to the User Selection Word section of the CH32FV2x_V3xRM manual for details.

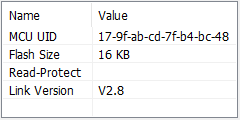
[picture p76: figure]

V1.9 | 13

## 5 WCH-LinkUtility Download

### 5.1 Download Configuration

① Click the icon , connect to Link ② Select the chip model

③ Configuration options

④ Release chip read protection and set two-line debug speed

⑤ Click icon | to add firmware
⑥ Click icon | to execute download

### 5.2 Other Functions

### 5.2.1 Query Chip Information

Click icon to query chip information

### 5.2.2 Set Chip Read-Protect

Query chip read-protect status

Enable chip read-protect status

Disable chip read-protect status

### 5.2.3 Read Chip Flash

Click icon | to read chip Flash

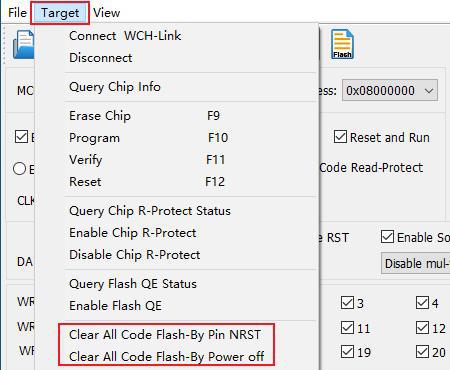
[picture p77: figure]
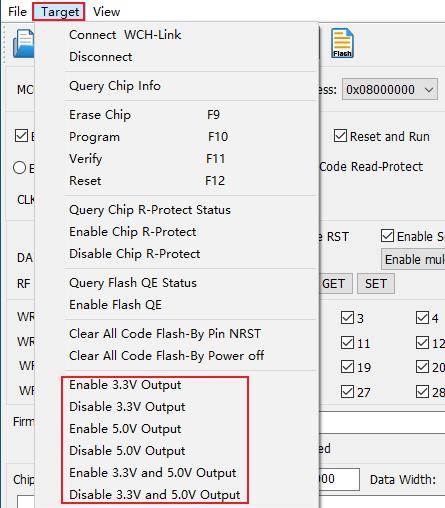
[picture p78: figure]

V1.9 | 14

### 5.2.4 Code Flash Full Erase

The WCH-LinkUtility tool can erase all user areas of the chip by controlling the hardware reset pin or by re-powering the chip. To control erase by re-powering, Link is required to power the chip; to control erase by hardware reset pin, the reset pins of the chip and Link are required to be connected. (Supported by WCH-LinkE, WCH-DAPLink and WCH-LinkW only)

### 5.2.5 Power Output Controllable

WCH-LinkUtility tool can control Link power output. Click on Target and choose to turn on/off the power supply 3.3V/5V output in the drop-down list. (Supported by WCH-LinkE, WCH-DAPLink and WCH-LinkW only)

### 5.2.6 Automatic Continuous Download

Tick Auto download when WCH-Link was linked to enable automatic continuous download of the project.

### 5.2.7 Multi-Device Download

The WCH-LinkUtility tool can recognize multiple Link devices. When multiple Links are connected, the Connected WCH-Link List option box allows you to select a specific Link device for downloading.

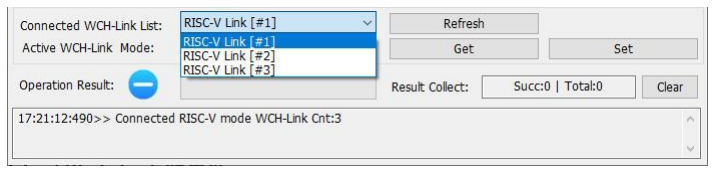
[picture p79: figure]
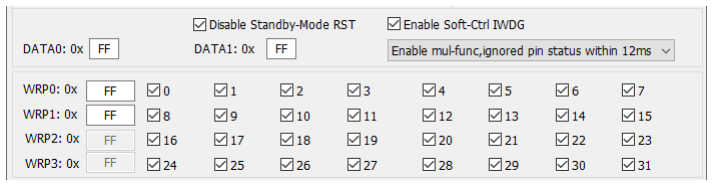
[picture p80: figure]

V1.9 | 15

### 5.2.8 Turn off the 2-wire Debug Interface

For chips other than CH32 series, code and data protection can be enabled by closing the two-wire debug interface.

### 5.2.9 User Select Word Configuration

For CH32 series chips, user selectable word configuration can be done through the WCH-LinkUtility tool. For details, please refer to the user selectable word section in the RM manual.

### 5.2.10 BOOT Download

For CH32V003, CH641 chip, you can select program download to program flash memory storage or system storage by WCH-LinkUtility tool.

### 5.2.11 SDI Virtual Serial Port Function

This function uses the SDI interface to realize the chip printout function, which needs to modify the printing function. Refer to the SDI_Printf routine in the relevant EVT. This function is only supported in V1.80 and above. You need to check EnableSDIPrintf and open the COM port of WCH-LinkE.

V1.9 | 16

Note:
(1) This feature is only supported in V1.80 and above.
(2) This feature is only supported by WCH-LinkE.
(3) The supporting chip includes CH32V003, CH32V103, CH32V20x, CH32V30x, CH32X035, CH32L103, CH641.

V1.9 | 17

## 6 Firmware Update Methods

### 6.1 MounRiver Studio Online Update

If the firmware needs to be updated, MounRiver Studio will have a pop-up window to remind you when you click the download button, click Yes to start the update.

### 6.2 WCH-LinkUtility Online Update

If the firmware needs to be updated, WCH-LinkUtility will have a pop-up window to remind you when you click the download button, click Yes to start the update.

Notes:
(1) WCH-LinkE supports manual online update, the steps are as follows.
- Power up the Link after long press the IAP button until the blue LED blinks.
- MounRiver Studio/WCH-LinkUtility will have a pop-up window to remind you when you click the download button, click Yes to start the update.
(2) If the Link firmware update is abnormal, please update the firmware by offline update.

### 6.3 WCH-LinkUtility Offline Update (2-wire Approach to Offline Update)

① Connect WCH-LinkE with WCH-LinkE to be updated
WCH-LinkE | Link to be updated
3V3 | 3V3
GND | GND
SWDIO | SWDIO
SWCLK | SWCLK
② WCH-LinkE power on, select the Link chip model to be updated (WCH-LinkE main control chip is CH32V30x)
③ To be updated Link into IAP mode (long press the IAP button to power up the Link, that is, through the USB port connected to the computer to power up)
④ Click Target->Clear All Code Flash-By Power off to erase all the user area of the chip

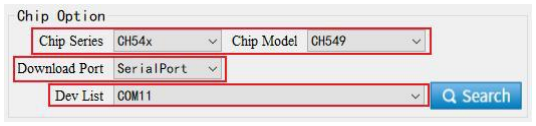
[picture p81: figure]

V1.9 | 18
⑤ Click icon | , diaable chip read-protect
⑥ Click icon | , add Link offline updated firmware
⑦ Configuration options (Program + Verify + Reset and Run)
⑧ Click icon | to execute download

Notes:
(1) The Link to be updated is limited to WCH-LinkE.
(2) Two WCH-LinkE are required for this method.
(3) When Link enters IAP mode, the blue LED flashes.

### 6.4 WCHISPStudio Serial Port Offline Update

① Connect WCH-Link with USB to TTL module
WCH-Link | USB to TTL module
TX | RX
RX | TX
GND | GND
② USB to TTL module power on, WCH-Link into BOOT mode (short connection J1 in Figure 1 will Link power on)
③ Select chip model: CH549, download interface: serial port, device list: select the serial port number corresponding to the USB to TTL module

④ Add Link offline updated firmware to target program file ⑤ Download configuration

⑥ Click the download button
⑦ Click on the download and wait for the device to access the field, then plug the WCH-Link into the USB port, the ISP tool automatically began to download
Note: Serial port offline update is only supported by WCH-Link.

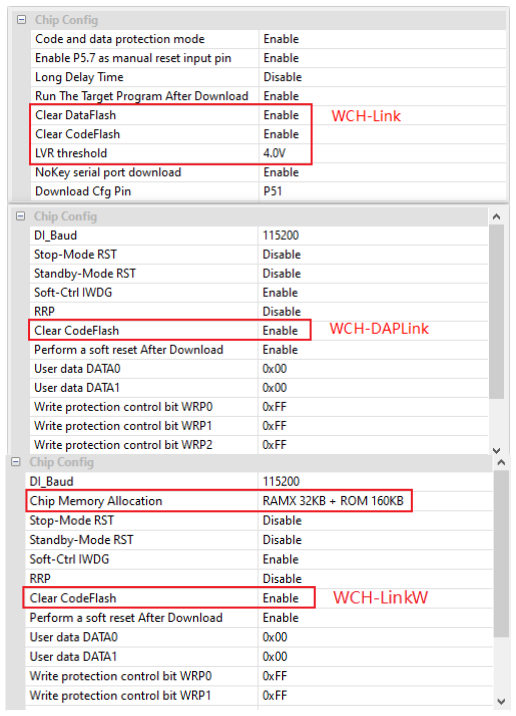
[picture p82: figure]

V1.9 | 19

### 6.5 WCHISPStudio USB Offline Update

① To update the Link into BOOT mode (short connect J1 in Figure 1 or long press BOOT key and then power up the Link)
② WCHISPStudio tool will automatically pop up the adaptation window
③ Add Link offline upgrade firmware to the target program file
④ Download configuration

⑤ Click the download button

Notes:
(1) USB offline update is only supported by WCH-Link, WCH-DAPLink and WCH-LinkW.
(2) WCH-LinkE-R0-1v3 and WCH-DAPLink-R0-2v0 are only available for firmware version v2.8 and above.
(3) WCH-LinkUtility tool can be exported through MounRiver Studio software.
(4) Link offline upgrade firmware is located in the MounRiver Studio installation path and WCH-LinkUtility installation path.

V1.9 | 20

① WCH-DAPLink upgrade firmware
② WCH-LinkW upgrade firmware
③ WCH-LinkE upgrade firmware
④ WCH-Link RISC-V mode upgrade firmware
⑤ WCH-Link ARM mode upgrade firmware
⑥ WCH-DAPLink offline upgrade firmware
⑦ WCH-Link ARM mode offline upgrade firmware ⑧ WCH-Link RISC-V mode offline upgrade firmware ⑨ WCH-LinkE offline upgrade firmware
⑩ WCH-LinkW offline upgrade firmware

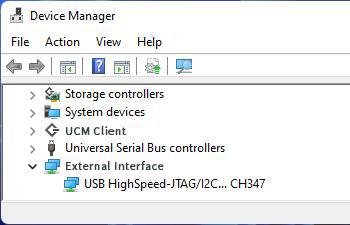
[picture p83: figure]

V1.9 | 21

## 7 WCH-LinkE High-speed JTAG

### 7.1 Module Overview

The WCH-LinkE-R0-1v3 provides a JTAG interface that supports 4-wire connections (TMS, TCK, TDI and TDO wires) for extending the JTAG interface for computers to operate CPUs, DSPs, FPGAs, CPLDs and other devices.
Figure 3 WCH-LinkE high-speed JTAG mode

### 7.2 Module Features

- As Host/Master host mode.
- JTAG interface provides TMS wire, TCK wire, TDI wire and TDO wire.
- Support high-speed USB data transfer.
- Flexible operation of CPU, DSP, FPGA and CPLD devices through computer API cooperation.

### 7.3 Module Switching

The WCH-LinkE-R0-1v3 can be upgraded to high-speed JTAG mode via the WCHLinkEJtagUpdTool tool, download the steps as follows.
① WCH-LinkE-R0-1v3 into IAP mode (long press the IAP button to power up the Link, i.e., connect to the computer through the USB port to power up), at this time the blue LED flashes.
② Open WCHLinkEJtagUpdTool tool, execute the download (WCH-LinkE high-speed JTAG upgrade firmware has been automatically added).
③ Firmware update is complete, at this time the blue LED is always on.

Notes.
(1) WCHLinkEJtagUpdTool get URL: https://www.wch.cn/downloads/WCHLinkEJtagUpdTool_ZIP.html
(2) The firmware can be updated offline by WCH-LinkUtility tool, please refer to manual 6.3 WCH-LinkUtility Offline Update for details.
(3) WCH-LinkE high-speed JTAG offline update firmware is located in the WCHLinkEJtagUpdTool installation path.

V1.9 | 22

① WCH-LinkE high-speed JTAG upgrade firmware
② WCH-LinkE high-speed JTAG offline upgrade firmware

### 7.4 Download Process

① In WCH-LinkE high-speed JTAG mode, the Bit program file is first downloaded to the FPGA via JTAG, and the Bit file will operate the SPI controller of the FPGA to convert the JTAG data to SPI data for writing to Flash, and this step is to write the BIN file to realize its program curing process.
② Here the FPGA is Xilinx xc7a35t. Write the CFG file and use "openocd -f" to call it. Name the CFG file as usb20jtag.cfg and save it to the location of the openocd.exe file.

# Specify WCH-LinkE high-speed JTAG debugger

adapter driver ch347
ch347 vid_pid 0x1a86 0x55dd

# Set TCK clock frequency

adapter speed 10000

# Specify TARGET, loading the JTAG-SPI driver in OpenOCD source [find cpld/xilinx-xc7.cfg]

source [find cpld/jtagspi.cfg]

# Set IR command of TARGET set XC7_JSHUTDOWN 0x0d

set XC7_JPROGRAM 0x0b
set XC7_JSTART 0x0c
set XC7_BYPASS 0x3f

# Download process

Init
# First download the Bit file to TARGET pld load 0 bscan_spi_xc7a35t.bit

reset halt
# Detect Flash information

flash probe 0
# Download Bin file to Flash

flash write_image erase test.bin 0x0 bin

# Effective firmware operation

irscan xc7.tap $XC7_JSHUTDOWN irscan xc7.tap $XC7_JPROGRAM runtest 60000

V1.9 | 23

runtest 2000
irscan xc7.tap $XC7_BYPASS runtest 2000

exit

③ Run the command: openocd.exe -f usb20jtag.cfg in Windows terminal and execute it as follows.

④ The download is over and the device is running normally.

Notes.
(1) conversion role of the Bit file, with the help of Github open source project: https://github.com/quartiq/bscan_spi_bitstreams
(2) openocd.exe file location: MounRiver\MounRiver_Studio\toolchain\OpenOCD\bin

## 8 WCH-LinkW Use Instruction

### 8.1 Module Overview

WCH-LinkW is a wired/wireless 2.4G dual imitation real debugger, which can be used for online debugging and downloading of WCH RISC-V architecture MCU and also for online debugging and downloading of ARM chips with SWD/JTAG interface.

### 8.2 Use Methods

### 8.2.1 Wired Mode

Wired mode only needs 1 WCH-LinkW, connect the row of pins to MCU and USB port to PC for downloading

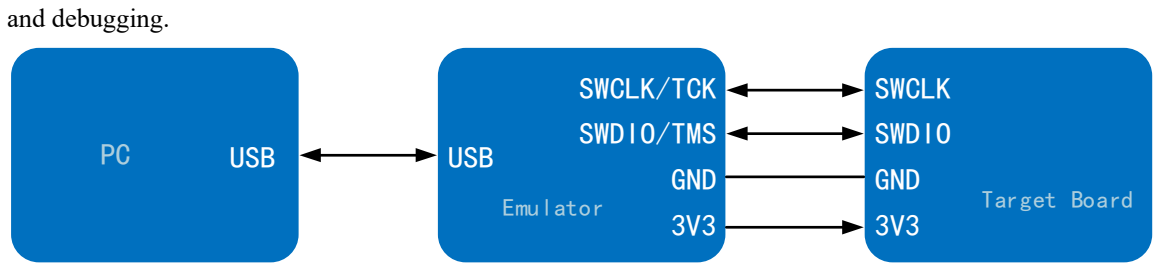
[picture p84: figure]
and debugging.; SWCLK/TCK; SWDIO/TMS; GND 3V3 Emulator; SWCLK; SWDIO; GND; Target Board; USB

### 8.2.2 Wireless Mode

Wireless mode requires 2 WCH-LinkW, divided into WCH-LinkW master (connected to computer) and WCH-LinkW slave (connected to MCU.) After WCH-LinkW is successfully enumerated to computer, it will detect whether there is a slave match within 2 seconds to switch mode, if there is a slave match, it will switch to wireless mode, and the green light will be on; otherwise, it will switch to wired mode, and the green light goes off.
Wireless mode download debugging requires the use of two WCH-LinkW, the use of the following steps:
① The slave and MCU are connected by two wires, and the power is supplied through the U-port of MCU, or the slave and MCU can be powered by charging head or mobile power connected to the USB port of the slave
② After the slave is successfully powered up, the host USB port is connected to the computer. After the host device is successfully enumerated and matched to the slave within 2 seconds, the green light of the host and the slave will be lit
③ After the successful matching of wireless mode host and slave, the host and slave are powered off, then repeat the above steps, if only one is powered off, it can be re-powered for automatic matching without

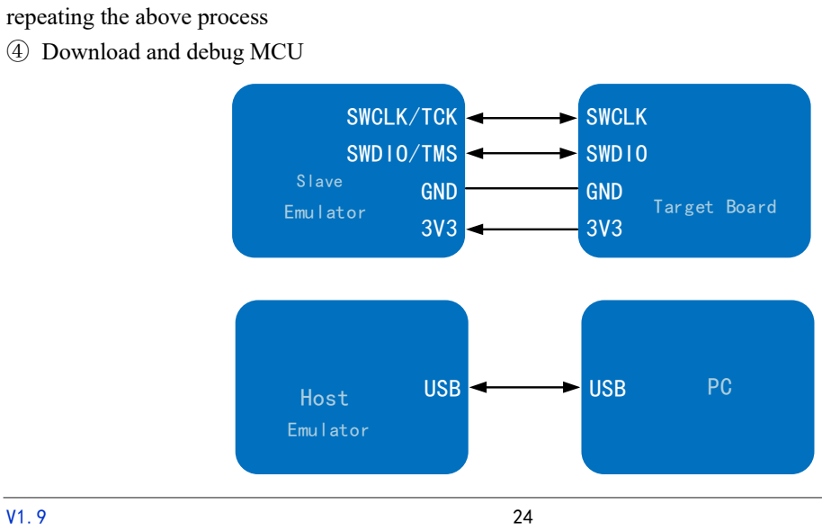
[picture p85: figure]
repeating the above process ④ Download and debug MCU; SWCLK/TCK SWDIO/TMS; GND 3V3; Emulator; SWCLK SWDIO; Target Board; Slave; USB; Host

V1.9 | 25

Note: Using Code Flash full erase and power output controllable function requires connecting to the slave USB port via charging head or mobile power to power the slave and MCU.

### 8.3 Wireless Mode Access Address Match

When WCH-LinkW uses wireless mode for downloading and debugging, it is necessary to ensure that the wireless mode access addresses of the host and slave are the same. You can set the wireless mode access address through the WCH-LinkUtility tool. The steps are as follows:

① Connect WCH-LinkW wireless mode host and slave to computer respectively, click GET button, check whether the current host and slave access addresses are the same, if they are the same and not 0xE339E339, execute step 4, otherwise execute step 2
② Click CREATE button to create a random address
③ Click SET button to set the access address of host and slave respectively
④ The slave connects to the MCU to power on first, then the host connects to the computer, and the green light will light up to use the wireless mode normally

Notes:
(1) The factory default WCH-LinkW wireless mode access address is 0xE339E339.
(2) When wireless mode, only one pair of WCH-LinkW wireless access address should be guaranteed to be the same in the same usage environment. If there are more than one pair of devices, you need to use the above steps to set different wireless mode access addresses.

V1.9 | 26

## 9 Typical Problem Statement

Error Alert | Solution
Use Keil software to download | 1. Please refer to manual 3.2 Download configuration to complete Keil download configuration.
Use Keil software to download | 1. The RAM space size of our CH32F20x series chips is 0x2800.
Use MounRiver Studio software to download | 1. Check whether the chip's two-wire debug interface is correctly connected to Link.
2. Check whether the Debug function of the chip is
| turned on (if not, it can be turned on through the ISP tool).
3. Check whether the user program inside the chip is
| open to sleep function and whether there is an operation of FLASHrelated functions (if open, you can enter BOOT mode and download through two lines).
4. Check whether the two-wire debug interface of the
| user program inside the chip is multiplexed as a common GPIO port (if multiplexed, you can enter BOOT mode and download through two wires). Note:
(1) For CH32 series chips, if the download is not
| successful, you can enter BOOT mode (BOOT0 to VCC, BOOT1 to GND) and download through Link.
(2) For 3 and 4, the problem can be solved by WCH-
| LinkUtility tool to erase all the user area of the chip (refer to Chapter 5of the manual for WCH-LinkUtility

V1.9 | 27

download).
Use the WCH-LinkUtility tool to download | Erase all user areas of the chip

Update firmware using WCHLinkEJtagUpdTool tool After updating the firmware according to manual 7.3 Mode Switching Download Procedure, the blue LED on the WCH-LinkE-R0-1v3 does not light up and the Device Manager cannot recognize the device.

1. Analysis of the cause, may be the WCH-LinkE-R0-1v3 on the Y1 crystal soldering abnormalities, resulting in the crystal cannot properly start vibration. Therefore, you need to re-solder the Y1 crystal.

When using WCH-LinkW wireless mode for downloading and debugging, the green light does not turn on.

1. Please refer to section 8.2.2 of the manual for operation.

When using WCH-LinkW wireless mode for downloading and debugging, Code Flash full erase and power output controllable functions are not available.

1. To use the above function, you need to connect to the slave USB port through the charging head or mobile power to power the slave and MCU.
When using WCH-LinkW wireless mode for downloading and debugging, the slave cannot upgrade the firmware online.

1.WCH-LinkW slave online firmware upgrade needs to be done in wired mode.

Notes:
(1) The debugging function is not supported when the user program turns on the sleep function.
(2) If you exit abnormally when using the debug function, it is recommended to re-plug the Link.
(3) When using the download and debug functions of CH32F103/CH32F203/CH32V103/CH32V203/ CH32V307, BOOT0 is grounded.
(4) When using the debug function of CH569, the user code must be smaller than the configured ROM space, as shown in Table 2-2 of CH569SD1.
(5) When using the debug function of CH32 series chip, please make sure the chip is in the read protection off state.
(6) Typical WCH-Link FAQs can be found at: https://www.wch.cn/bbs/thread-100647-1.html

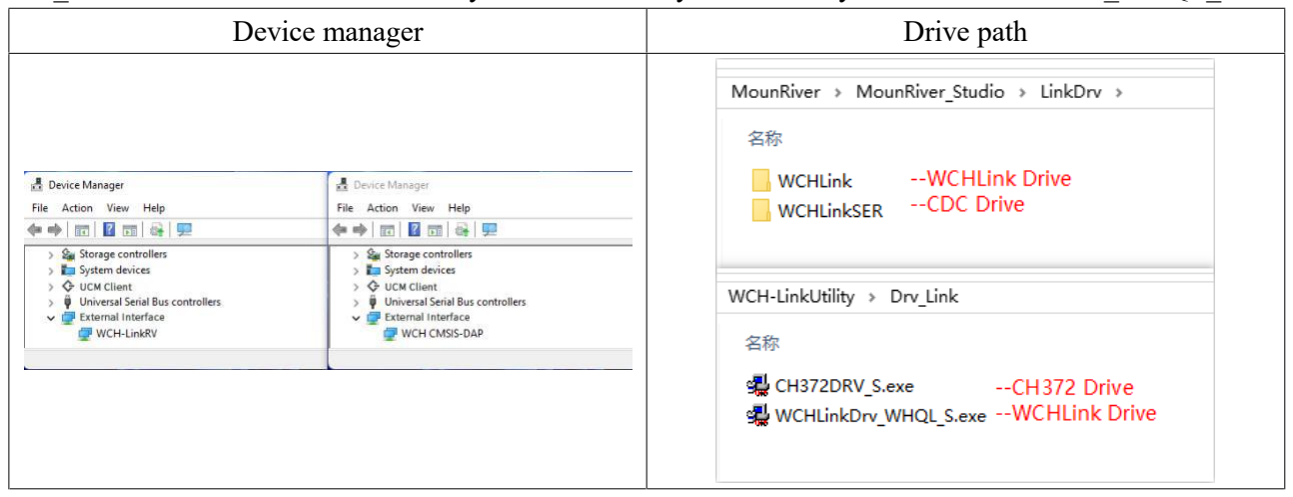
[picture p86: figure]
Device manager; Drive path
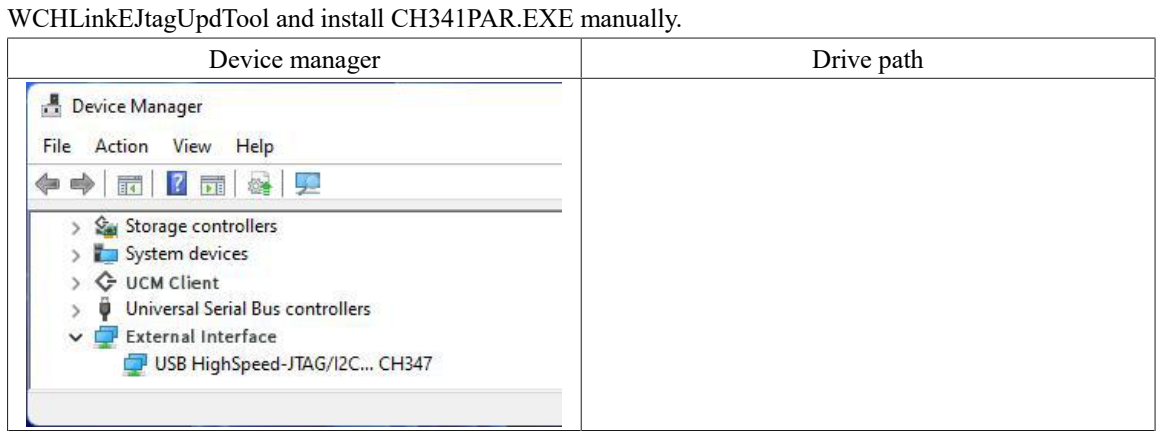
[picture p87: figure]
WCHLinkEJtagUpdTool and install CH341PAR.EXE manually.; Device manager; Drive path

V1.9 | 28

## 10 Driver Installation

### 10.1 WCH-Link Driver

(1) The WCH-Link driver will be installed automatically when MounRiver Studio is installed, and the device manager will be shown in the table below after successful installation. If the driver installation fails, please open the LinkDrv folder under the installation path of MounRiver Studio and manually install SETUP.EXE under the WCHLink folder.
(2) To install the WCH-LinkUtility tool, you need to manually install the WCH-Link driver. Please open the Drv_Link folder in the WCH-LinkUtility tool file directory and manually install WCHLinkDrv_WHQL_S.exe.

### 10.2 WCH-LinkE High-speed JTAG Driver

WCH-LinkE-R0-1v3 is upgraded to high-speed JTAG mode, you need to manually install the WCH-LinkE high-speed JTAG driver to use it properly. Please open the Drv folder under the installation path of

### 10.3 CDC Driver

CDC device installation problems under WIN7.
① If the serial port driver is successfully installed, the following steps are not required.
② Confirm that the usbser.sys file is present in path B. If it is missing, copy it from path A to path B.
③ Reinstall the CDC driver. (See the above table for the driver path, please install the CDC driver in the corresponding mode)

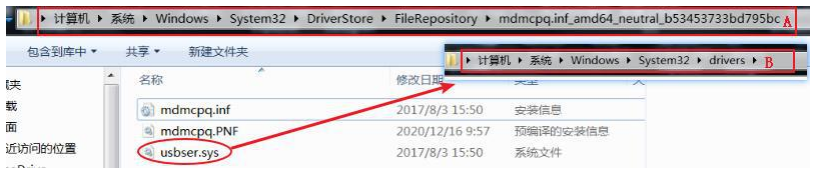
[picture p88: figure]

V1.9 | 29

Note: If the above steps do not solve the problem, please refer to the link below

Reference: http://www.wch.cn/downloads/InstallNoteOn64BitWIN7_ZH_PDF.html

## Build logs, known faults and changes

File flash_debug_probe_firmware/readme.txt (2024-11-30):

Download WCH-LinkUtility:
https://www.wch.cn/downloads/wch-linkutility_zip.html

FIRST FLASH
===========
- Click Target => 'Clear All Code Flash-By Power off'
- Click Loose Lock icon to disable chip read-protect
- Click folder icon => 'WCH-LinkE-APP-IAP.bin' file
- Check the options [v]Program [v]Verify [v]Reset and Run
- Click the execute button (green arrow on paper with two checkmarks)

NEXT FLASHES
============
- Target => 'Clear All Code Flash-By Power off'
- Loose Lock button
- Execute button

NOTES
=====
I followed the instructions in chapter "6.3 WCH-LinkUntility Offline Update (2-wire Approach to
Offline Update)" from the manual.
It looks like the first step - Long press the Tiny Scarab button IAP while powering up - is not
strictly needed.

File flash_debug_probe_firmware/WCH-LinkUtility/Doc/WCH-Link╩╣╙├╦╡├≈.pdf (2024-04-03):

WCH-Link 使用说明 | http://wch.cn

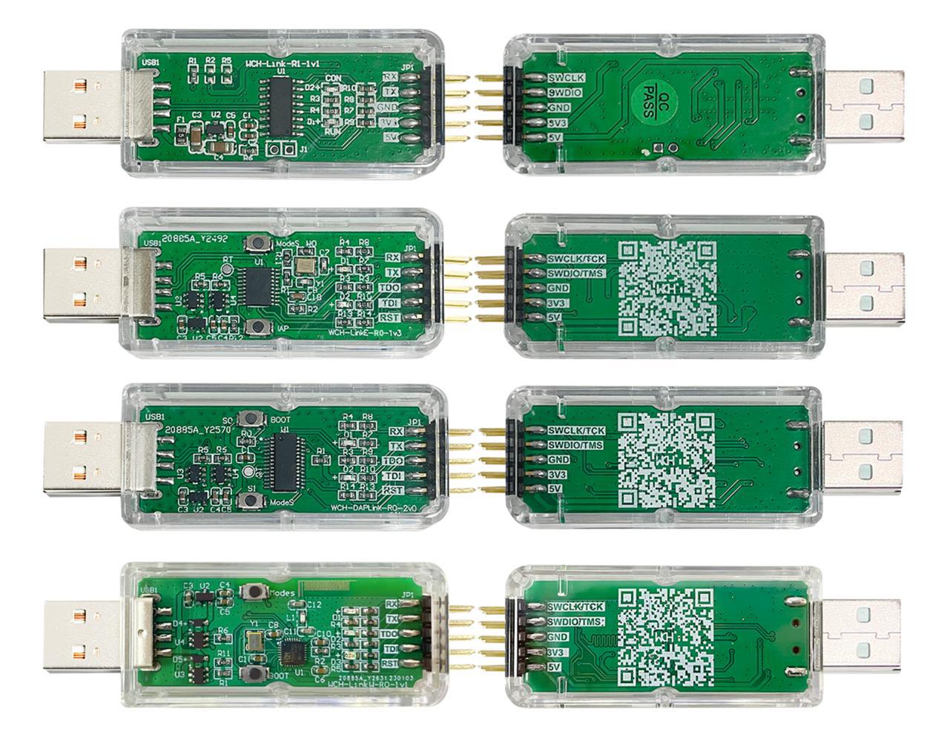
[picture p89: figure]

V1.9 | 1

## WCH-Link 使用说明

版本：V1.9
http://wch.cn

## 1 WCH-Link

### 1.1 模块简介

WCH-Link 模块可用于沁恒 RISC-V 架构 MCU 在线调试和下载，也可用于带有 SWD/JTAG 接口的 ARM 内核 MCU 的在线调试和下载。同时带有一路串口，方便调试输出。目前有四种 WCH-Link 包括 WCH-Link、WCH-LinkE、WCH-DAPLink 和 WCH-LinkW，如图一所示。

图一 WCH-Link 实物图

图二 WCH-Link 模式


V1.9 | 2

表一 WCH-Link 模式

ARM | 空闲时蓝灯常亮 | Keil/MounRiver Studio 支持 SWD/JTAG 接口的 ARM 核芯片

### 1.2 模式切换

方式一：使用 MounRiver Studio 软件切换 Link 模式（该方式适用于 WCH-Link、WCH-LinkE 和 WCH-LinkW）

① 点击快捷工具栏中的 箭头，弹出工程下载配置窗口

② 点击 Target Mode 右侧 Query,查看当前 Link 模式
③ 点击 Target Mode 选项框，选择目标 Link 模式，点击 Apply

方式二：使用 WCH-LinkUtility 工具切换 Link 模式
① 点击 Active WCH-Link Mode 右侧 Get，查看当前 Link 模式
② 点击 Active WCH-Link Mode 选项框，选择目标 Link 模式，点击 Set

方式三：使用 ModeS 键切换 Link 模式（该方式适用于 WCH-LinkE-R0-1v2、WCH-DAPLink-R0-2v0 和 WCH-LinkW-R0-1v1 及以上版本）
① 长按 ModeS 键后将 Link 上电

注：
（1）下载和调试时，蓝灯闪烁。
（2）后续使用时，Link 保持切换后的模式。
（3）扫描 Link 背面二维码，即可打开 WCH-Link 仿真调试器模块网址。
（4）WCH-Link 仿真调试器模块网址：https://www.wch.cn/products/WCH-Link.html （5）MounRiver Studio 获取网址：http://mounriver.com/
（6）WCH-LinkUtility 获取网址：https://www.wch.cn/downloads/WCH-LinkUtility_ZIP.html （7）WCHISPStudio 获取网址：https://www.wch.cn/downloads/WCHISPTool_Setup_exe.html （8）WCH-Link、WCH-LinkE 和 WCH-LinkW 支持 LinkRV 和 LinkDAP-WINUSB 模式切换；WCH-DAPLink 支 持 LinkDAP-WINUSB 和 LinKDAP-HID 模式切换。

### 1.3 串口波特率

表二 WCH-Link 串口支持波特率
1200 | 2400 | 4800 | 9600 | 14400

V1.9 | 3
19200 | 38400 | 57600 | 115200 | 230400

表三 WCH-LinkE/DAPLink/LinkW 串口支持波特率
1200 | 2400 | 4800 | 9600 | 14400 | 19200
38400 | 57600 | 115200 | 230400 | 460800 | 921600
注：
（1）图一中排针 RX 和 TX 为串口收发引脚，串口支持波特率见上表。
（2）Win7 下需安装 CDC 驱动。
（3）若重新拔插 Link，需重新开启串口调试助手。

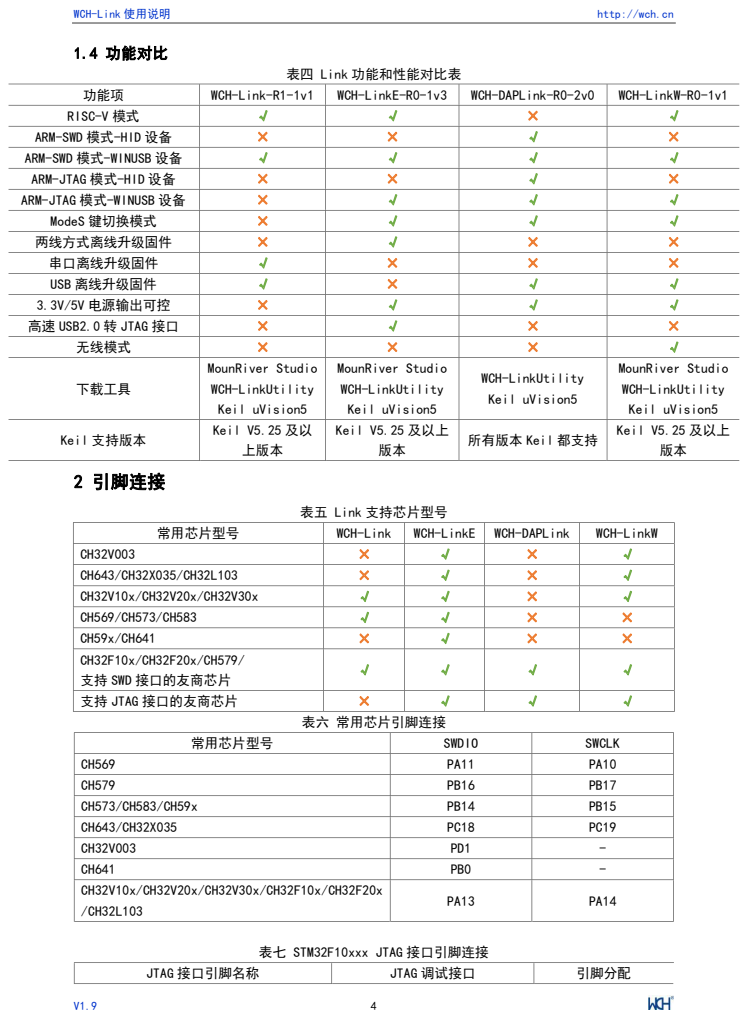
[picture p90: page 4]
1.4 功能对比; 功能项; WCH-Link-R1-1v1; WCH-LinkE-R0-1v3; WCH-DAPLink-R0-2v0; WCH-LinkW-R0-1v1; 无线模式; 下载工具; MounRiver Studio WCH-LinkUtility Keil uVision5; WCH-LinkUtility Keil uVision5; Keil 支持版本; Keil V5.25 及以; 上版本; Keil V5.25 及以上; 所有版本 Keil 都支持; 2 引脚连接; 常用芯片型号; WCH-Link; WCH-LinkE; WCH-DAPLink; WCH-LinkW; CH32F10x/CH32F20x/CH579/ 支持 SWD 接口的友商芯片; 支持 JTAG 接口的友商芯片; 表六 常用芯片引脚连接; SWDIO; SWCLK; JTAG 接口引脚名称; JTAG 调试接口; 引脚分配

表四 Link 功能和性能对比表

RISC-V 模式
ARM-SWD 模式-HID 设备
ARM-SWD 模式-WINUSB 设备
ARM-JTAG 模式-HID 设备
ARM-JTAG 模式-WINUSB 设备
ModeS 键切换模式
两线方式离线升级固件
串口离线升级固件
USB 离线升级固件
3.3V/5V 电源输出可控
高速 USB2.0 转 JTAG 接口

表五 Link 支持芯片型号

表七 STM32F10xxx JTAG 接口引脚连接

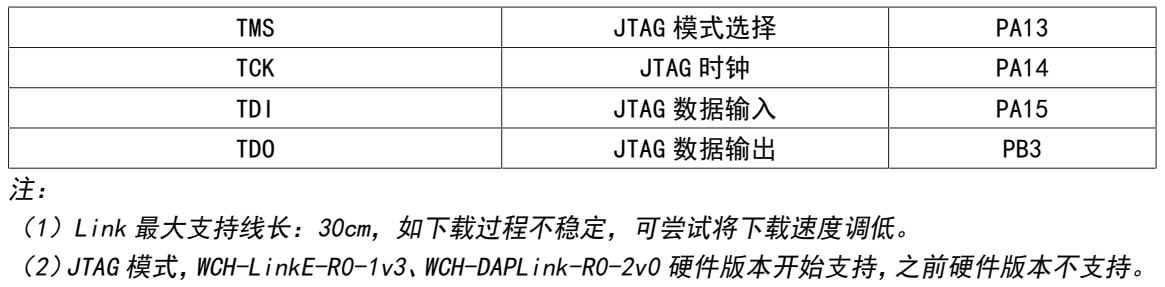
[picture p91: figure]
TMS; JTAG 模式选择; TCK; JTAG 时钟; TDI; JTAG 数据输入; TDO; JTAG 数据输出; 注： （1）Link 最大支持线长：30cm，如下载过程不稳定，可尝试将下载速度调低。 （2）JTAG 模式，WCH-LinkE-R0-1v3、WCH-DAPLink-R0-2v0 硬件版本开始支持，之前硬件版本不支持。
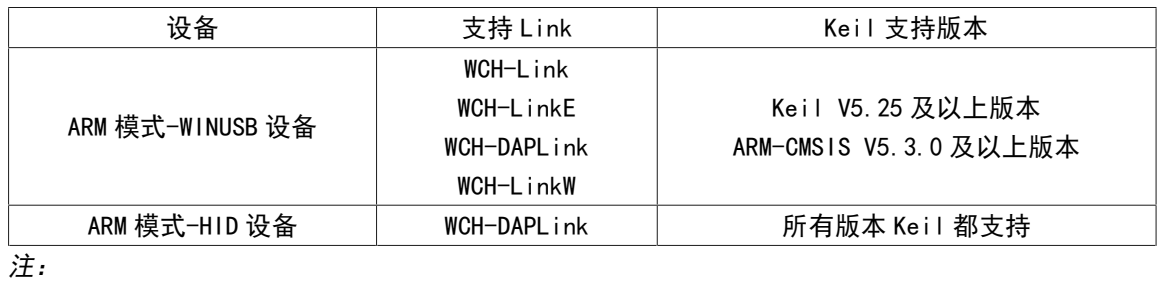
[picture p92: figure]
支持 Link; Keil 支持版本; ARM 模式-WINUSB 设备; WCH-Link WCH-LinkE WCH-DAPLink WCH-LinkW; Keil V5.25 及以上版本 ARM-CMSIS V5.3.0 及以上版本; ARM 模式-HID 设备; WCH-DAPLink; 所有版本 Keil 都支持

V1.9 | 5

（3）WCH-LinkE 高速版本仅针对 CH32F20x/CH32V20x/CH32V30x 进行提速。 （4）CH569、CH579、CH573、CH583、CH59x，若要使用 Link 进行下载或调试，需使用官方 ISP 工具 开启两线调试接口，使用时需注意 Link 模式。步骤如下：
- 打开 WCHISPStudio 工具，待测芯片进入 BOOT 模式
·CH569 需短接 HD0 和 GND，通过 U 口上电；
·CH573/CH583/CH59x 需长按 Download 键，通过 U 口上电；
- WCHISPStudio 工具会自动弹出适配窗口，点击开启两线调试接口

## 3 Keil 下载与调试

### 3.1 设备切换

WCH-DAPLink 支持 ARM 模式-WINUSB 设备和 ARM 模式-HID 设备两种模式，可通过 WCH-LinkUtility 工具（或长按 ModeS 键后将 Link 上电）切换两种设备模式。WCH-Link、WCH-LinkE 和 WCH-LinkW 仅支 持 ARM 模式-WINUSB 设备模式。

表八 WCH-DAPLink 设备

（1）WCH-Link、WCH-LinkE、WCH-DAPLink 和 WCH-LinkW 出厂默认为 WINUSB 设备模式。 （2）WCH-DAPLink-R0-1v0 通过长按 IAP 键上电切换两种设备模式。 （3）WCH-LinkUtility 工具开启会占用 Link 设备，导致 Keil 软件无法识别到 Link。

### 3.2 下载配置

① 点击工具栏中的 魔法棒，弹出 Options for Target 对话框，点击 Debug，选择仿真器型号

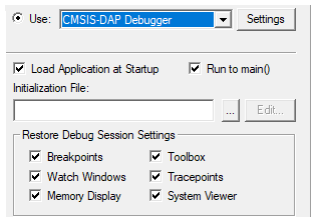
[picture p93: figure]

V1.9 | 6

② 点击 Use 选项框，选择 CMSIS-DAP Debugger
③ 点击 Settings 按钮，弹出 Cortex-M Target Driver Setup 对话框

Serial No：显示正在使用的调试适配器的标识符，当连接多个适配器时，可通过下拉列表来指 定适配器。
SW Device：显示连接设备的设备 ID 和名称。
Port：设置内部调试接口 SW 或 JTAG。（WCH-LinkE-R0-1v3、WCH-DAPLink-R0-2v0 和 WCH-LinkW-R0-1v1 两种接口都支持）
Max Clock：设置与目标设备通信的时钟速率。
④ 点击 Flash Download，进行下载配置

Download Function：配置选项
- Erase Full Chip：全片擦除
- Erase Sectors：部分擦除
- Do not Erase：不擦除
- Program：编程
- Verify：校验
- Reset and Run：复位后运行
RAM for Algorithm：配置 RAM 空间的起始地址和大小
我司 CH32F103 系列芯片 RAM 空间大小为 0x1000，CH32F20x 系列芯片 RAM 空间大小为 0x2800。 Programming Algorithm：添加算法文件
算法文件在安装芯片器件包之后已经自动添加，点击 OK 即可。


V1.9 | 7
⑤ 完成上述配置后，点击 OK，关闭对话框。点击工具栏中的 | 图标，即可进行代码烧录

### 3.3 调试

① 点击工具栏中的 调试按钮，进入调试页面

② 设置断点

③ 基本调试指令

复位：对程序进行复位操作。

全速运行：使当前程序开始全速运行，直到程序遇到断点时停止。

单步跳入调试：执行单条语句，如果遇到函数，则会进入函数内部。

单步跳过调试：执行单条语句，遇到函数不会进入函数内部，而是全速运行函数，并跳到下

一条语句。

单步返回调试：全速运行当前函数后面所有内容，直到函数返回上一级。

④ 再次点击工具栏中的 调试按钮，退出调试

## 4 MounRiver Studio 下载与调试

### 4.1 下载配置

① 点击工具栏中的 箭头，弹出工程下载配置窗口

② 点击 Disable Read-Protect 按钮，解除芯片读保护

③ 目标配置，主要内容如下：

V1.9 | 8

MCU Type：芯片型号
Program Address：编程地址
CLK Speed：两线调试速度
Target File：目标文件
④ 配置选项

Erase All：全片擦除
Program：编程
Verify：校验
Reset and run：复位后运行

⑤ 点击 Apply and Close，保存下载配置。点击工具栏中的 图标，即可进行代码烧录，结果显示

在 Console 中

### 4.2 调试

① 进入调试页面

方式一：点击工具栏中的 | 调试按钮，直接进入调试页面。
方式二：点击工具栏中的 | 箭头，选择 Debug Configurations，弹出调试配置页面。双击 GDB

OpenOCD MRS Debugging，生成 obj 文件，选择 obj 文件，点击右下角 Debug 按钮，进入调试页面。

② 设置断点


V1.9 | 9

③ 基本调试指令

复位：对程序进行复位操作。

全速运行：使当前程序开始全速运行，直到程序遇到断点时停止。

终止调试：退出调试。

单步跳入调试：执行单条语句，如果遇到函数，则会进入函数内部。

单步跳过调试：执行单条语句，遇到函数不会进入函数内部，而是全速运行函数，并跳到下

一条语句。

单步返回调试：全速运行当前函数后面所有内容，直到函数返回上一级。

④ 点击 按钮，退出调试

### 4.3 其他功能

### 4.3.1 设置芯片读保护

| 查询芯片读保护状态
| 使能芯片读保护状态
| 解除芯片读保护状态

### 4.3.2 Code Flash 全擦

MounRiver Studio 可以通过控制硬件复位引脚或重新上电对芯片的用户区进行全部擦除。通过 重新上电控制擦除，需使用 Link 为芯片供电；通过硬件复位引脚控制擦除，需连接芯片与 Link 的复 位引脚。（仅 WCH-LinkE、WCH-DAPLink 和 WCH-LinkW 支持）

V1.9 | 10

### 4.3.3 关闭两线调试接口

针对除 CH32 系列外的芯片，可通过关闭两线调试接口，开启代码和数据保护。

禁止两线调试接口

### 4.3.4 芯片内存分配

针对大容量通用型（连接型/互联型/无线型）芯片，可通过 MounRiver Studio 进行内存分配， 详情请参考 CH32FV2x_V3xRM 手册的用户选择字章节。

## 5 WCH-LinkUtility 下载

### 5.1 下载配置

① 点击 图标，连接 Link
② 选择芯片型号

③ 配置选项

Erase All：全片擦除
Program：编程
Verify：校验
Reset and run：复位后运行
④ 解除芯片读保护，设置两线调试速度
⑤ 点击 | 图标，添加固件
⑥ 点击 | 图标，执行下载

### 5.2 其他功能

### 5.2.1 查询芯片信息

点击 图标，查询芯片信息


V1.9 | 11

MCU UID：芯片 ID
Flash Size：芯片 Flash 大小
Read-Protect：芯片读保护状态
Link Version：Link 固件版本

### 5.2.2 设置芯片读保护

查询芯片读保护状态

使能芯片读保护状态

解除芯片读保护状态

### 5.2.3 读取芯片 Flash

点击 图标，读取芯片 Flash

### 5.2.4 Code Flash 全擦

WCH-LinkUtility 工具可以通过控制硬件复位引脚或重新上电对芯片的用户区进行全部擦除。通 过重新上电控制擦除，需使用 Link 为芯片供电；通过硬件复位引脚控制擦除，需连接芯片与 Link 的 复位引脚。（仅 WCH-LinkE、WCH-DAPLink 和 WCH-LinkW 支持）

### 5.2.5 电源输出可控

WCH-LinkUtility 工具可控制 Link 电源输出。点击 Target，在下拉列表中可选择开启/关闭电源 3.3V/5V 输出。（仅 WCH-LinkE、WCH-DAPLink 和 WCH-LinkW 支持）

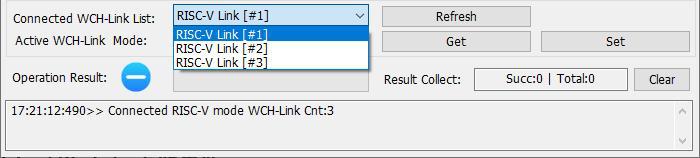
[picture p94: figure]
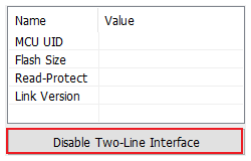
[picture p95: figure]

V1.9 | 12

### 5.2.6 自动连续下载

勾选 Auto download when WCH-Link was linked，可实现工程自动连续下载。

### 5.2.7 多设备下载

WCH-LinkUtility 工具可以识别多个 Link 设备。当连接多个 Link 时，可通过 Connected WCH-Link List 选项框选择指定 Link 设备进行下载。

### 5.2.8 关闭两线调试接口

针对除 CH32 系列外的芯片，可通过关闭两线调试接口，开启代码和数据保护。

### 5.2.9 用户选择字配置

针对 CH32 系列芯片，可通过 WCH-LinkUtility 工具进行用户选择字配置，详情请参考芯片 RM 手 册的用户选择字章节。

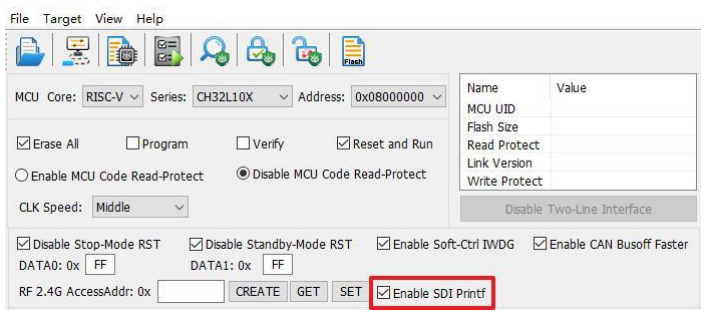
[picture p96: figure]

V1.9 | 13

### 5.2.10 BOOT 下载

针对 CH32V003、CH641 芯片，可通过 WCH-LinkUtility 工具选择程序下载到程序闪存存储区或系 统存储区。

### 5.2.11 SDI 虚拟串口功能

该功能使用 SDI 接口，实现芯片打印输出功能，该功能需修改打印函数，具体参考相关 EVT 中 SDI_Printf 例程。该功能仅 V1.80 及以上版本支持，使用时需勾选 Enable SDI Printf,且打开 WCH-LinkE 的 COM 口。

注：
（1） 该功能仅 V1.80 及以上版本支持。
（2） 该功能仅 WCH-LinkE 支持。
（3） 该功能支持芯片包括 CH32V003、CH32V103、CH32V20x、CH32V30x、CH32X035、CH32L103、CH641。

## 6 固件更新方式

### 6.1 MounRiver Studio 在线更新

若固件需升级，点击下载按钮时 MounRiver Studio 会有弹窗提醒，点击 Yes 启动更新。

### 6.2 WCH-LinkUtility 在线更新

若固件需升级，点击下载按钮时 WCH-LinkUtility 会有弹窗提醒，点击 Yes 启动更新。

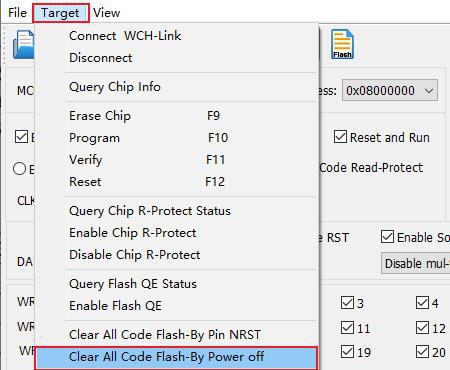
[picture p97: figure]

V1.9 | 14

注：
（1）WCH-LinkE 支持手动在线更新，步骤如下：
- 长按 IAP 键后将 Link 上电，直至蓝灯闪烁；
- 点击下载按钮时 MounRiver Studio/WCH-LinkUtility 会有弹窗提醒，点击 Yes 启动更新。 （2）若 Link 固件更新异常，请通过离线更新方式更新固件。

### 6.3 WCH-LinkUtility 离线更新（两线方式离线更新）

① 连接 WCH-LinkE 与待更新 WCH-LinkE
WCH-LinkE 待更新 WCH-LinkE
3V3 | 3V3
GND | GND
SWDIO | SWDIO
SWCLK | SWCLK
② WCH-LinkE 上电，选择待更新 Link 芯片型号（WCH-LinkE 主控芯片为 CH32V30x）
③ 待更新 Link 进入 IAP 模式（长按 IAP 键后将 Link 上电，即通过 USB 口连接电脑上电） ④ 点击 Target->Clear All Code Flash-By Power off，对芯片的用户区进行全部擦除
⑤ 点击 | 图标，解除芯片读保护
⑥ 点击 | 图标，添加 Link 离线升级固件
⑦ 配置选项（编程+校验+复位）

⑧ 点击 图标，执行下载

注：

V1.9 | 15

（1）两线方式离线更新仅 WCH-LinkE 支持。 （2）该方式需要有两个 WCH-LinkE。
（3）Link 进入 IAP 模式时，蓝灯闪烁。

### 6.4 WCHISPStudio 串口离线更新

① 连接 WCH-Link 与 USB 转 TTL 模块
WCH-Link | USB 转 TTL 模块
TX | RX
RX | TX
GND | GND
② USB 转 TTL 模块上电，WCH-Link 进入 BOOT 模式（短接图一中 J1 将 Link 上电）
③ 选择芯片型号：CH549，下载接口：串口，设备列表：选择 USB 转 TTL 模块对应的串口号

④ 添加 Link 离线升级固件至目标程序文件
⑤ 下载配置

⑥ 点击下载按钮
⑦ 点击下载后出现等待设备接入字段，此时将 WCH-Link 插上 USB 接口，ISP 工具自动开始下载 注：串口离线更新仅 WCH-Link 支持。

### 6.5 WCHISPStudio USB 离线更新

① 待更新 Link 进入 BOOT 模式（短接图一中 J1 或长按 BOOT 键后将 Link 上电） ② WCHISPStudio 工具会自动弹出适配窗口
③ 添加 Link 离线升级固件至目标程序文件
④ 下载配置

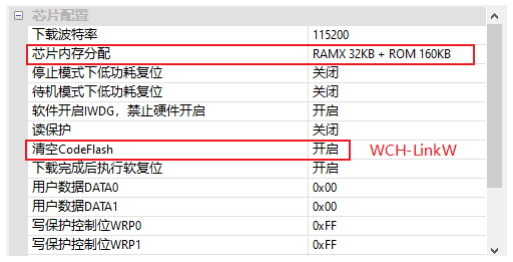
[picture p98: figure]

V1.9 | 16

⑤ 点击下载按钮

注：
（1）USB 离线更新仅 WCH-Link、WCH-DAPLink 和 WCH-LinkW 支持。 （2）WCH-LinkE-R0-1v3 和 WCH-DAPLink-R0-2v0 仅适用固件版本 v2.8 及以上版本。 （3）WCH-LinkUtility 工具可通过 MounRiver Studio 软件导出。

（4）Link 离线升级固件位于 MounRiver Studio 安装路径和 WCH-LinkUtility 安装路径。

① WCH-DAPLink 升级固件
② WCH-LinkW 升级固件
③ WCH-LinkE 升级固件
④ WCH-Link RISC-V 模式升级固件
⑤ WCH-Link ARM 模式升级固件
⑥ WCH-DAPLink 离线升级固件
⑦ WCH-Link ARM 模式离线升级固件
⑧ WCH-Link RISC-V 模式离线升级固件 ⑨ WCH-LinkE 离线升级固件
⑩ WCH-LinkW 离线升级固件

## 7 WCH-LinkE 高速 JTAG

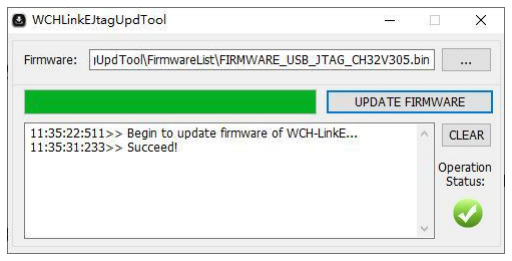
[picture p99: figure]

V1.9 | 17

### 7.1 模块简介

WCH-LinkE-R0-1v3 提供了一个 JTAG 接口，支持四线连接（TMS 线，TCK 线，TDI 线和 TDO 线）， 用于为计算机扩展 JTAG 接口，操作 CPU、DSP、FPGA 和 CPLD 等器件。

图三 WCH-LinkE 高速 JTAG 模式

### 7.2 模块特点

- 作为 Host/Master 主机模式。
- JTAG 接口提供 TMS 线、TCK 线、TDI 和 TDO 线。
- 支持高速 USB 数据传输。
- 通过计算机 API 配合，可灵活操作 CPU、DSP、FPGA 和 CPLD 等器件。

### 7.3 模式切换

可通过 WCHLinkEJtagUpdTool 工具将 WCH-LinkE-R0-1v3 升级为高速 JTAG 模式，下载步骤如下： ① WCH-LinkE-R0-1v3 进入 IAP 模式（长按 IAP 键后将 Link 上电，即通过 USB 口连接电脑上电）， 此时蓝灯闪烁
② 打开 WCHLinkEJtagUpdTool 工具，执行下载（WCH-LinkE 高速 JTAG 升级固件已自动添加） ③ 固件更新完成后，此时蓝灯常亮

注：

### （1）WCHLinkEJtagUpdTool 获取网址：https://www.wch.cn/downloads/WCHLinkEJtagUpdTool_ZIP.html

（2）可通过 WCH-LinkUtility 工具离线更新固件，详情请参考手册 6.3 WCH-LinkUtility 离线更新。 （3）WCH-LinkE 高速 JTAG 离线升级固件位于 WCHLinkEJtagUpdTool 安装路径。

① WCH-LinkE 高速 JTAG 升级固件
② WCH-LinkE 高速 JTAG 离线升级固件

### 7.4 下载流程

① 在 WCH-LinkE 高速 JTAG 模式下，通过 JTAG 先将 Bit 程序文件下载到 FPGA 中，Bit 文件将操 作 FPGA 的 SPI 控制器，将 JTAG 数据转换为 SPI 数据写入 Flash，此步骤即将 BIN 文件写入，从而实

V1.9 | 18

现其程序固化过程
② 此处选用 FPGA 为 Xilinx 的 xc7a35t。编写 CFG 文件，使用“openocd -f”指定来调用。将 CFG 文件命名为 usb20jtag.cfg，保存至 openocd.exe 文件所在位置

# 指定 WCH-LinkE 高速 JTAG 调试器

adapter driver ch347
ch347 vid_pid 0x1a86 0x55dd

# 设置 TCK 时钟频率

adapter speed 10000

# 指定操作的 TARGET，加载 OpenOCD 中 JTAG-SPI 驱动 source [find cpld/xilinx-xc7.cfg]

source [find cpld/jtagspi.cfg]

# 设置 TARGET 的 IR 命令

set XC7_JSHUTDOWN 0x0d
set XC7_JPROGRAM 0x0b
set XC7_JSTART 0x0c
set XC7_BYPASS 0x3f

# 下载流程

init
# 先下载 Bit 文件至 TARGET

pld load 0 bscan_spi_xc7a35t.bit reset halt
# 检测 Flash 信息

flash probe 0
# 下载 Bin 文件至 Flash 中

flash write_image erase test.bin 0x0 bin

# 生效固件操作

irscan xc7.tap $XC7_JSHUTDOWN
irscan xc7.tap $XC7_JPROGRAM runtest 60000
runtest 2000
irscan xc7.tap $XC7_BYPASS runtest 2000

exit

③ 在 Windows 终端运行命令：openocd.exe -f usb20jtag.cfg，执行如下

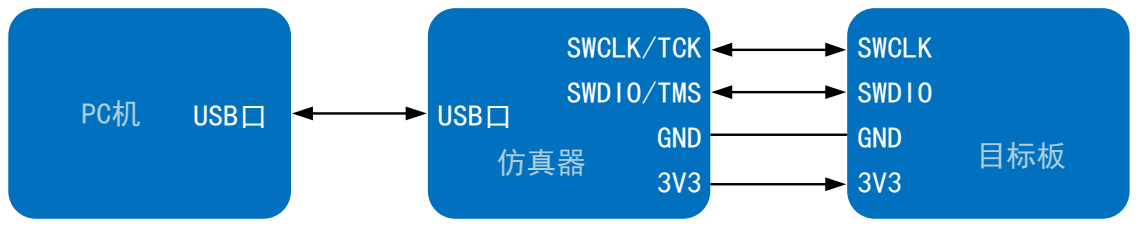
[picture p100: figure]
SWCLK/TCK; SWDIO/TMS; GND 3V3 仿真器; SWCLK; SWDIO; GND; 目标板; PC机; USB口

V1.9 | 19

④ 下载结束，设备正常运行

注：

### （1）转换作用的 Bit 文件，可借助 Github 开源项目：https://github.com/quartiq/bscan_spi_bitstreams

（2）openocd.exe 文件所在位置：MounRiver\MounRiver_Studio\toolchain\OpenOCD\bin

## 8.WCH-LinkW 使用介绍

### 8.1 模块简介

WCH-LinkW 是一款有线/无线 2.4G 双模仿真调试器，可用于沁恒 RISC-V 架构 MCU 在线调试和下 载，也可用于带有 SWD/JTAG 接口的 ARM 芯片在线调试和下载。

### 8.2 使用方法

### 8.2.1 有线模式

有线模式仅需要 1 个 WCH-LinkW，将排针连接 MCU，USB 口连接电脑，即可进行下载调试。

### 8.2.2 无线模式

无线模式需要 2 个 WCH-LinkW，分为 WCH-LinkW 主机（连接电脑）和 WCH-LinkW 从机（连接 MCU）。 WCH-LinkW 连接电脑枚举成功后，在 2 秒内检测是否有从机匹配，来进行模式切换，若匹配到从机， 则切换至无线模式，此时绿灯点亮；反之，则切换至有线模式，绿灯熄灭。 无线模式下载调试需要用到 2 个 WCH-LinkW，使用步骤如下：
① 从机与 MCU 通过两线方式连接，通过 MCU 的 U 口供电，也可通过充电头或移动电源与从机 USB

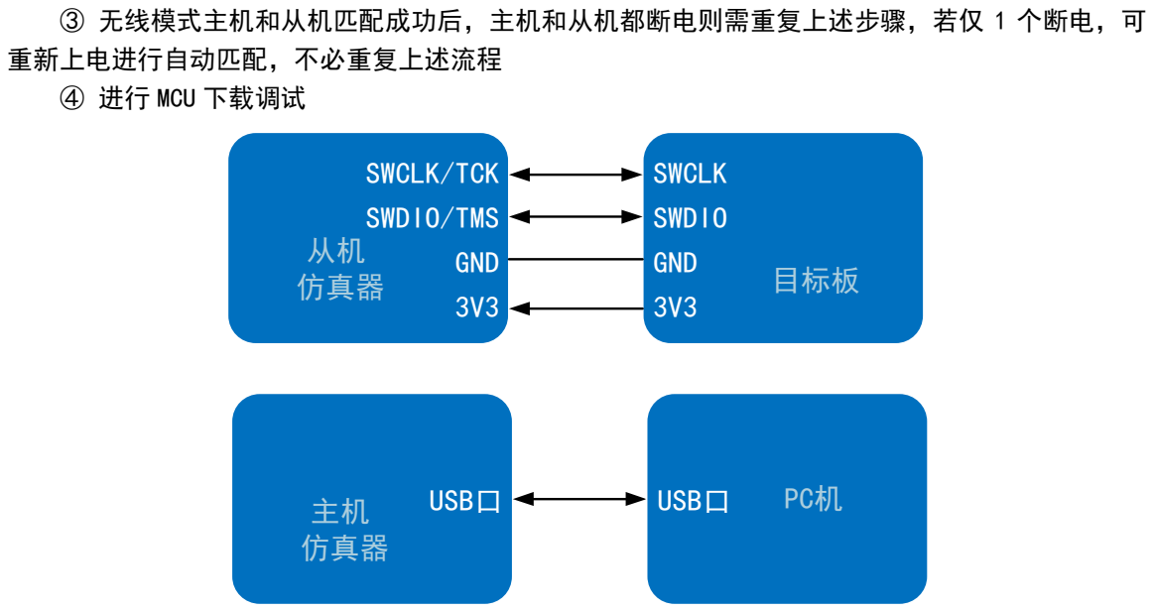
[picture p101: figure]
③ 无线模式主机和从机匹配成功后，主机和从机都断电则需重复上述步骤，若仅 1 个断电，可 重新上电进行自动匹配，不必重复上述流程 ④ 进行 MCU 下载调试; SWCLK/TCK; SWDIO/TMS; GND 3V3 仿真器; SWCLK; SWDIO; GND; 目标板; USB口; 仿真器; PC机

V1.9 | 20

口连接，对从机和 MCU 进行供电
② 待从机上电成功后，主机 USB 口连接电脑。主机设备枚举成功后，2 秒内匹配到从机，则主机 和从机绿灯点亮

注：使用 Code Flash 全擦和电源输出可控功能需通过充电头或移动电源与从机 USB 口连接，对从机 和 MCU 进行供电。

### 8.3 无线模式访问地址匹配

WCH-LinkW 使用无线模式进行下载调试时，需保证主机和从机的无线模式访问地址一致。可通过 WCH-LinkUtility 工具设置无线模式访问地址。步骤如下：

① 分别将 WCH-LinkW 无线模式主机和从机连接电脑，点击 GET 按钮，查询当前主机和从机的访 问地址是否一致，若一致且不为 0xE339E339，执行步骤 4，否则执行步骤 2
② 点击 CREATE 按钮，创建随机地址
③ 点击 SET 按钮，分别设置主机和从机的访问地址
④ 从机连接 MCU 先上电，之后主机连接电脑，绿灯点亮即可正常使用无线模式

注：
（1）WCH-LinkW 无线模式访问地址出厂默认为 0xE339E339。 （2）无线模式时，同一使用环境下，需保证仅有一对 WCH-LinkW 无线访问地址一致。若有多对设备， 需使用上述步骤设置不同的无线模式访问地址。

## 9 典型问题说明

错误提醒 | 解决方法
使用 Keil 软件下载 | 1.请参考手册 3.2 下载配置完成 Keil 下载配置。

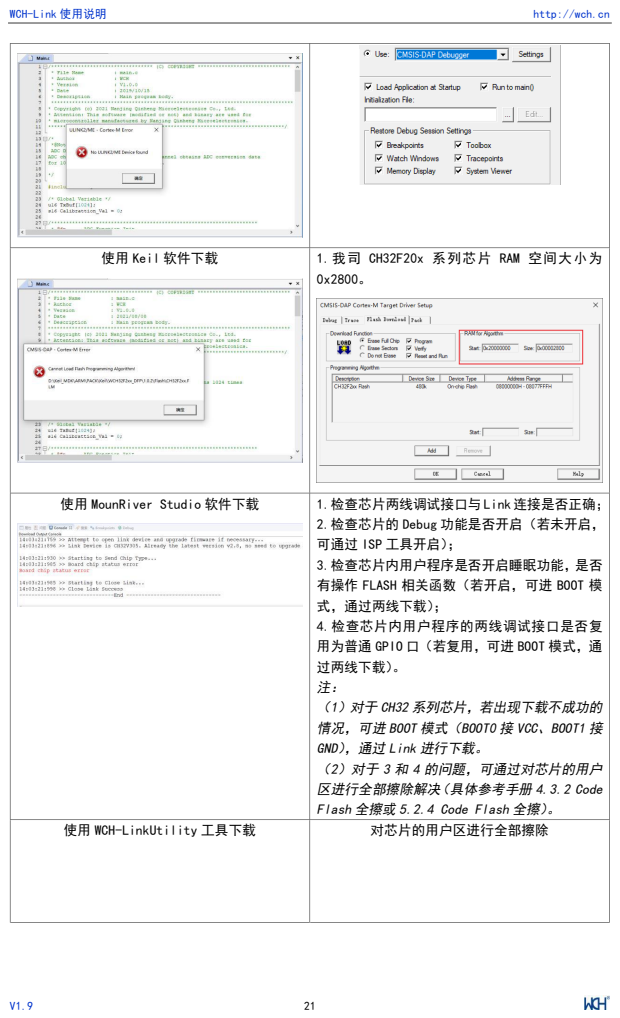
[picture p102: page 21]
使用 Keil 软件下载; 1.我司 CH32F20x 系列芯片 RAM 空间大小为; 使用 MounRiver Studio 软件下载; 1.检查芯片两线调试接口与 Link 连接是否正确；; 使用 WCH-LinkUtility 工具下载; 对芯片的用户区进行全部擦除

2.检查芯片的 Debug 功能是否开启（若未开启，
可通过 ISP 工具开启）；
3.检查芯片内用户程序是否开启睡眠功能，是否
有操作 FLASH 相关函数（若开启，可进 BOOT 模
式，通过两线下载）；
4.检查芯片内用户程序的两线调试接口是否复
用为普通 GPIO 口（若复用，可进 BOOT 模式，通
过两线下载）。
（1）对于 CH32 系列芯片，若出现下载不成功的
情况，可进 BOOT 模式（BOOT0 接 VCC、BOOT1 接
GND），通过 Link 进行下载。
（2）对于 3 和 4 的问题，可通过对芯片的用户
区进行全部擦除解决（具体参考手册 4.3.2 Code
Flash 全擦或 5.2.4 Code Flash 全擦）。

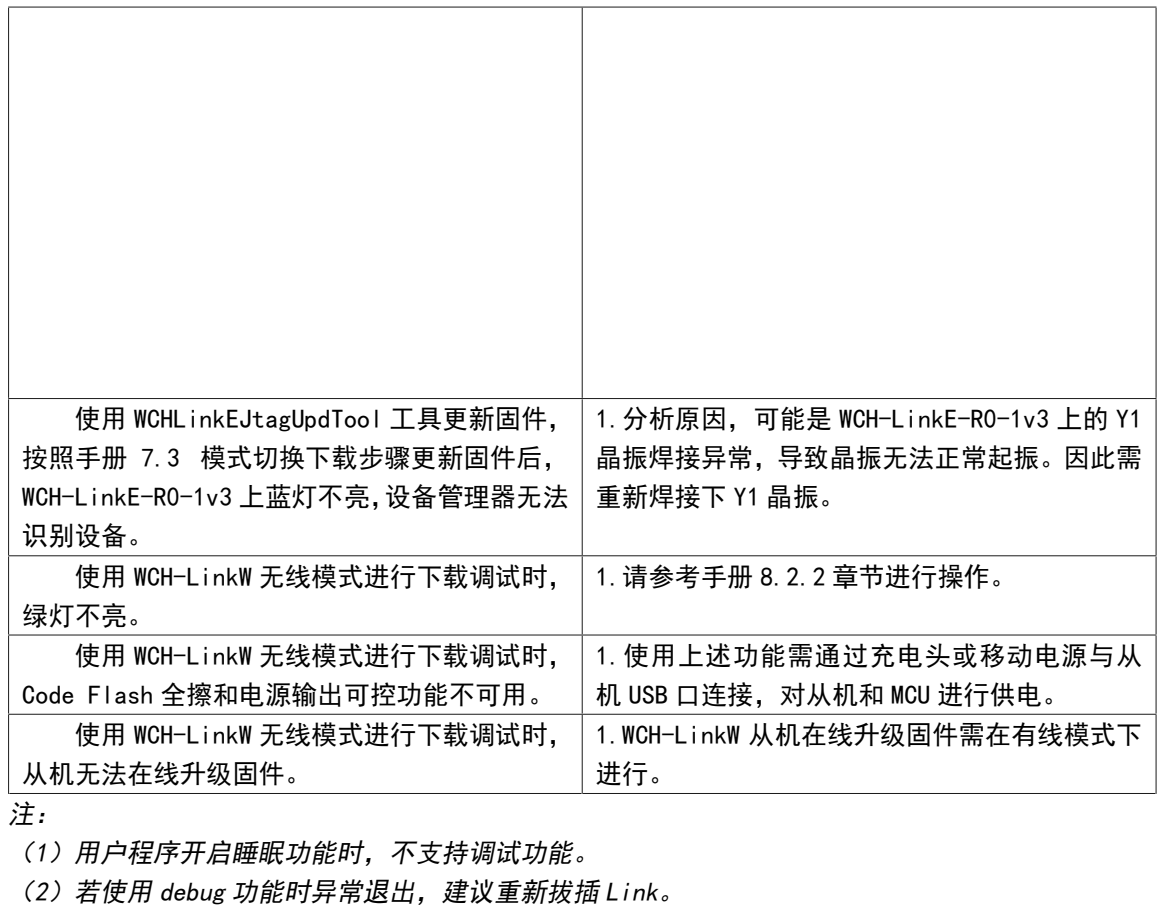
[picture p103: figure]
使用 WCHLinkEJtagUpdTool 工具更新固件， 按照手册 7.3 模式切换下载步骤更新固件后， WCH-LinkE-R0-1v3 上蓝灯不亮，设备管理器无法 识别设备。; 1.分析原因，可能是 WCH-LinkE-R0-1v3 上的 Y1 晶振焊接异常，导致晶振无法正常起振。因此需 重新焊接下 Y1 晶振。; 使用 WCH-LinkW 无线模式进行下载调试时， 绿灯不亮。; 1.请参考手册 8.2.2 章节进行操作。; 使用 WCH-LinkW 无线模式进行下载调试时， Code Flash 全擦和电源输出可控功能不可用。; 1.使用上述功能需通过充电头或移动电源与从 机 USB 口连接，对从机和 MCU 进行供电。; 使用 WCH-LinkW 无线模式进行下载调试时， 从机无法在线升级固件。; 1.WCH-LinkW 从机在线升级固件需在有线模式下 进行。; 注： （1）用户程序开启睡眠功能时，不支持调试功能。 （2）若使用 debug 功能时异常退出，建议重新拔插 Link。

V1.9 | 22

（3）使用 CH32F103/CH32F203/CH32V103/CH32V203/CH32V307 的下载和调试功能时，BOOT0 需接地。 （4）使用 CH569 的调试功能时，用户代码必须小于配置的 ROM 空间，具体见 CH569DS1 手册表 2-2。 （5）使用 CH32 系列芯片的调试功能时，请确保芯片处于读保护关闭状态。 （6）WCH-Link 典型常见问题可参考：https://www.wch.cn/bbs/thread-100647-1.html

## 10 驱动安装

### 10.1 WCH-Link 驱动

（1）安装 MounRiver Studio 时会自动安装 WCH-Link 驱动，安装成功后设备管理器如下表所示， 如果驱动安装失败，请打开 MounRiver Studio 安装路径下的 LinkDrv 文件夹，手动安装 WCHLink 文 件夹下的 SETUP.EXE。
（2）安装 WCH-LinkUtility 工具需手动安装 WCH-Link 驱动，请打开 WCH-LinkUtility 工具文件 目录的 Drv_Link 文件夹，手动安装 WCHLinkDrv_WHQL_S.exe。
设备管理器 | 驱动路径

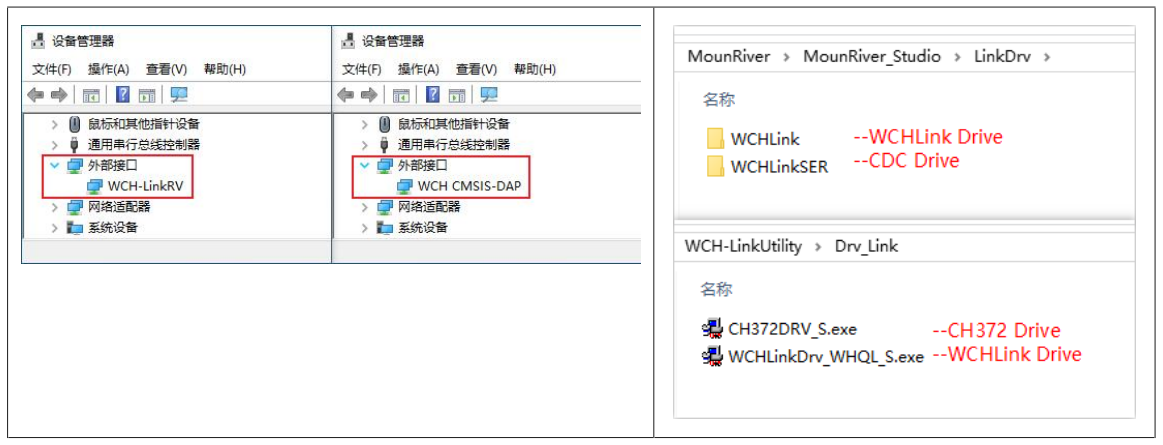
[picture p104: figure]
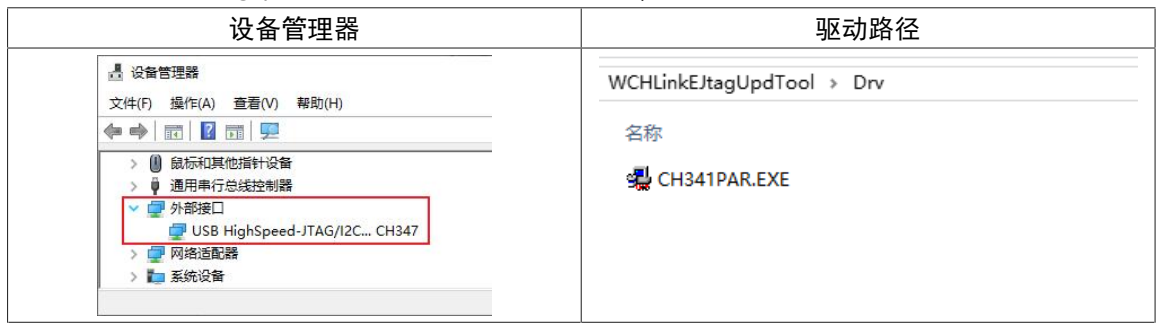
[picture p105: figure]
设备管理器; 驱动路径

V1.9 | 23

### 10.2 WCH-LinkE 高速 JTAG 驱动

WCH-LinkE-R0-1v3 升级为高速 JTAG 模式，需手动安装 WCH-LinkE 高速 JTAG 驱动才能正常使用。 请打开 WCHLinkEJtagUpdTool 安装路径下的 Drv 文件夹，手动安装 CH341PAR.EXE。

### 10.3 CDC 驱动

WIN7 下 CDC 设备安装问题：
① 若串口驱动安装成功，则无需以下步骤
② 确认路径 B 中是否有 usbser.sys 文件，如果缺失，从路径 A 中将其复制到路径 B ③ 重新安装 CDC 驱动(驱动路径见上表，请安装对应模式下的 CDC 驱动)

注：若上述步骤不能解决问题，请参考下方链接

V1.9 | 24

参考资料： http://www.wch.cn/downloads/InstallNoteOn64BitWIN7_ZH_PDF.html

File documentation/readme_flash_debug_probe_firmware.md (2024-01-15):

<a href="../README.md"> HOME</a>

# Flash/Debug Probe Firmware

- [`FIRMWARE_CH32V305.bin`](https://raw.githubusercontent.com/Embeetle/tiny-scarab/main/flash_debug_probe_firmware/FIRMWARE_CH32V305.bin)
- [`WCH-LinkE-APP-IAP.bin`](https://raw.githubusercontent.com/Embeetle/tiny-scarab/main/flash_debug_probe_firmware/WCH-LinkE-APP-IAP.bin)

[PAGE UNDER CONSTRUCTION]

&nbsp;<br>
<a href="../README.md#index"> GO BACK</a>

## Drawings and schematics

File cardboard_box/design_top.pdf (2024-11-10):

FLASH | PWR
| ERR

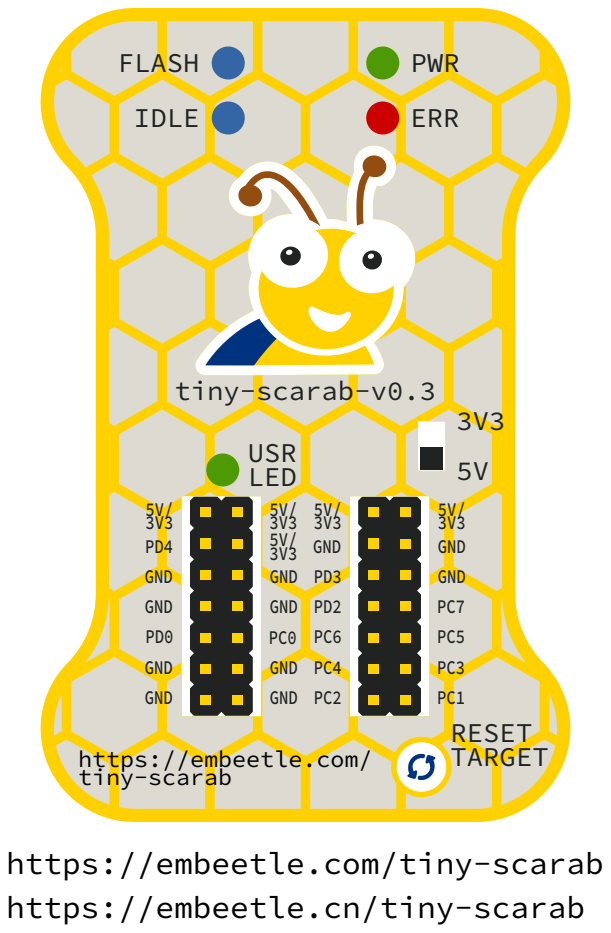
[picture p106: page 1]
RESET TARGET; USR LED; GND; 5V/ 3V3 GND; tiny-scarab-v0.3; IDLE

https://embeetle.com/
tiny-scarab

https://embeetle.com/tiny-scarab
https://embeetle.cn/tiny-scarab

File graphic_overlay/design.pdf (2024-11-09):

FLASH | PWR
| ERR

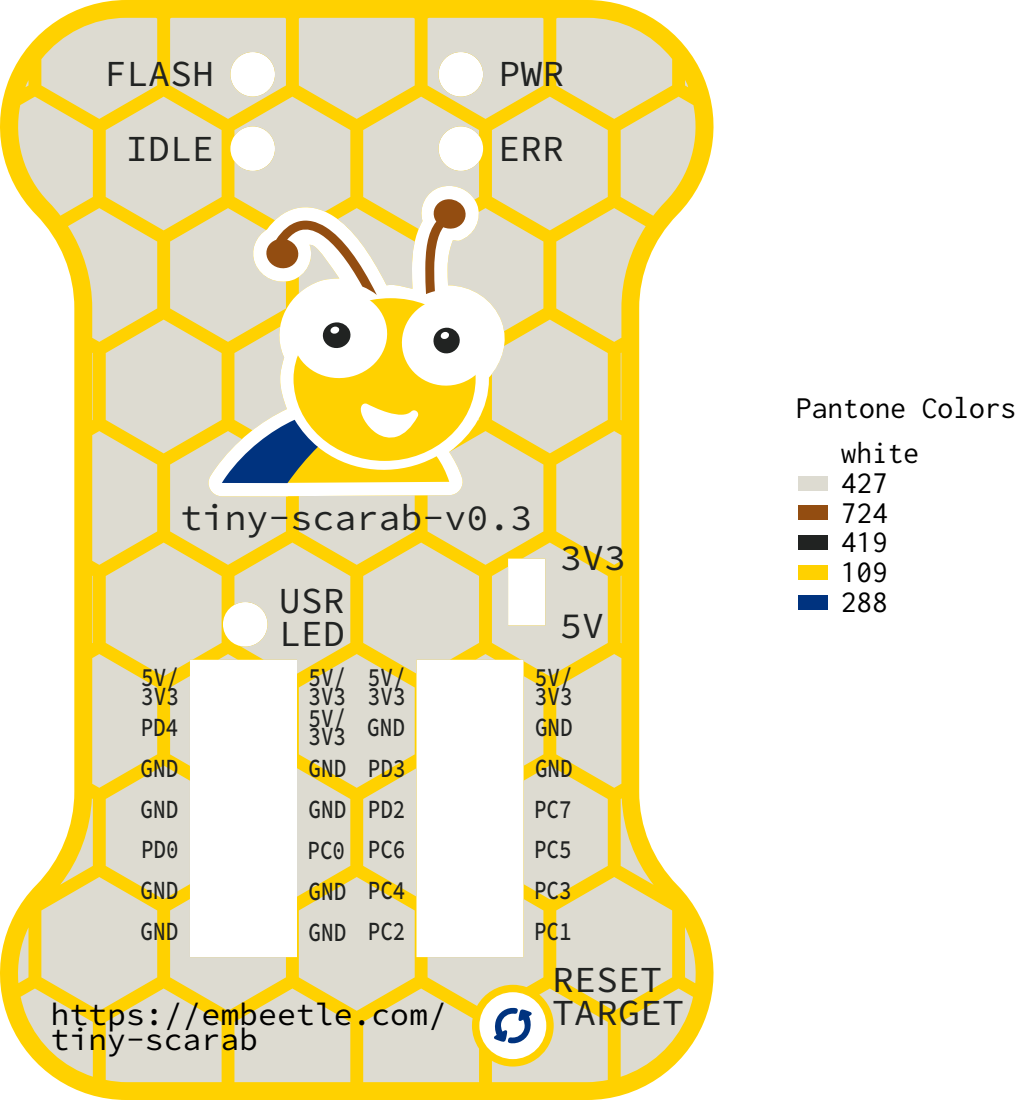
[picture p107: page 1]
RESET TARGET; USR LED; GND; 5V/ 3V3 GND; tiny-scarab-v0.3; IDLE; Pantone Colors white 427

https://embeetle.com/
tiny-scarab

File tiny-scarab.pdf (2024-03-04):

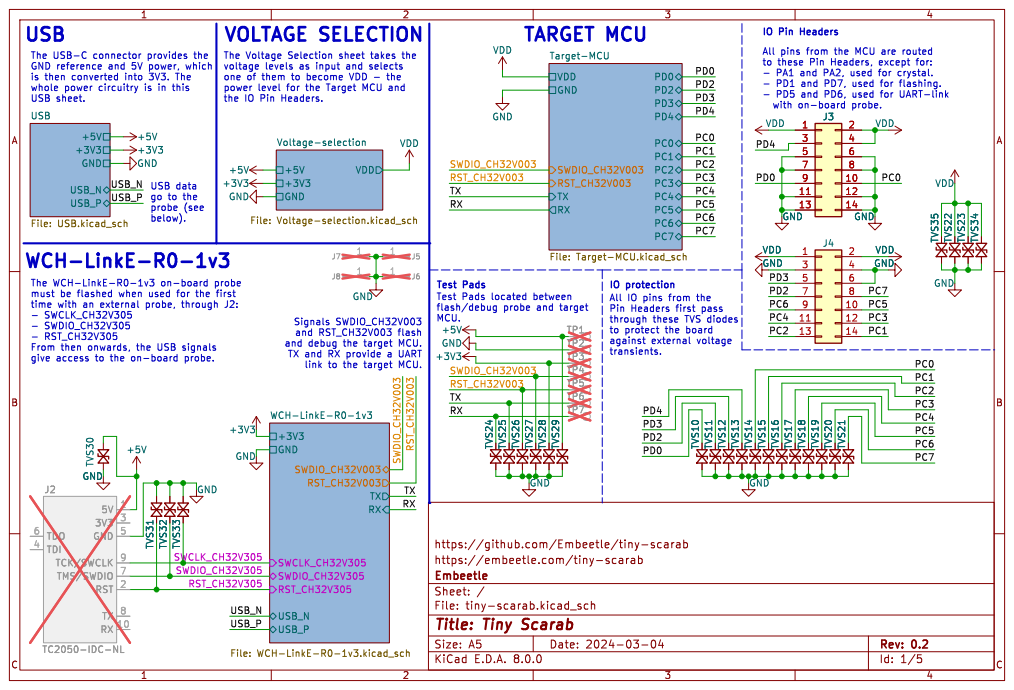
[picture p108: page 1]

+3V3 Voltage-selection File: Voltage-selection.kicad_sch SWCLK_CH32V305 SWDIO_CH32V305 RST_CH32V305 SWDIO_CH32V003 RST_CH32V003TXRX USB_N

voltage levels as input and selects one of them to become VDD - the

All pins from the MCU are routed

power level for the Target MCU and

the IO Pin Headers. USB data

+3V3 WCH-LinkE-R0-1v3 File: WCH-LinkE-R0-1v3.kicad_sch USB_N

IO protection
All IO pins from the Pin Headers first pass

Signals SWDIO_CH32V003
and RST_CH32V003 flash
and debug the target MCU. TX and RX provide a UART

through these TVS diodes
to protect the board
transients.

- SWDIO_CH32V305
- RST_CH32V305 From then onwards, the USB signals

https://github.com/Embeetle/tiny-scarab
https://embeetle.com/tiny-scarab
File: tiny-scarab.kicad_sch Sheet: / Embeetle

Id: 1/5 Title: Tiny Scarab

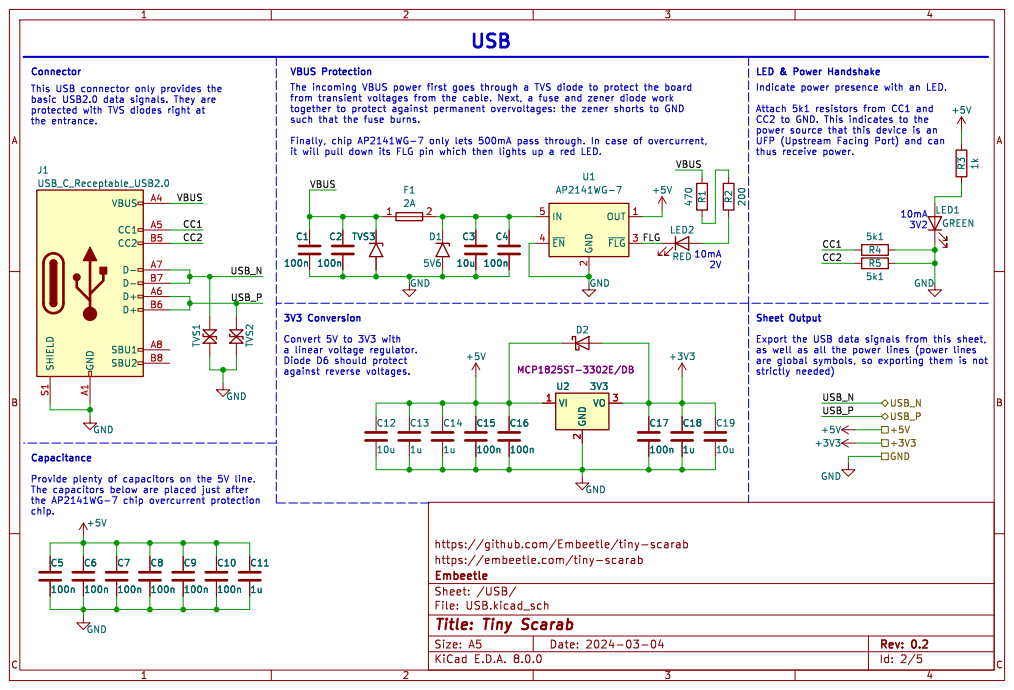
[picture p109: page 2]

VBUS Protection Convert 5V to 3V3 with

a linear voltage regulator. Diode D6 should protect against reverse voltages.

https://github.com/Embeetle/tiny-scarab C7

https://embeetle.com/tiny-scarab
File: USB.kicad_sch Sheet: /USB/ Embeetle

Id: 2/5 Title: Tiny Scarab

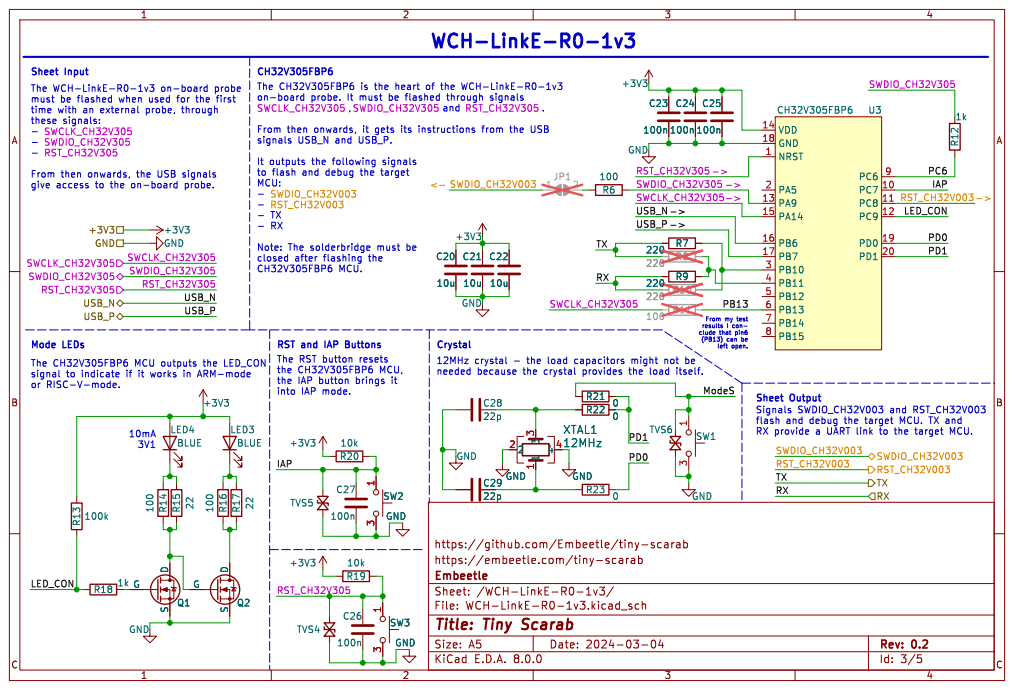
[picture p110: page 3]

to flash and debug the target MCU: -

the IAP button brings it

https://github.com/Embeetle/tiny-scarab R21

flash and debug the target MCU. TX and RX provide a UART link to the target MCU. 10mA

https://embeetle.com/tiny-scarab
File: WCH-LinkE-R0-1v3.kicad_sch Sheet: /WCH-LinkE-R0-1v3/ Embeetle

Id: 3/5 Title: Tiny Scarab

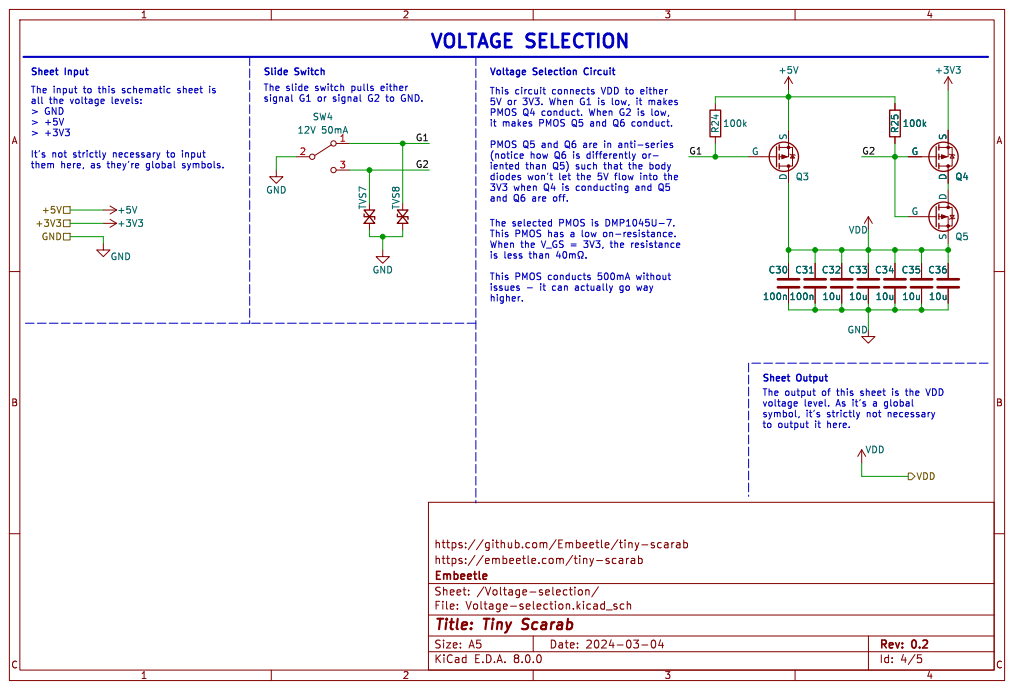
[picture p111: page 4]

Voltage Selection Circuit VOLTAGE SELECTION

it makes PMOS Q5 and Q6 conduct. PMOS Q5 and Q6 are in anti-series

iented than Q5) such that the body diodes won't let the 5V flow into the

Sheet Output The output of this sheet is the VDD

voltage level. As it's a global

https://embeetle.com/tiny-scarab
File: Voltage-selection.kicad_sch Sheet: /Voltage-selection/ Embeetle

Id: 4/5 Title: Tiny Scarab

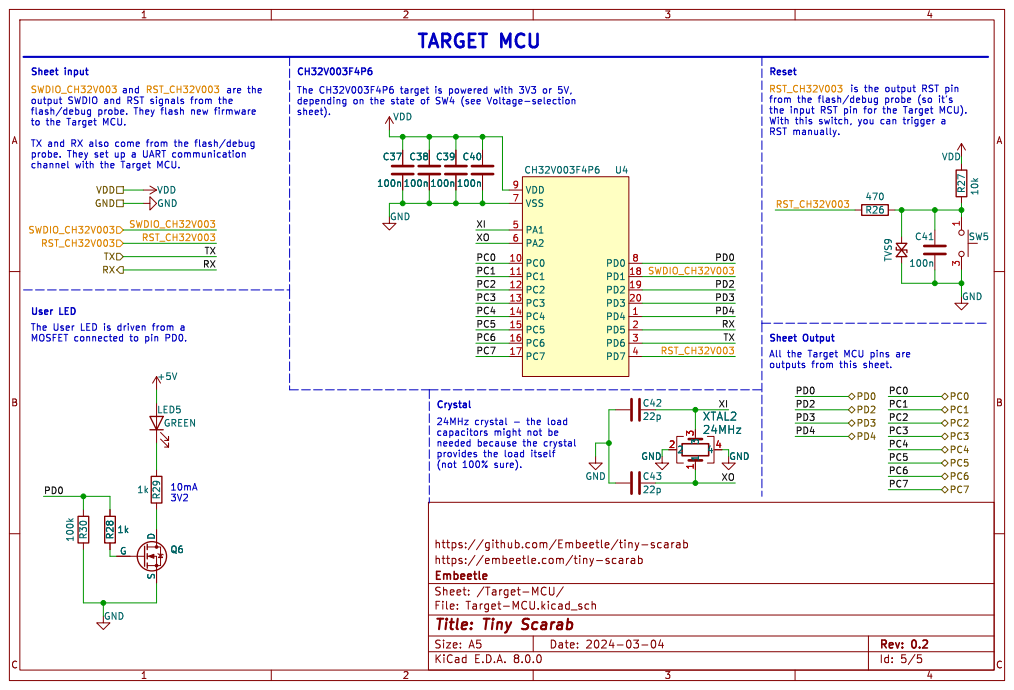
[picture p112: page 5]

output SWDIO and RST signals from the
to the Target MCU. TX and RX also come from the flash/debug
probe. They set up a UART communication

is the output RST pin

https://github.com/Embeetle/tiny-scarab C38

24MHz crystal - the load
needed because the crystal

https://embeetle.com/tiny-scarab
File: Target-MCU.kicad_sch Sheet: /Target-MCU/ Embeetle

Id: 5/5 Title: Tiny Scarab

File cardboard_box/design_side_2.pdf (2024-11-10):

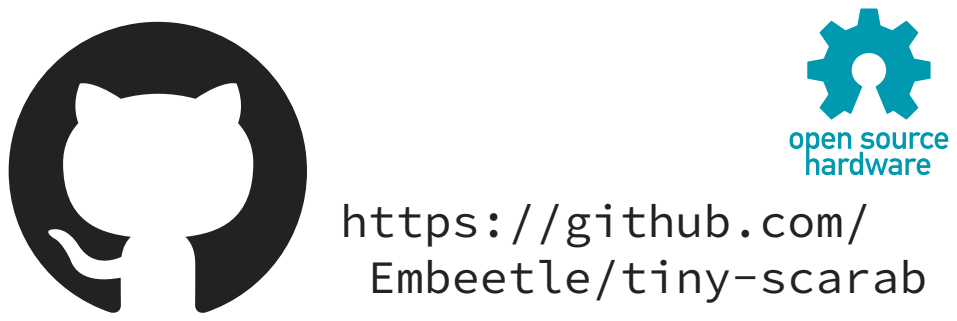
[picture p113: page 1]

https://github.com/
Embeetle/tiny-scarab

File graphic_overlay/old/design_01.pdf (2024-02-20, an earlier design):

FLASH | PWR

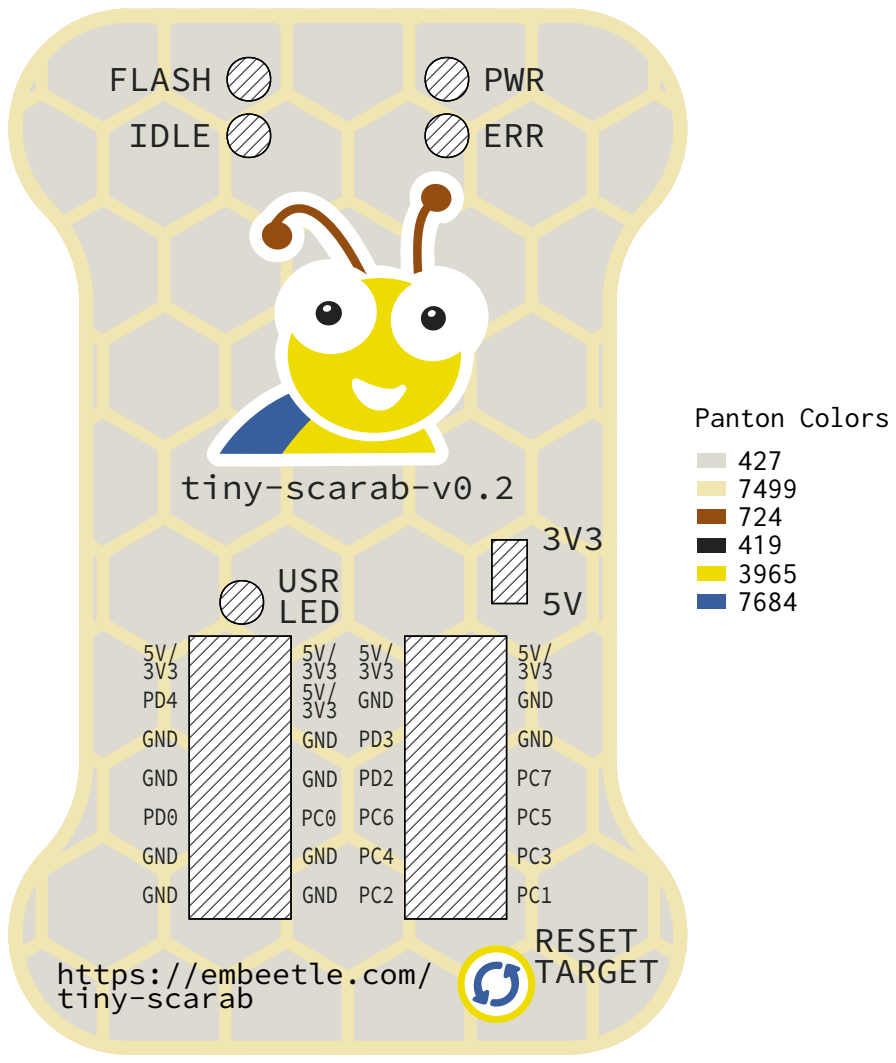
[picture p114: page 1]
RESET TARGET; ERR; USR LED; GND; 5V/ 3V3 GND; Panton Colors; tiny-scarab-v0.2; IDLE

https://embeetle.com/
tiny-scarab

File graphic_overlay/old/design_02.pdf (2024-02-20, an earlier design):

FLASH | PWR

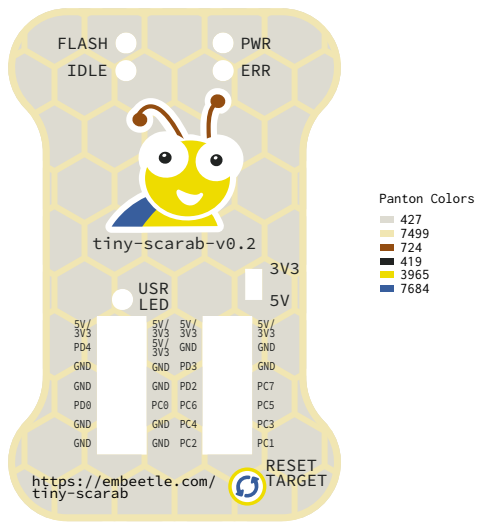
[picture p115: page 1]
RESET TARGET; ERR; USR LED; GND; 5V/ 3V3 GND; tiny-scarab-v0.2; IDLE; Panton Colors 427

https://embeetle.com/
tiny-scarab

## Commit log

2024-01-05 Version 0.1
    [USB.kicad_sch, WCH-LinkE-R0-1v3.kicad_sch, tiny-scarab.kicad_pcb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]
2024-01-09 Improve layout
    [USB.kicad_sch, WCH-LinkE-R0-1v3.kicad_sch, tiny-scarab.kicad_pcb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]
2024-01-14 Move silkscreen
    [tiny-scarab.kicad_pcb]
2024-01-15 Update design
    [WCH-LinkE-R0-1v3.kicad_sch, tiny-scarab.kicad_pcb, tiny-scarab.kicad_sch]
2024-01-15 Update layout
    [USB.kicad_sch, WCH-LinkE-R0-1v3.kicad_sch, tiny-scarab.kicad_pcb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]
2024-01-15 Add BOM files
    [tiny-scarab.csv]
2024-01-15 Generate gerber output
    [tiny-scarab-B_Cu.gbr, tiny-scarab-B_Mask.gbr, tiny-scarab-B_Paste.gbr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]
2024-01-15 Add firmware for flash/debug probe
2024-01-21 Prepare PCB for JLCPCB production
    [D_SOD-323-bidirectional.step, LED_0603_BLUE.step, LED_0603_GREEN.step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]
2024-01-21 Add schematic
2024-01-21 Update schematic
    [Target-MCU.kicad_sch]
2024-01-22 Renumber designators and draw new silkscreen
    [Target-MCU.kicad_sch, USB.kicad_sch, Voltage-selection.kicad_sch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]
2024-01-23 Change J3 and J4 part numbers
    [Target-MCU.kicad_sch, WCH-LinkE-R0-1v3.kicad_sch, tiny-scarab.kicad_pcb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]
2024-01-25 Change silkscreen
    [tiny-scarab.kicad_pcb, tiny-scarab.kicad_sch]
2024-01-28 Replace TVS diodes with cheaper alternative
    [SOD-882.step, Target-MCU.kicad_sch, USB.kicad_sch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]
2024-01-30 Clean up symbols library
    [Target-MCU.kicad_sch, USB.kicad_sch, Voltage-selection.kicad_sch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]
2024-01-30 Prefix each symbol name in library - eg. 'D_', 'CONN_', 'IC_', ...
    [Target-MCU.kicad_sch, USB.kicad_sch, Voltage-selection.kicad_sch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]
2024-01-30 Clean up footprints
    [tiny-scarab.kicad_pcb]
2024-01-30 Rename net 'RST_OUT' into 'RST_CH32V003'
    [Target-MCU.kicad_sch, WCH-LinkE-R0-1v3.kicad_sch, tiny-scarab.kicad_pcb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]
2024-01-30 Rename net 'RST_IN' into 'RST_CH32V305'
    [Target-MCU.kicad_sch, WCH-LinkE-R0-1v3.kicad_sch, tiny-scarab.kicad_pcb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]
2024-01-30 Update footprint library fields
    [tiny-scarab.kicad_pcb]
2024-01-30 Rename net 'SWDIO_IN' into 'SWDIO_CH32V305'
    [WCH-LinkE-R0-1v3.kicad_sch, tiny-scarab.kicad_pcb, tiny-scarab.kicad_sch]
2024-01-30 Rename net 'SWCLK_IN' into 'SWCLK_CH32V305'
    [WCH-LinkE-R0-1v3.kicad_sch, tiny-scarab.kicad_pcb, tiny-scarab.kicad_sch]
2024-01-30 Schematic cleanup
    [Target-MCU.kicad_sch, USB.kicad_sch, Voltage-selection.kicad_sch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]
2024-01-31 Apply suggestions from Petr Dvorak
    [Target-MCU.kicad_sch, USB.kicad_sch, WCH-LinkE-R0-1v3.kicad_sch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]
2024-01-31 Export schematic to pdf
2024-02-01 Rename capacitors
    [Target-MCU.kicad_sch, USB.kicad_sch, Voltage-selection.kicad_sch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]
2024-02-01 Add production files
    [Target-MCU.kicad_sch, USB.kicad_sch, bom.csv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]
2024-02-04 Add Fusion 360 files for enclosure|
    [tiny-scarab-cover v18.f3d, tiny-scarab-cover v18.step, tiny-scarab-enclosure v18.f3d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]
2024-02-14 Update parts
    [K2-1109SP-A4SA-04.f3d, K2-1109SP-A4SA-04.step, K2-1109SP-I4SA-04.f3d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]
2024-02-16 Work on Graphic Overlay Membrane
    [WCH-LinkE-R0-1v3.kicad_sch, board_cutout_4mm_offset.dxf, drawing.dxf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]
2024-02-18 Let USB connector stick out 4mm
    [tiny-scarab-v0.2-cover-simplified.f3d, tiny-scarab-v0.2-cover-simplified.step, tiny-scarab.kicad_pcb]
2024-02-18 Rework enclosure for USB connector sticking out
    [tiny-scarab-v0.2-board.f3d, tiny-scarab-v0.2-cover-simplified.f3d, tiny-scarab-v0.2-cover-simplified.step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]
2024-02-19 Work on BOM
    [Target-MCU.kicad_sch, USB.kicad_sch, WCH-LinkE-R0-1v3.kicad_sch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]
2024-02-19 Modify resistors for LEDs
    [Target-MCU.kicad_sch, USB.kicad_sch, Voltage-selection.kicad_sch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]
2024-02-20 Update graphical overlay
    [bom.xlsx]
2024-02-21 Rename 'modify_designators.py' into 'kicad_designators.py'
    [Target-MCU.kicad_sch, USB.kicad_sch, Voltage-selection.kicad_sch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]
2024-02-21 Update 'kicad_designators.py'
2024-03-02 Adapt project to KiCAD 8
    [4mm_offset.dxf, Target-MCU.kicad_sch, USB.kicad_sch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]
2024-03-04 Apply JLCPCB rotations and offsets to components
    [Target-MCU.kicad_sch, USB.kicad_sch, Voltage-selection.kicad_sch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]
2024-04-03 My hands are typing words
    [USB.kicad_sch, bom.xlsx, positions.csv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]
2024-11-06 Migrate to KiCAD 8.0.6
    [tiny-scarab.kicad_pcb]
2024-11-06 Upgrade to v0.3 and add new LEDs
    [LED_D3.0mm.step, LED_D3.0mm_spacer_blue.step, LED_D3.0mm_spacer_green.step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]
2024-11-07 Insert blue LEDs
    [Target-MCU.kicad_sch, USB.kicad_sch, Voltage-selection.kicad_sch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]
2024-11-07 Insert green and red LED
    [USB.kicad_sch, WCH-LinkE-R0-1v3.kicad_sch, tiny-scarab.kicad_pcb]
2024-11-07 Add user LED
    [Target-MCU.kicad_sch, tiny-scarab.kicad_pcb]
2024-11-09 Upgrade enclosure and membrane files
    [4mm_offset.dxf, WCH-LinkE-R0-1v3.kicad_sch, board_cutout_4mm_offset.dxf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]
2024-11-09 Replace 24MHz crystal `M24000J054` with `L327S240V11L`
    [Target-MCU.kicad_sch, tiny-scarab.kicad_pcb]
2024-11-09 Replace TVS `CDSOD323-T05LC` with `RLSD32A051LC`
    [USB.kicad_sch, tiny-scarab.kicad_pcb, tiny-scarab.kicad_sch]
2024-11-09 Replace TVS `SP1007-01ETG` with `LESD8LH5.0CT5G`
    [Target-MCU.kicad_sch, Voltage-selection.kicad_sch, WCH-LinkE-R0-1v3.kicad_sch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]
2024-11-09 Fix R28
    [Target-MCU.kicad_sch]
2024-11-09 Set hole diameter of 3mm LEDs to 0.8mm
    [tiny-scarab.kicad_pcb]
2024-11-09 Update production files
    [bom.csv, tiny-scarab.kicad_pcb]
2024-11-09 Make hole in enclosure deeper
    [tiny-scarab-v0.3-enclosure.f3z, tiny-scarab-v0.3-enclosure.step, tiny-scarab-v0.3-total.f3z]
2024-11-10 Make LED holes 0.7mm
    [tiny-scarab.kicad_pcb]
2024-11-30 Update production files and documentation
    [bom.csv, bom.xlsx]
